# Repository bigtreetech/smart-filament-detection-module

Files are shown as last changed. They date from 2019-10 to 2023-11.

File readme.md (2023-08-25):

## BigTreeTech SFS V1.0

### Firmware Config for `Filament blockage detection`
  * Marlin
    1. uncomment `#define FILAMENT_RUNOUT_SENSOR`.<br/>
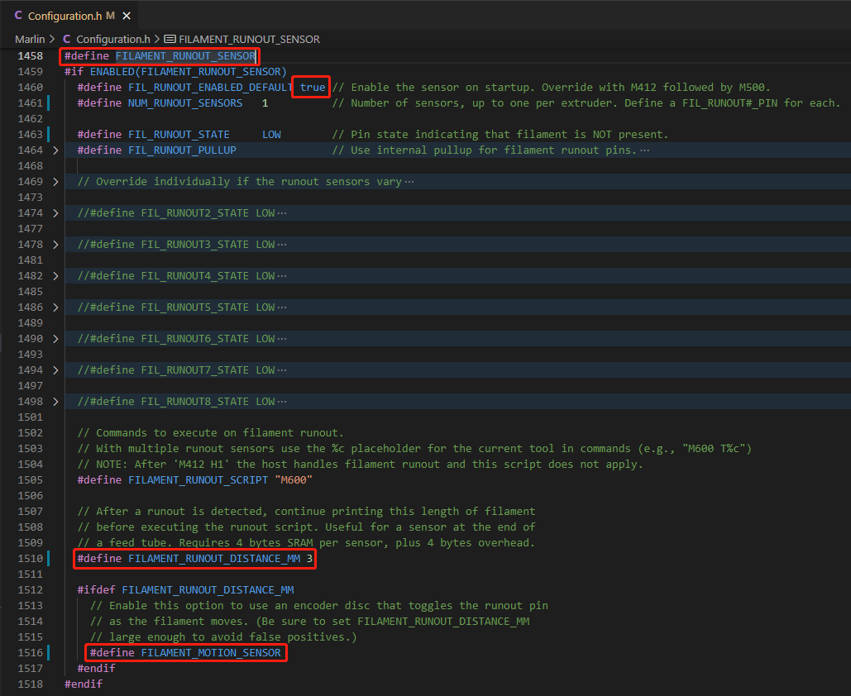
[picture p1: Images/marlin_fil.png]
       <br/>
    2. uncomment `#define FILAMENT_RUNOUT_DISTANCE_MM 7` and set it to 7mm (The detection accuracy of SFS V1.0 is 7mm).
    3. uncomment `#define FILAMENT_MOTION_SENSOR`
    4. The filament sensor feature of Marlin also needs to enable `#define NOZZLE_PARK_FEATURE` and `#define ADVANCED_PAUSE_FEATURE`. please uncomment `#define NOZZLE_PARK_FEATURE` and `#define ADVANCED_PAUSE_FEATURE` and set specific parameters according to your printer.
    5. If you are using the Serial Touch Screen of BigTreeTech, please enable the features in Marlin according to the requirements [here](https://github.com/bigtreetech/BIGTREETECH-TouchScreenFirmware#marlin-dependencies)
        * We recommended to plug SFS V1.0 into the motherboard not Touch Screen, In this case, the Marlin configuration is as described above, and the Touch Screen `config.ini` file needs to be set according to [here](https://github.com/bigtreetech/BIGTREETECH-TouchScreenFirmware/blob/f7ccb050a7a2fe78ff5204561113fa0d27b0dd10/Copy%20to%20SD%20Card%20root%20directory%20to%20update/c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)
        * When the SFS V1.0 is plugged into the Touch Screen, comment out `#define FILAMENT_RUNOUT_SENSOR` in Marlin to disable detection of Marlin and uncomment `#define M114_DETAIL` for Touch Screen, And enable detection of Touch Screen in `config.ini` file, set `fil_runout:1` to enable detection and `fil_runout_distance:7` for accuracy.
  * RepRapFirmware
    1. Add `M591 D0 P7 C"zstopmax" L7 R75:125 E22 S1` in `config.g`, changing the endstop pin name according to your motherboard.<br/>
    ***If you are using the Serial Touch Screen of BigTreeTech, The SFS V1.0 of RRF can only be plugged into the motherboard, and Touch Screen does not need additional config for SFS V1.0***
  * Klipper
    ```
    [filament_motion_sensor encoder_sensor]
    detection_length: 7
    #   The minimum length of filament pulled through the sensor to trigger
    #   a state change on the switch_pin
    #   Default is 7 mm.
    extruder: extruder
    #   The name of the extruder section this sensor is associated with.
    #   This parameter must be provided.
    switch_pin: PA9
    # changing the switch_pin name according to your motherboard
    #pause_on_runout: True
    #runout_gcode:
    #insert_gcode:
    #event_delay:
    #pause_delay:
    ```

## BigTreeTech SFS V2.0

### Firmware Config for `Filament blockage detection`
  * Marlin
    1. uncomment `#define FILAMENT_RUNOUT_SENSOR`.<br/>
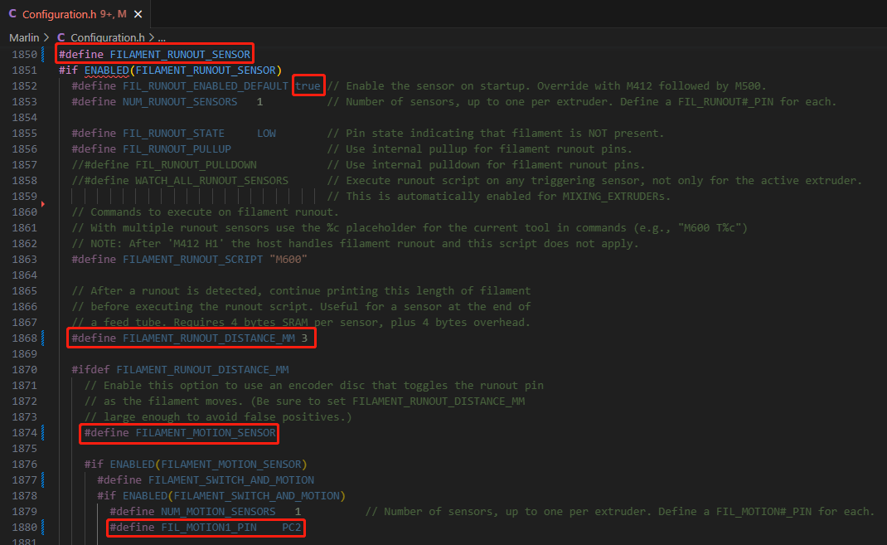
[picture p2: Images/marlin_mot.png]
       <br/>
    2. uncomment `#define FILAMENT_RUNOUT_DISTANCE_MM 3` and set it to 3mm (The detection accuracy of SFS V2.0 is 2.88mm, We set it to 3mm to leave some error margin).
    3. uncomment `#define FILAMENT_MOTION_SENSOR`
    4. uncomment `#define FILAMENT_SWITCH_AND_MOTION`
    5. uncomment `#define FIL_MOTION1_PIN gpio_xx` set motion pin to actual GPIO of motherboard
    6. The filament sensor feature of Marlin also needs to enable `#define NOZZLE_PARK_FEATURE` and `#define ADVANCED_PAUSE_FEATURE`. please uncomment `#define NOZZLE_PARK_FEATURE` and `#define ADVANCED_PAUSE_FEATURE` and set specific parameters according to your printer.
    7. If you are using the Serial Touch Screen of BigTreeTech, please enable the features in Marlin according to the requirements [here](https://github.com/bigtreetech/BIGTREETECH-TouchScreenFirmware#marlin-dependencies)
        * We recommended to plug SFS V2.0 into the motherboard not Touch Screen, In this case, the Marlin configuration is as described above, and the Touch Screen `config.ini` file needs to be set according to [here](https://github.com/bigtreetech/BIGTREETECH-TouchScreenFirmware/blob/f7ccb050a7a2fe78ff5204561113fa0d27b0dd10/Copy%20to%20SD%20Card%20root%20directory%20to%20update/c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)
        * When the SFS V2.0 is plugged into the Touch Screen, comment out `#define FILAMENT_RUNOUT_SENSOR` in Marlin to disable detection of Marlin and uncomment `#define M114_DETAIL` for Touch Screen, And enable detection of Touch Screen in `config.ini` file, set `fil_runout:1` to enable detection and `fil_runout_distance:3` for accuracy.
  * RepRapFirmware
    1. Add `M591 D0 P7 C"zstopmax" L2.88 R75:125 E9 S1` in `config.g`, changing the endstop pin name according to your motherboard.<br/>
    ***If you are using the Serial Touch Screen of BigTreeTech, The SFS V2.0 of RRF can only be plugged into the motherboard, and Touch Screen does not need additional config for SFS V2.0***
  * Klipper
    ```
    [filament_switch_sensor switch_sensor]
    switch_pin: gpio_xx
    pause_on_runout: False
    runout_gcode:
      PAUSE # [pause_resume] is required in printer.cfg
      M117 Filament switch runout
    insert_gcode:
      M117 Filament switch inserted

    [filament_motion_sensor encoder_sensor]
    switch_pin: gpio_xx
    detection_length: 2.88
    extruder: extruder
    pause_on_runout: False
    runout_gcode:
      PAUSE # [pause_resume] is required in printer.cfg
      M117 Filament encoder runout
    insert_gcode:
      M117 Filament encoder inserted
    ```

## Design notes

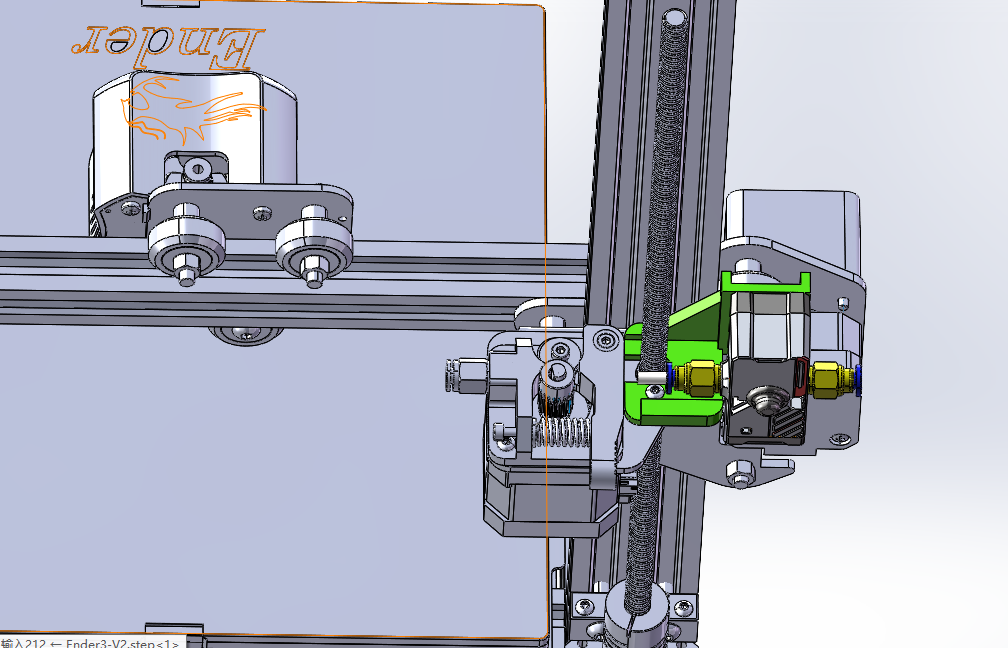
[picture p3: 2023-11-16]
V2.0/Community Mods/Ender3 V2/SFS V2.0 Bracket for Ender3 V2.png

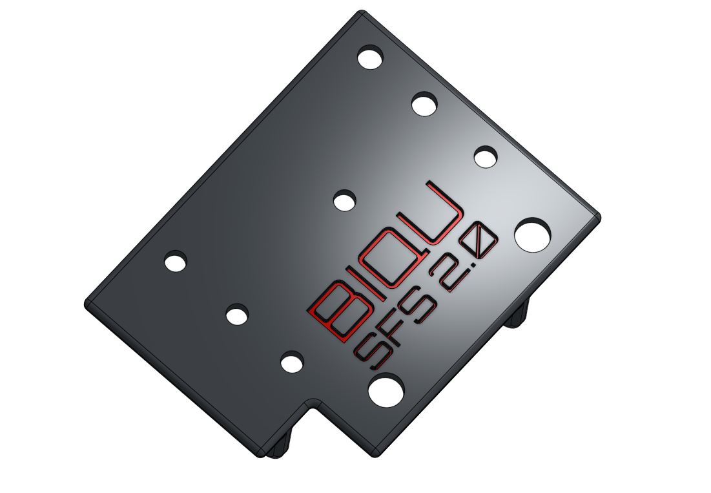
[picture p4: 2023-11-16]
V2.0/Community Mods/Ender3 Max/SFS V2.0 Bracket for Ender3 Max -Pic(4).jpg

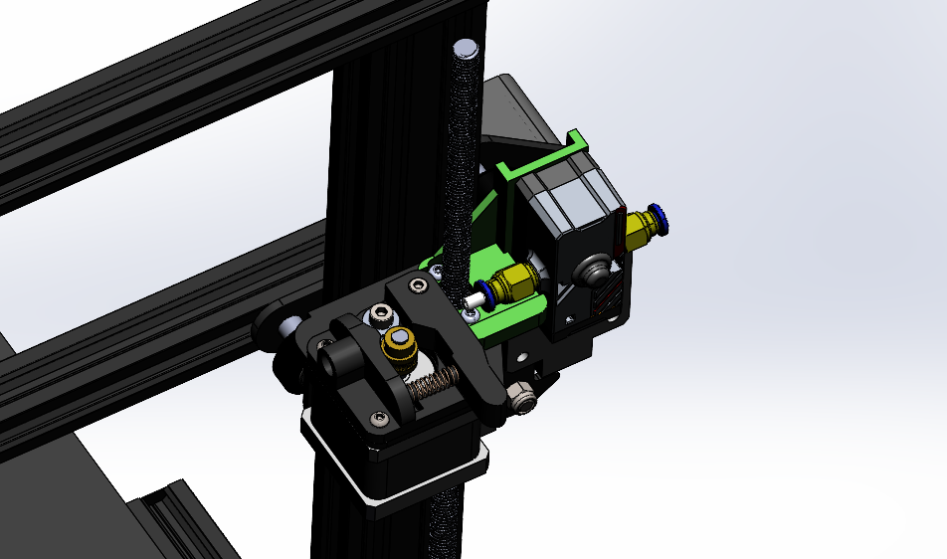
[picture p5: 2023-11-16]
V2.0/Community Mods/Ender3 V1/SFS V2.0 Bracket for Ender3 V1.png

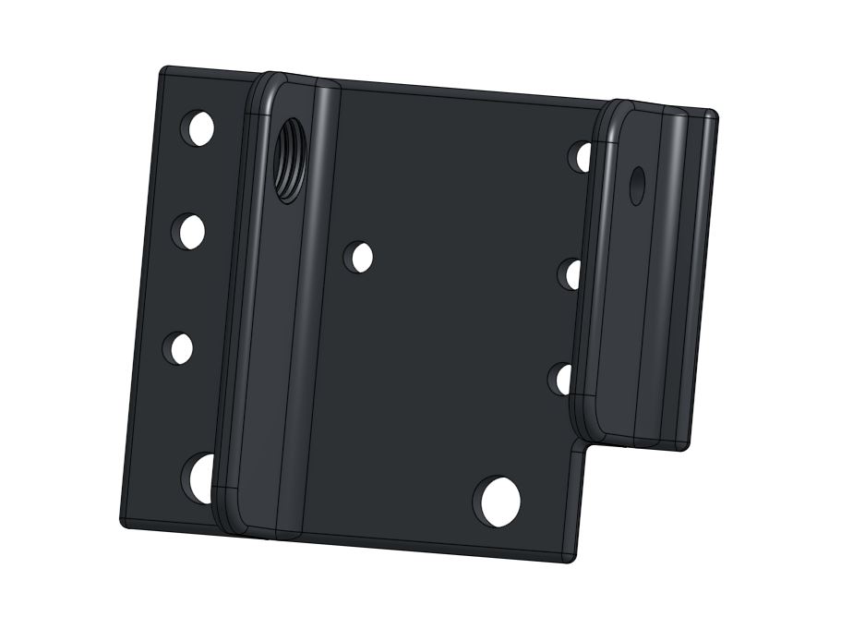
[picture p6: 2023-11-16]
V2.0/Community Mods/Ender3 Max/SFS V2.0 Bracket for Ender3 Max -Pic(1).jpg

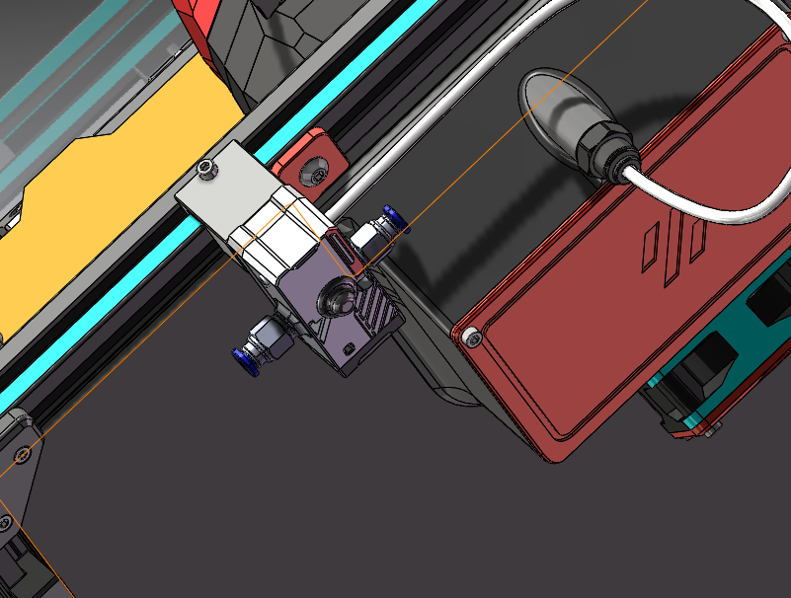
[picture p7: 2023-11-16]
V2.0/Community Mods/Voron2.4/SFS V2.0 Bracket for Voron2.4.png

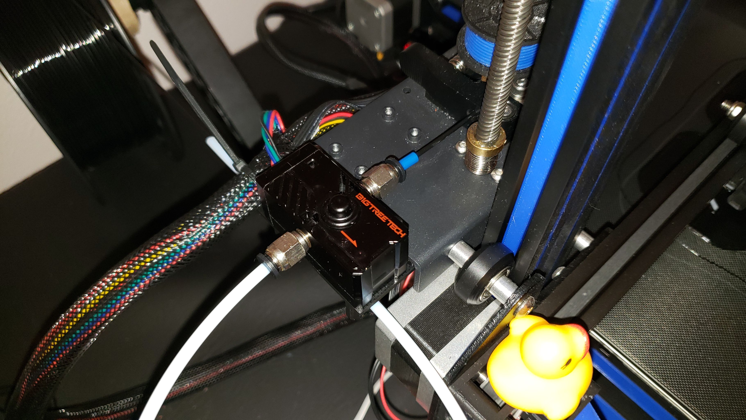
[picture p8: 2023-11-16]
V2.0/Community Mods/Ender3 Max/SFS V2.0 Bracket for Ender3 Max -Pic(3).jpg

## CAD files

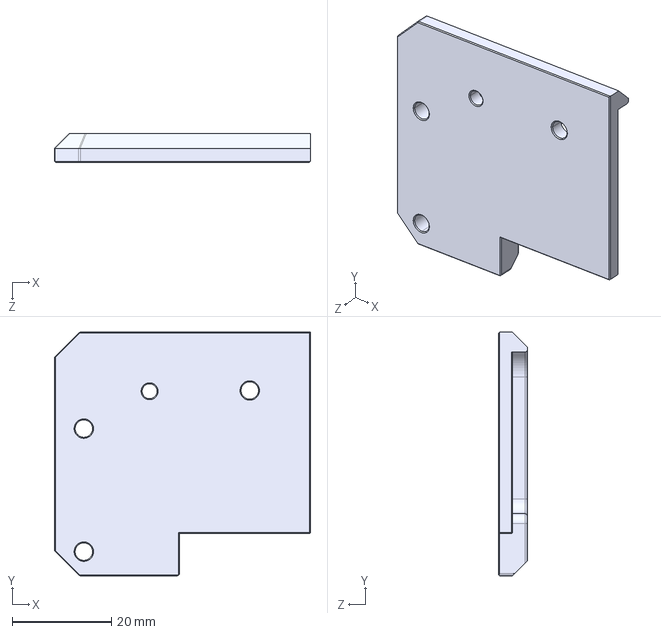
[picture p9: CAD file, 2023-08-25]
V2.0/CAD/SFS V2.0 Bracket for Hurakan.STEP
51.5 x 49.0 x 5.80 mm

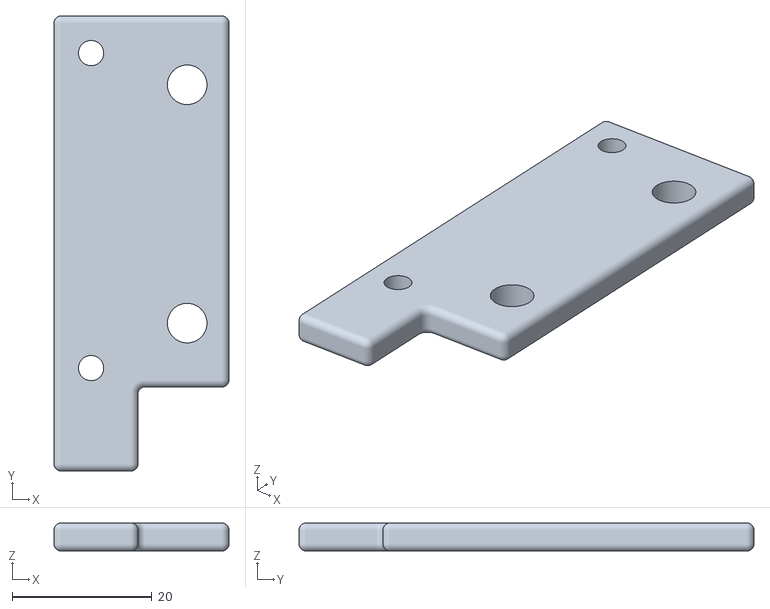
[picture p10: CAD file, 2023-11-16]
V2.0/Community Mods/Ender3 Max/SFS V2.0 Mount-Spacer for Ender3 Max.stl
25.0 x 65.0 x 4.00

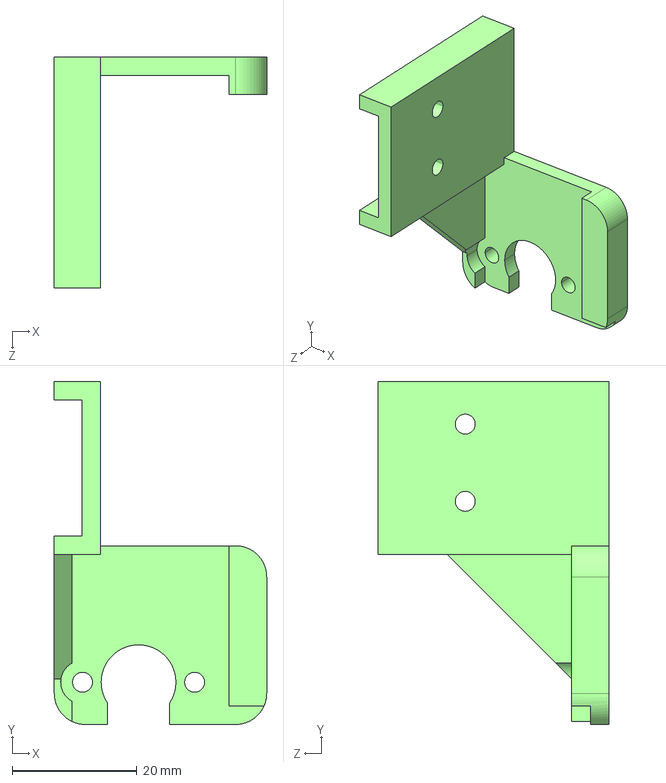
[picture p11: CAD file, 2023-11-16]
V2.0/Community Mods/Ender3 V1/SFS V2.0 Bracket for Ender3 V1.STEP
34.1 x 55.1 x 37.1 mm

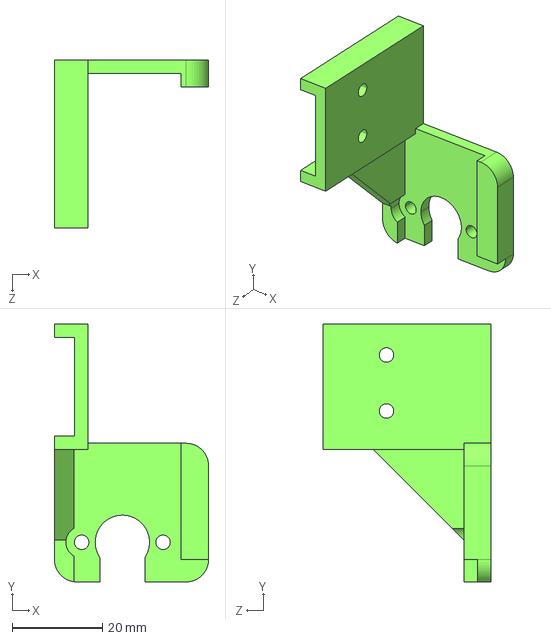
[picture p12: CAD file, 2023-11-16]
V2.0/Community Mods/Ender3 V2/SFS V2.0 Bracket for Ender3 V2.STEP
34.1 x 57.1 x 37.1 mm

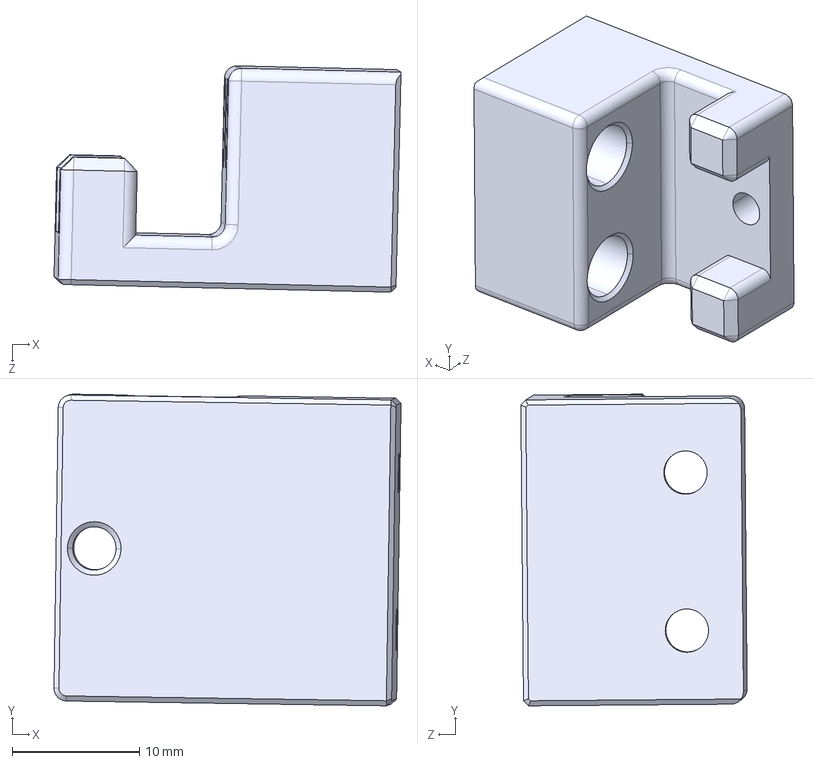
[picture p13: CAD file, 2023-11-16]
V2.0/Community Mods/Voron2.4/SFS V2.0 Bracket for Voron2.4.STEP
27.2 x 24.4 x 17.8 mm

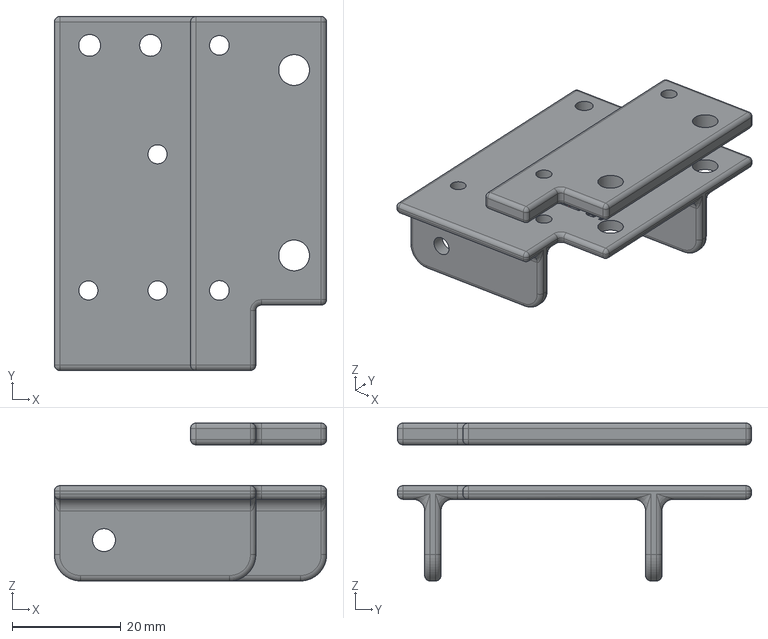
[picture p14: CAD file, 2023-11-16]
V2.0/Community Mods/Ender3 Max/SFS V2.0 Mount for Ender3 Max.step
50.0 x 65.0 x 29.0 mm

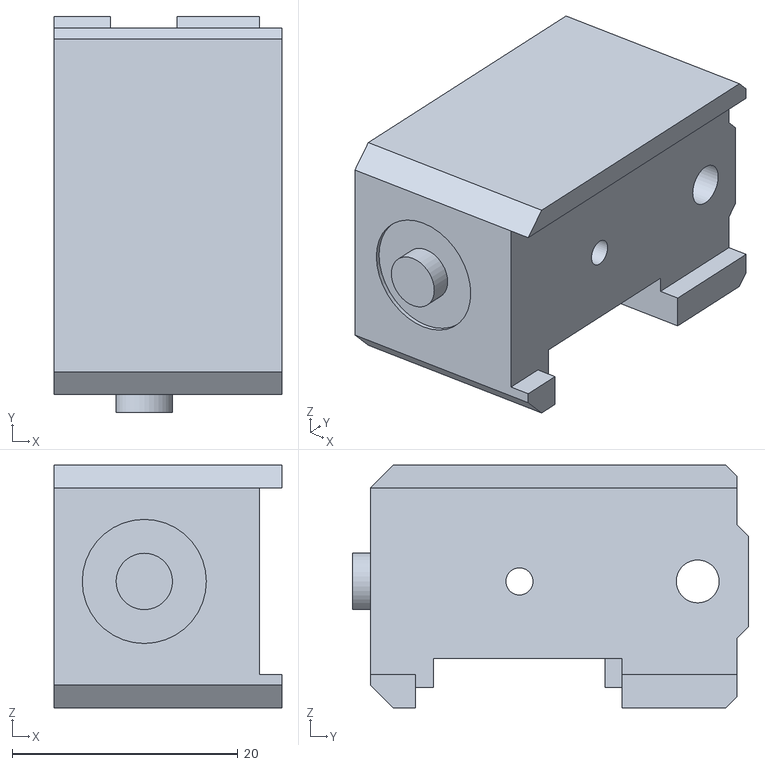
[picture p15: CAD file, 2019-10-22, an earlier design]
V1.0/STL/智能耗材检测模块-滑块1018.STL
20.2 x 35.1 x 21.5

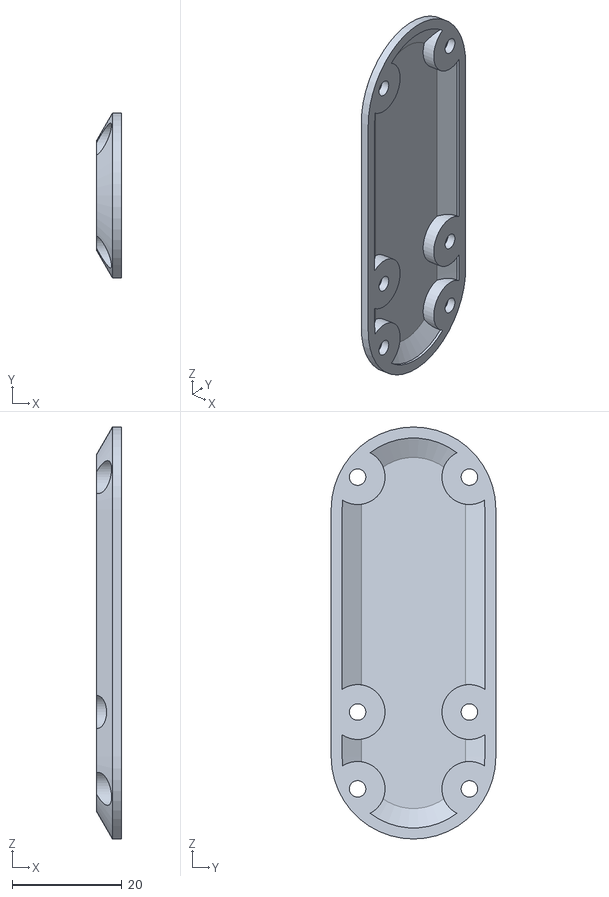
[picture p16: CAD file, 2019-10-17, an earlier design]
V1.0/STL/智能耗材检测模块-底盖0729.STL
4.55 x 30.0 x 75.0

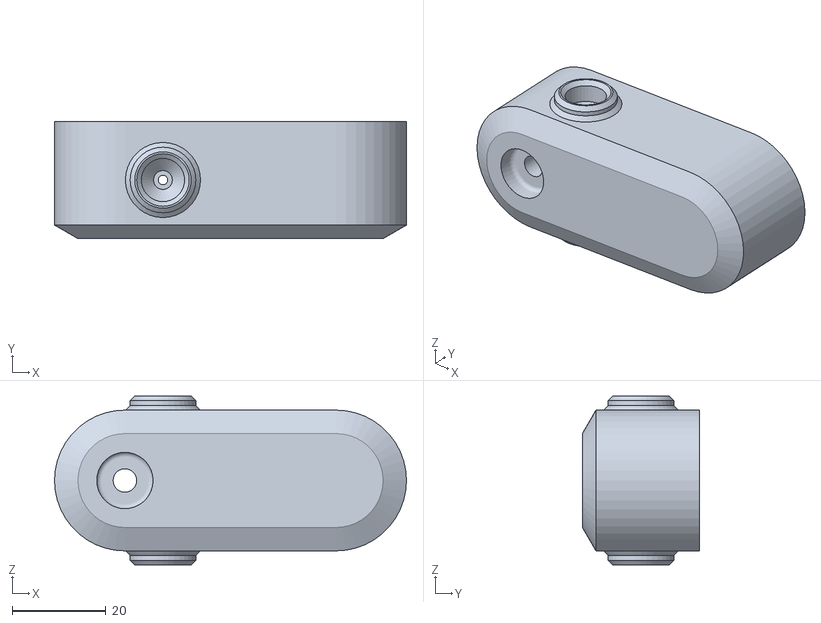
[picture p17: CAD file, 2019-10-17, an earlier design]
V1.0/STL/智能耗材检测模块-外壳0918.STL
75.0 x 25.0 x 36.0

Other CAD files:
V2.0/Community Mods/Ender3 V1/SFS V2.0 Bracket for Ender3 V1.STL
V2.0/Community Mods/Ender3 V2/SFS V2.0 Bracket for Ender3 V2.STL
V2.0/Community Mods/Voron2.4/SFS V2.0 Bracket for Voron2.4.STL
V2.0/STL/SFS V2.0 Bracket for Hurakan.STL

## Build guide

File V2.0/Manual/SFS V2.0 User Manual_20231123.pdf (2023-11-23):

# SFS V2.0

# User Manual

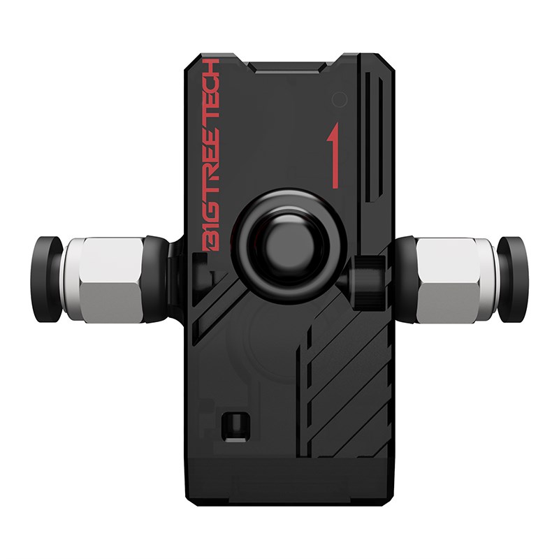
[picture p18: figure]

BIGTREETECH SFS V2.0 User Manual

2

## Revision Log

Version | Date | Revisions
v1.00 | 10th February 2023 | Initial Version
v1.10 | 16th November | 1. Wiring diagrams and Klipper
| 2023 | configuration instructions have been
added for the following boards:

Octopus V1.1/Pro V1.0.1/Pro V1.1/MAX EZ

SKR MINI E3 V3.0

MANTA E3EZ/M5P/M8P V1.0, V2.0

2. The Calibration guide has been added.

3

## CONTENTS

4

## Product Profile

SFS V2.0 is a smart filament sensor that enhances 3D printing reliability by leveraging a highly accurate photoelectric sensor to detect problematic filament issues like runout, tying, and clogging.

Feature Highlights

1. The SFS V2.0 is bi-directional, there is no restriction on filament direction, giving the users more flexibility during installation.
2. It detects extrusion errors caused by filament runout, nozzle clogging, filament tying, and extruder trouble. It has two signal outputs and indicator lights to distinguish between clogging or filament runout.
3. Works with Marlin, Klipper, and RRF firmware.
4. Compact, lightweight, and easy to install.
5. Works with Bowden extruders and direct-drive extruders.
6. Support motherboards with available endstop ports or dedicated filament runout ports.

Instruction

The filament can be threaded through either side of the SFS V2.0, as directionality does not affect functionality.

The red light will illuminate when there is no filament in the module.

The blue light will flash when the extrusion is normal.

The blue light will stay on or off when there is no extrusion.

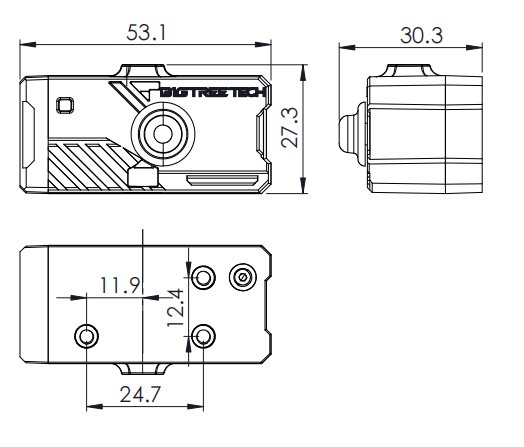
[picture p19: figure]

5

## Specifications

Dimensions: 53.1 x 30.3 x 27.3 mm

Weight: 36 g

Rated Voltage: 3.3V-5V

Working Temperature: -10 to 50 ℃

Working Humidity: 10% to 90%

Filament Diameter: 1.75mm

Mounting Hole Spacing: 12.4 x 24.7 mm

Detection Length: 2.88 mm (theoretical detection length, may need adjustment)

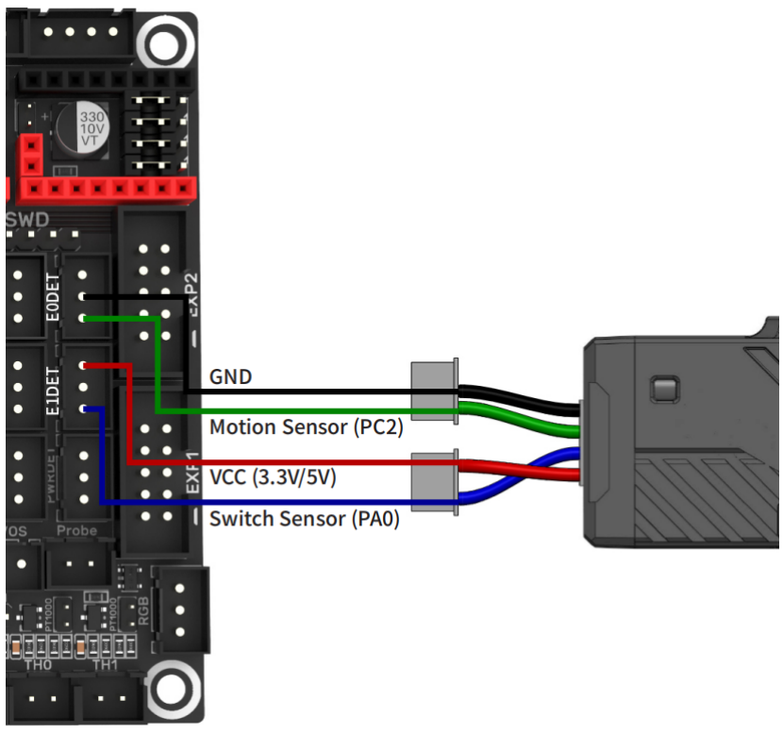
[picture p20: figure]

6

## Wiring

The SFS V2.0 uses a splitting cable, the 3-pin connectors plug into the

motherboard, and the 4-pin connector plugs into the SFS V2.0.

SFS V2.0+SKR3

[filament_switch_sensor switch_sensor] switch_pin: ^PA0
pause_on_runout: False
runout_gcode:
PAUSE # [pause_resume] is required in printer.cfg M117 Filament switch runout
insert_gcode:
M117 Filament switch inserted

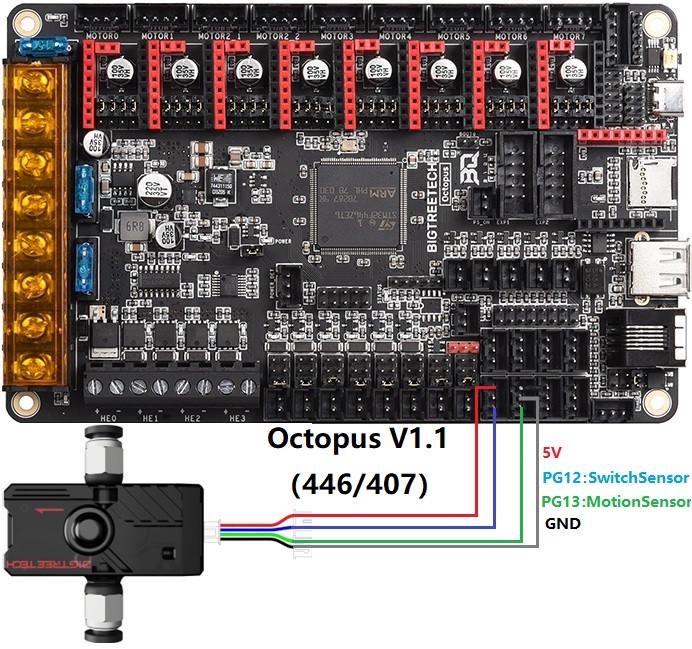
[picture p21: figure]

7

[filament_motion_sensor encoder_sensor]
switch_pin: ^PC2
detection_length: 2.88 # accuracy of motion sensor 2.88mm extruder: extruder
pause_on_runout: False
runout_gcode:
PAUSE # [pause_resume] is required in printer.cfg M117 Filament encoder runout
insert_gcode:
M117 Filament encoder inserted

SFS V2.0+Octopus V1.1

8

[filament_switch_sensor switch_sensor] switch_pin: ^PG12
pause_on_runout: False
runout_gcode:
PAUSE # [pause_resume] is required in printer.cfg M117 Filament switch runout
insert_gcode:
M117 Filament switch inserted

[filament_motion_sensor encoder_sensor]
switch_pin: ^PG13
detection_length: 2.88 # accuracy of motion sensor 2.88mm extruder: extruder
pause_on_runout: False
runout_gcode:
PAUSE # [pause_resume] is required in printer.cfg M117 Filament encoder runout
insert_gcode:
M117 Filament encoder inserted

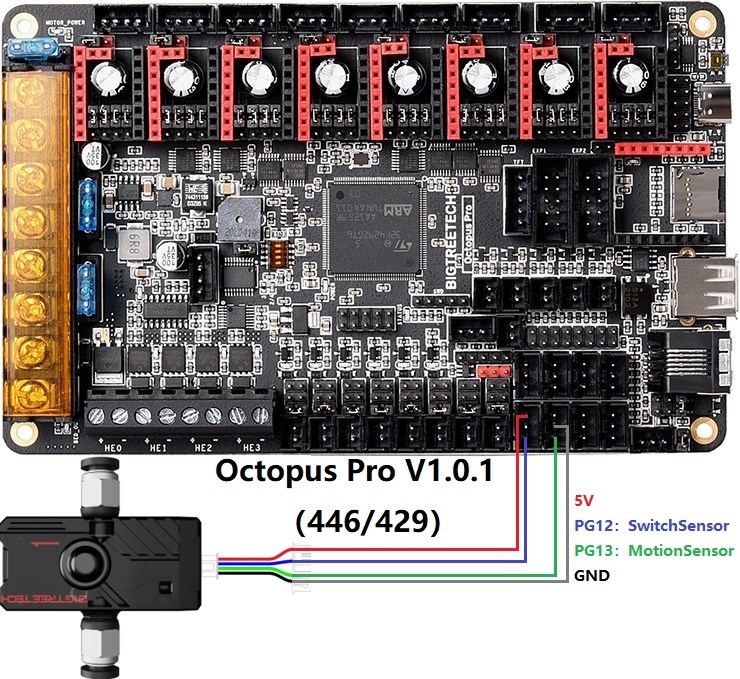
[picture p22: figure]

9

SFS V2.0+Octopus Pro V1.0.1

[filament_switch_sensor switch_sensor] switch_pin: ^PG12
pause_on_runout: False
runout_gcode:
PAUSE # [pause_resume] is required in printer.cfg M117 Filament switch runout
insert_gcode:
M117 Filament switch inserted

[filament_motion_sensor encoder_sensor]
switch_pin: ^PG13
detection_length: 2.88 # accuracy of motion sensor 2.88mm extruder: extruder
pause_on_runout: False
runout_gcode:

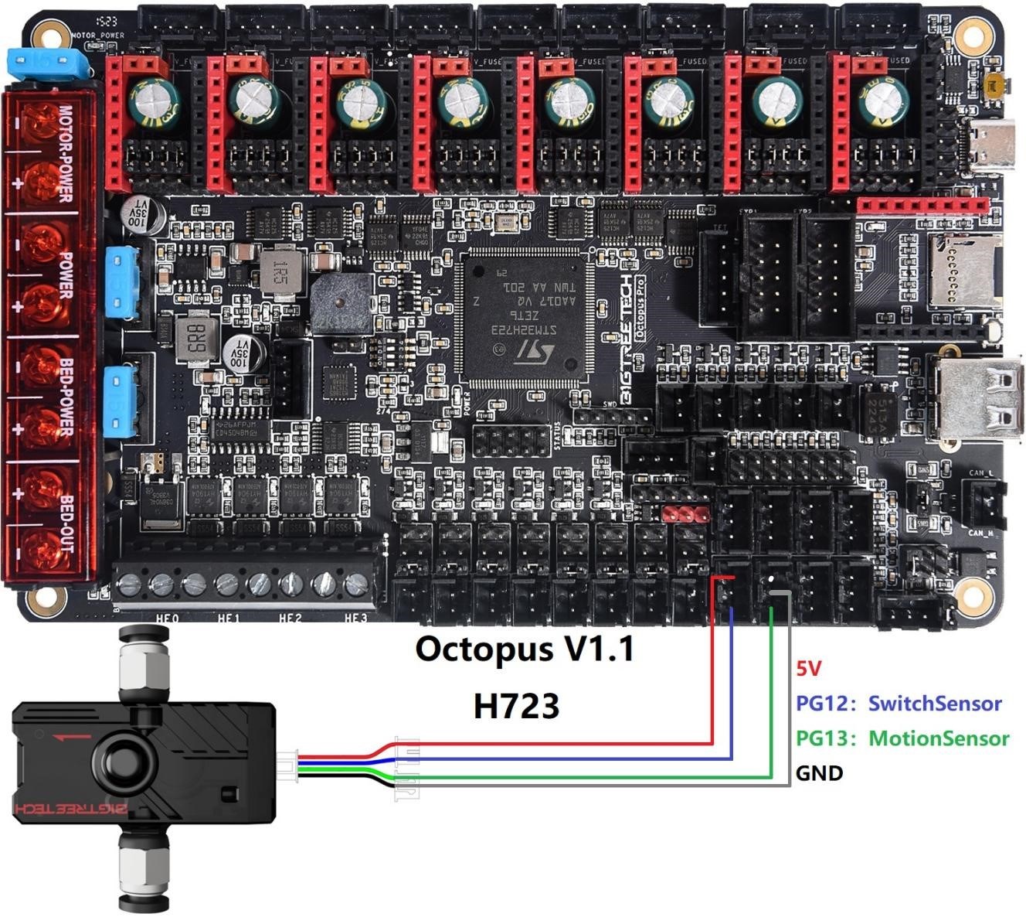
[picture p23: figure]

10

PAUSE # [pause_resume] is required in printer.cfg M117 Filament encoder runout
insert_gcode:
M117 Filament encoder inserted

SFS V2.0+Octopus Pro V1.1

[filament_switch_sensor switch_sensor] switch_pin: ^PG12
pause_on_runout: False
runout_gcode:
PAUSE # [pause_resume] is required in printer.cfg M117 Filament switch runout
insert_gcode:
M117 Filament switch inserted

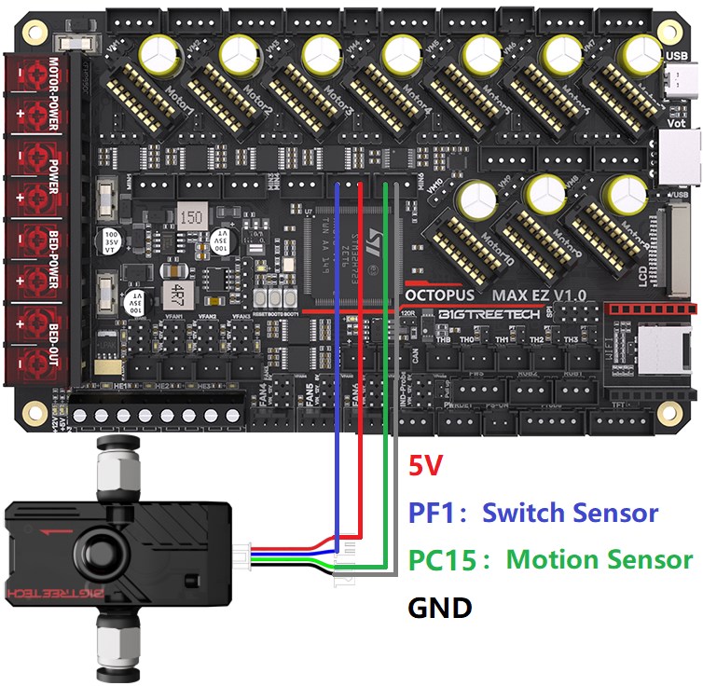
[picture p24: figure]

11

[filament_motion_sensor encoder_sensor]
switch_pin: ^PG13
detection_length: 2.88 # accuracy of motion sensor 2.88mm extruder: extruder
pause_on_runout: False
runout_gcode:
PAUSE # [pause_resume] is required in printer.cfg M117 Filament encoder runout
insert_gcode:
M117 Filament encoder inserted

SFS V2.0+Octopus MAX EZ

12

[filament_switch_sensor switch_sensor] switch_pin: ^PF1
pause_on_runout: False
runout_gcode:
PAUSE # [pause_resume] is required in printer.cfg M117 Filament switch runout
insert_gcode:
M117 Filament switch inserted

[filament_motion_sensor encoder_sensor]
switch_pin: ^PC15

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

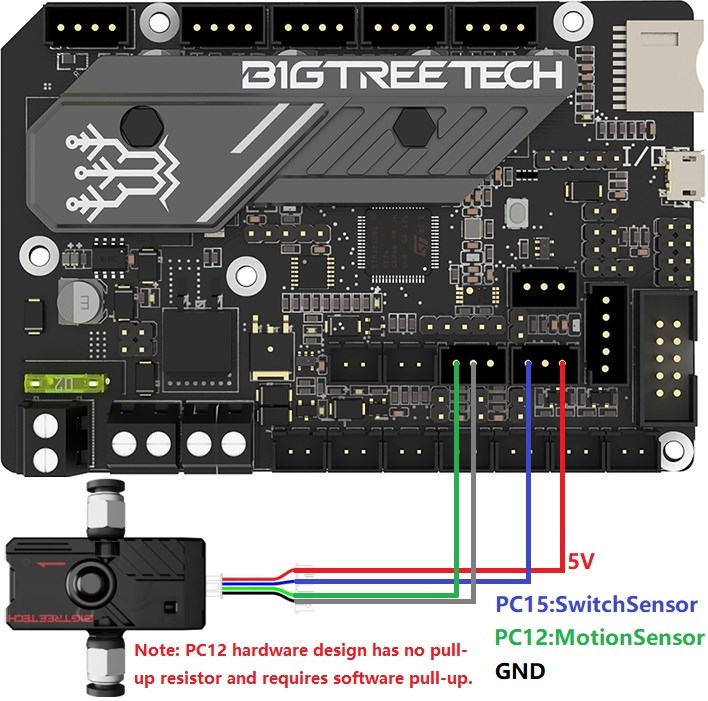
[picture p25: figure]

13

SFS V2.0+SKR MINI E3 V3.0

[filament_switch_sensor switch_sensor] switch_pin: ^PC15
pause_on_runout: False
runout_gcode:
PAUSE # [pause_resume] is required in printer.cfg M117 Filament switch runout
insert_gcode:
M117 Filament switch inserted

[filament_motion_sensor encoder_sensor]
switch_pin: ^PC12
detection_length: 2.88 # accuracy of motion sensor 2.88mm extruder: extruder

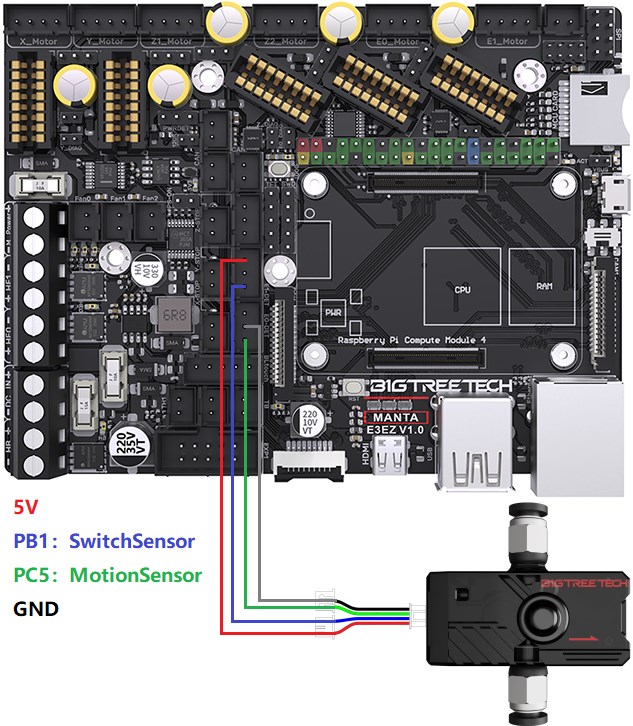
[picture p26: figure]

14

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

SFS V2.0+E3EZ

15

[filament_switch_sensor switch_sensor] switch_pin: ^PB1
pause_on_runout: False
runout_gcode:
PAUSE # [pause_resume] is required in printer.cfg M117 Filament switch runout
insert_gcode:
M117 Filament switch inserted

[filament_motion_sensor encoder_sensor]
switch_pin: ^PC5
detection_length: 2.88 # accuracy of motion sensor 2.88mm extruder: extruder
pause_on_runout: False
runout_gcode:
PAUSE # [pause_resume] is required in printer.cfg M117 Filament encoder runout
insert_gcode:
M117 Filament encoder inserted

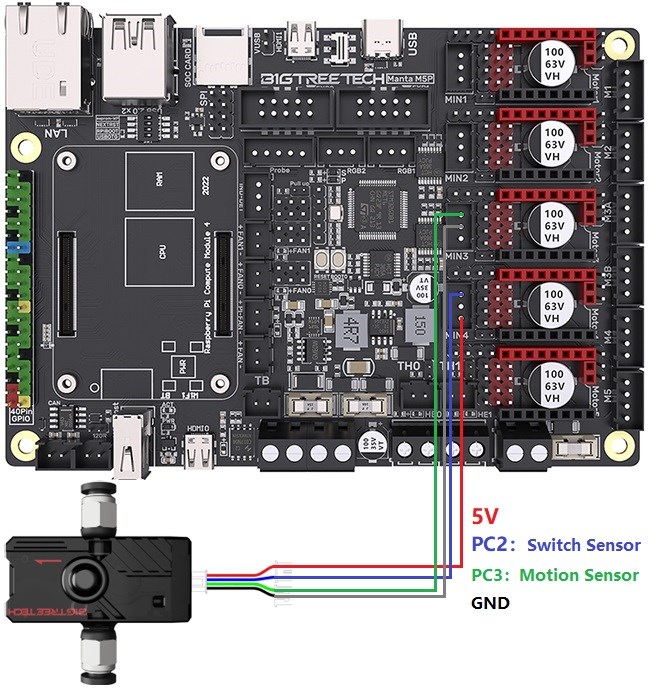
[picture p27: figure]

16

SFS V2.0+MANTA M5P

[filament_switch_sensor switch_sensor] switch_pin: ^PC2
pause_on_runout: False
runout_gcode:
PAUSE # [pause_resume] is required in printer.cfg M117 Filament switch runout
insert_gcode:
M117 Filament switch inserted

[filament_motion_sensor encoder_sensor] switch_pin: ^PC3

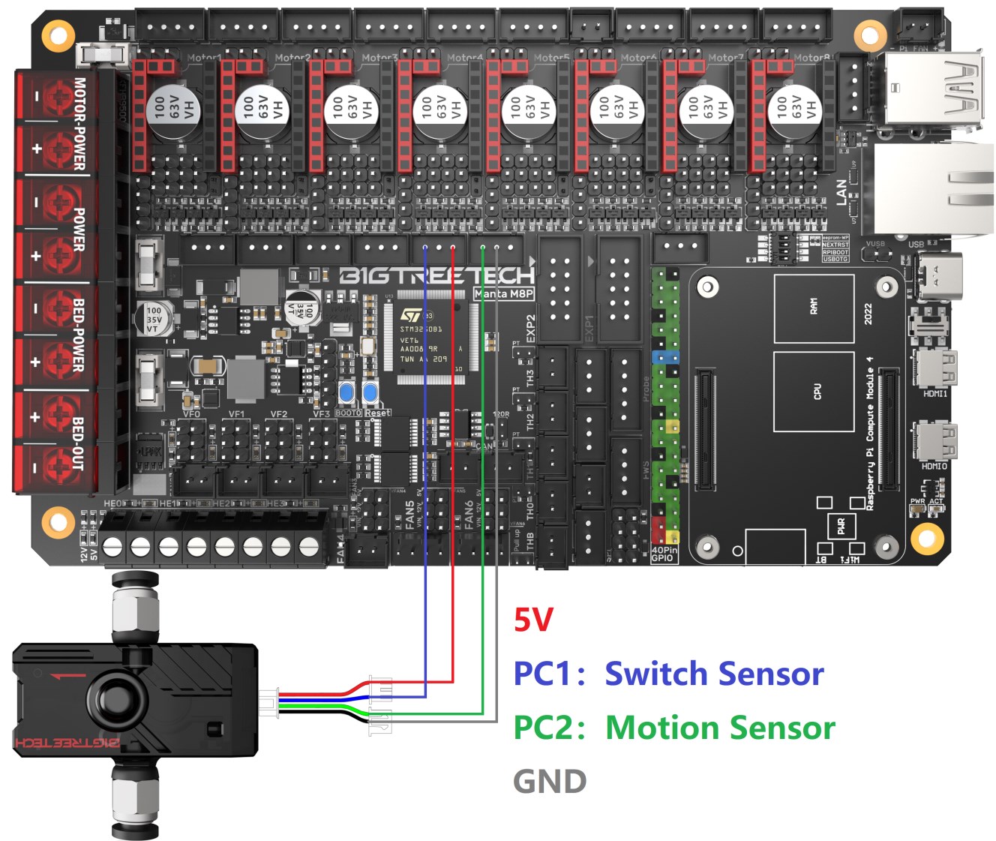
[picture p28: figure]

17

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

SFS V2.0+MANTA M8P V1.0/V1.1

[filament_switch_sensor switch_sensor] switch_pin: ^PC1
pause_on_runout: False
runout_gcode:
PAUSE # [pause_resume] is required in printer.cfg

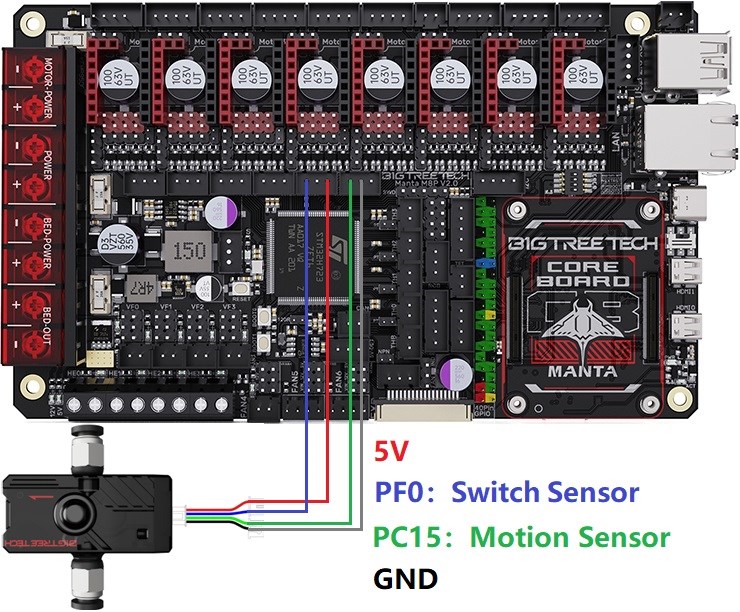
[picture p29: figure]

18

M117 Filament switch runout insert_gcode:
M117 Filament switch inserted

[filament_motion_sensor encoder_sensor]
switch_pin: ^PC2
detection_length: 2.88 # accuracy of motion sensor 2.88mm extruder: extruder
pause_on_runout: False
runout_gcode:
PAUSE # [pause_resume] is required in printer.cfg M117 Filament encoder runout
insert_gcode:
M117 Filament encoder inserted

SFS V2.0+MANTA M8P V2.0

19

[filament_switch_sensor switch_sensor] switch_pin: ^PF0
pause_on_runout: False
runout_gcode:
PAUSE # [pause_resume] is required in printer.cfg M117 Filament switch runout
insert_gcode:
M117 Filament switch inserted

[filament_motion_sensor encoder_sensor]
switch_pin: ^PC15
detection_length: 2.88 # accuracy of motion sensor 2.88mm extruder: extruder
pause_on_runout: False
runout_gcode:
PAUSE # [pause_resume] is required in printer.cfg M117 Filament encoder runout
insert_gcode:
M117 Filament encoder inserted

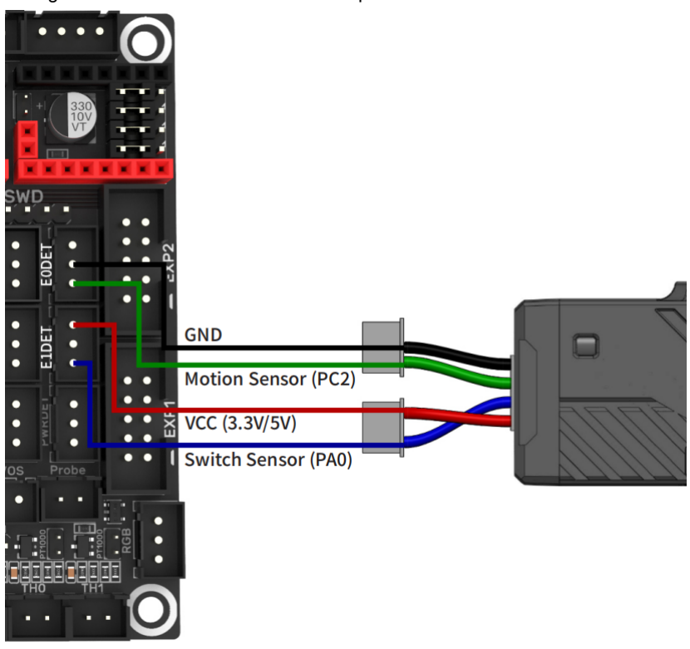
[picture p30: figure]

20

## Firmware Modification

1. The signal output of the switch sensor is at low level when no filament is detected, IO pin should be set to pull_up input.
2. The signal output of motion sensor changes level at every 2.88mm of filament movement, the IO pin should also be set to pull_up input.
For details: https://github.com/bigtreetech/smart-filament-detection-module

Taking the SKR3 motherboard as an example:

### 1. Klipper

[filament_switch_sensor switch_sensor]
switch_pin: ^PA0 # switch sensor IO is PA0 pause_on_runout: False runout_gcode:
PAUSE # [pause_resume] is required in printer.cfg
M117 Filament switch runout

21

insert_gcode:
M117 Filament switch inserted

References:

https://www.klipper3d.org/Config_Reference.html#filament_switch_sensor

[filament_motion_sensor encoder_sensor]
switch_pin: ^PC2 # motion sensor IO is PC2

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

References:

https://www.klipper3d.org/Config_Reference.html#filament_motion_sensor

Note: 2.88 mm is the minimum detection length required for the sensor to function properly. If you encounter problem of false triggers, try increasing the detection length by 1mm increments until the problem is resolved.

### 2. Marlin

On Marlin, an extruder can only correspond to one filament detection, so we choose "motion sensor", follow the steps below to enable the motion sensor (Note: It is necessary to check whether the FIL_RUNOUT_PIN in the pin file of the motherboard is the same as the actual motion sensor connecting pin).

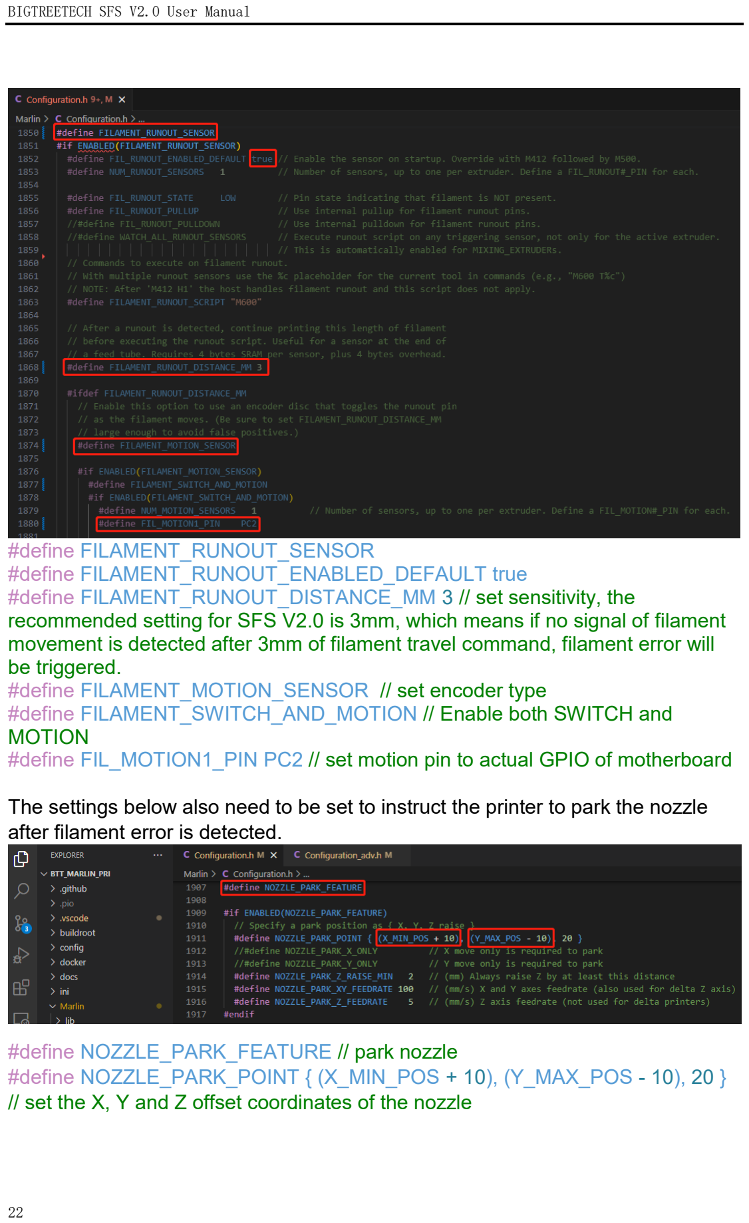
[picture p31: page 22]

22

#define FILAMENT_RUNOUT_SENSOR

#define FILAMENT_RUNOUT_ENABLED_DEFAULT true

#define FILAMENT_RUNOUT_DISTANCE_MM 3 // set sensitivity, the recommended setting for SFS V2.0 is 3mm, which means if no signal of filament movement is detected after 3mm of filament travel command, filament error will be triggered.

#define FILAMENT_MOTION_SENSOR // set encoder type

#define FILAMENT_SWITCH_AND_MOTION // Enable both SWITCH and MOTION

#define FIL_MOTION1_PIN PC2 // set motion pin to actual GPIO of motherboard

The settings below also need to be set to instruct the printer to park the nozzle after filament error is detected.

#define NOZZLE_PARK_FEATURE // park nozzle

#define NOZZLE_PARK_POINT { (X_MIN_POS + 10), (Y_MAX_POS - 10), 20 } // set the X, Y and Z offset coordinates of the nozzle

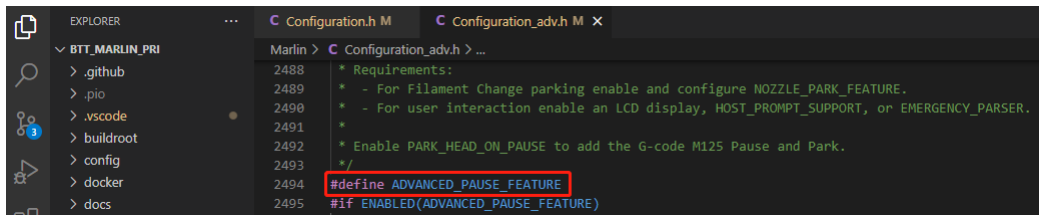
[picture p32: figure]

23

#define ADVANCED_PAUSE_FEATURE // retraction setting of nozzle park movement and filament purge distance after the print is resumed.

### 3. RRF

M591 D0 P7 C"e0stop" L2.88 R75:125 E9 S1; accuracy of motion sensor is 2.88mm, motion sensor pin: e0stop

24

## Calibration

The theoretical detection length of 2.88mm is the amount of filament that will be extruded between each pulse of the signal. This means that if no filament movement signal is detected after 2.88mm of filament travel command, a filament error will be triggered.

Setting the detection distance to exactly 2.88mm may likely cause false triggers or errors. You can treat this parameter as the sensitivity of the sensor, the higher the number, the less sensitive the sensor will be.

The detection length needs to be adjusted depending on the mounting location of your SFS V2.0. The further away from the extruder, the higher the number will need to be. We recommend a starting point of 3mm. If you keep getting false triggers, increase the detection length by 1mm increments until the problem is resolved.

25

## Caution

1) Power supply: 3.3V or 5V, please note that any higher voltage will cause damage.
2) The housing can be damaged if quick connectors are tightened frequently or incorrectly.
3) To connect to a motherboard without dedicated filament runout port, please consult our technical support.

If you need further resources for this product, you can find them at [GitHub](https://github.com/bigtreetech/). If you cannot find what you need, you may contact our after-sales support(service005@biqu3d.com).

If you encounter any other problems during use or have suggestions or feedback, please contact us. Thank you for choosing BIGTREETECH products.

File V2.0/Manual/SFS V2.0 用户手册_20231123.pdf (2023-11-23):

# SFS V2.0

# 用户手册


BIGTREETECH SFS V2.0 用户手册

2

## 修订历史

版本 | 日期 | 修改说明
v1.00 | 2023/02/10 | 初稿
v1.10 | 2023/11/16 | 1. 增加以下主板连线图示与 Klipper 配
置说明：

Octopus V1.1/Pro V1.0.1/Pro V1.1/MAX EZ

SKR MINI E3 V3.0

MANTA E3EZ/M5P/M8P V1.0, V2.0

2. 增加校准指南。

3

目录

4

## 一、产品简介

SFS V2.0 是一款智能耗材检测器，通过采用高精度的光电感应技术来检测耗材故 障问题，如耗材断料、耗材缠绕和喷嘴堵塞，从而提高 3D 打印过程的稳定性。

### 1.1 功能特点

- 耗材通过耗材检测模块没有方向要求，不受耗材安装方向的限制。
- 能检测出耗材断料、喷嘴堵塞、耗材缠绕、挤出机故障所引起的耗材异常挤出的情 况。并且针对不同的问题具有相对应的灯光和屏幕显示进行提醒。
- 适用于 Marlin、Klipper 和 RRF 固件。
- 体积小、较为轻便，方便安装。
- 支持远程挤出机和近程挤出机。
- 支持留有断料检测接口的主板。

### 1.2 使用说明

将耗材从智能耗材检测模块任意方向的直通快接头插入;

没有耗材通过时，模块上的红灯亮；正常打印或出料时，模块上的蓝灯闪烁。挤出机无动 作时，模块上的蓝灯常亮或熄灭。


5

## 二、基本参数

体积：53.1×30.3×27.3mm

重量：36g

额定电压：3.3V-5V

工作温度：-10℃~50℃

工作湿度： 10%~90%

检测耗材直径：1.75mm

固定孔位间距：12.4x24.7mm

检测长度：2.88mm （理论检测长度，可能需要调整）

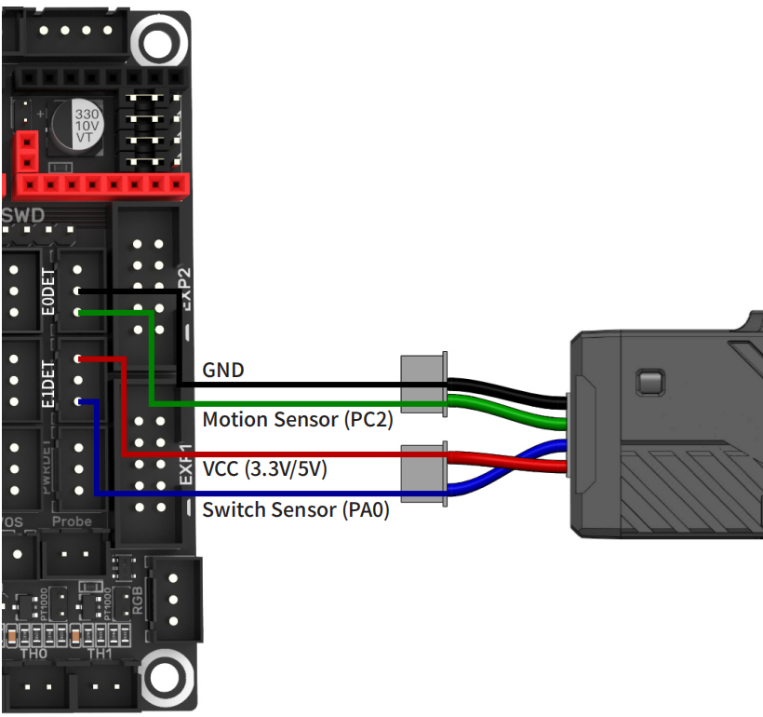
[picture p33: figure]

6

## 三、接线

智能耗材检测模块的数据线是由一个 4P 端子分成两个 3P 端子组成，4P 端子插入到智能耗 材检测模块内。

### 3.1 SFS V2.0+SKR3

[filament_switch_sensor switch_sensor] switch_pin: ^PA0
pause_on_runout: False
runout_gcode:
PAUSE # 配置文件中需要配置 [pause_resume] M117 Filament switch runout
insert_gcode:
M117 Filament switch inserted


7

[filament_motion_sensor encoder_sensor] switch_pin: ^PC2
detection_length: 2.88 # 堵料检测的精度为 2.88mm extruder: extruder
pause_on_runout: False
runout_gcode:
PAUSE # 配置文件中需要配置 [pause_resume] M117 Filament encoder runout
insert_gcode:
M117 Filament encoder inserted

### 3.2 SFS V2.0+Octopus V1.1

8

[filament_switch_sensor switch_sensor] switch_pin: ^PG12
pause_on_runout: False
runout_gcode:
PAUSE # 配置文件中需要配置 [pause_resume] M117 Filament switch runout
insert_gcode:
M117 Filament switch inserted

[filament_motion_sensor encoder_sensor] switch_pin: ^PG13
detection_length: 2.88 # 堵料检测的精度为 2.88mm extruder: extruder
pause_on_runout: False
runout_gcode:
PAUSE # 配置文件中需要配置 [pause_resume] M117 Filament encoder runout
insert_gcode:
M117 Filament encoder inserted


9

### 3.3 SFS V2.0+Octopus Pro V1.0.1

[filament_switch_sensor switch_sensor] switch_pin: ^PG12
pause_on_runout: False
runout_gcode:
PAUSE # 配置文件中需要配置 [pause_resume] M117 Filament switch runout
insert_gcode:
M117 Filament switch inserted

[filament_motion_sensor encoder_sensor] switch_pin: ^PG13
detection_length: 2.88 # 堵料检测的精度为 2.88mm extruder: extruder
pause_on_runout: False
runout_gcode:


10

PAUSE # 配置文件中需要配置 [pause_resume] M117 Filament encoder runout
insert_gcode:
M117 Filament encoder inserted

### 3.4 SFS V2.0+Octopus Pro V1.1

[filament_switch_sensor switch_sensor] switch_pin: ^PG12
pause_on_runout: False
runout_gcode:
PAUSE # 配置文件中需要配置 [pause_resume] M117 Filament switch runout

11

insert_gcode:
M117 Filament switch inserted

[filament_motion_sensor encoder_sensor] switch_pin: ^PG13
detection_length: 2.88 # 堵料检测的精度为 2.88mm extruder: extruder
pause_on_runout: False
runout_gcode:
PAUSE # 配置文件中需要配置 [pause_resume] M117 Filament encoder runout
insert_gcode:
M117 Filament encoder inserted


12

### 3.5 SFS V2.0+Octopus MAX EZ

[filament_switch_sensor switch_sensor] switch_pin: ^PF1
pause_on_runout: False
runout_gcode:
PAUSE # 配置文件中需要配置 [pause_resume] M117 Filament switch runout
insert_gcode:
M117 Filament switch inserted

[filament_motion_sensor encoder_sensor] switch_pin: ^PC15


13

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

### 3.6 SFS V2.0+SKR MINI E3 V3.0

[filament_switch_sensor switch_sensor] switch_pin: ^PC15

14

pause_on_runout: False
runout_gcode:
PAUSE # 配置文件中需要配置 [pause_resume] M117 Filament switch runout
insert_gcode:
M117 Filament switch inserted

[filament_motion_sensor encoder_sensor] switch_pin: ^PC12
detection_length: 2.88 # 堵料检测的精度为 2.88mm extruder: extruder
pause_on_runout: False
runout_gcode:
PAUSE # 配置文件中需要配置 [pause_resume] M117 Filament encoder runout
insert_gcode:
M117 Filament encoder inserted


15

### 3.7 SFS V2.0+E3EZ

[filament_switch_sensor switch_sensor] switch_pin: ^PB1
pause_on_runout: False
runout_gcode:
PAUSE # 配置文件中需要配置 [pause_resume] M117 Filament switch runout
insert_gcode:
M117 Filament switch inserted

16

[filament_motion_sensor encoder_sensor] switch_pin: ^PC5
detection_length: 2.88 # 堵料检测的精度为 2.88mm extruder: extruder
pause_on_runout: False
runout_gcode:
PAUSE # 配置文件中需要配置 [pause_resume] M117 Filament encoder runout
insert_gcode:
M117 Filament encoder inserted


17

### 3.8 SFS V2.0+MANTA M5P

[filament_switch_sensor switch_sensor] switch_pin: ^PC2
pause_on_runout: False
runout_gcode:
PAUSE # 配置文件中需要配置 [pause_resume] M117 Filament switch runout
insert_gcode:
M117 Filament switch inserted

[filament_motion_sensor encoder_sensor] switch_pin: ^PC3


18

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

### 3.9 SFS V2.0+MANTA M8P V1.0/V1.1

[filament_switch_sensor switch_sensor] switch_pin: ^PC1
pause_on_runout: False
runout_gcode:


19

PAUSE # 配置文件中需要配置 [pause_resume] M117 Filament switch runout
insert_gcode:
M117 Filament switch inserted

[filament_motion_sensor encoder_sensor] switch_pin: ^PC2
detection_length: 2.88 # 堵料检测的精度为 2.88mm extruder: extruder
pause_on_runout: False
runout_gcode:
PAUSE # 配置文件中需要配置 [pause_resume] M117 Filament encoder runout
insert_gcode:
M117 Filament encoder inserted

### 3.10 SFS V2.0+MANTA M8P V2.0

20

[filament_switch_sensor switch_sensor] switch_pin: ^PF0
pause_on_runout: False
runout_gcode:
PAUSE # 配置文件中需要配置 [pause_resume] M117 Filament switch runout
insert_gcode:
M117 Filament switch inserted

[filament_motion_sensor encoder_sensor] switch_pin: ^PC15
detection_length: 2.88 # 堵料检测的精度为 2.88mm extruder: extruder
pause_on_runout: False
runout_gcode:
PAUSE # 配置文件中需要配置 [pause_resume] M117 Filament encoder runout
insert_gcode:
M117 Filament encoder inserted

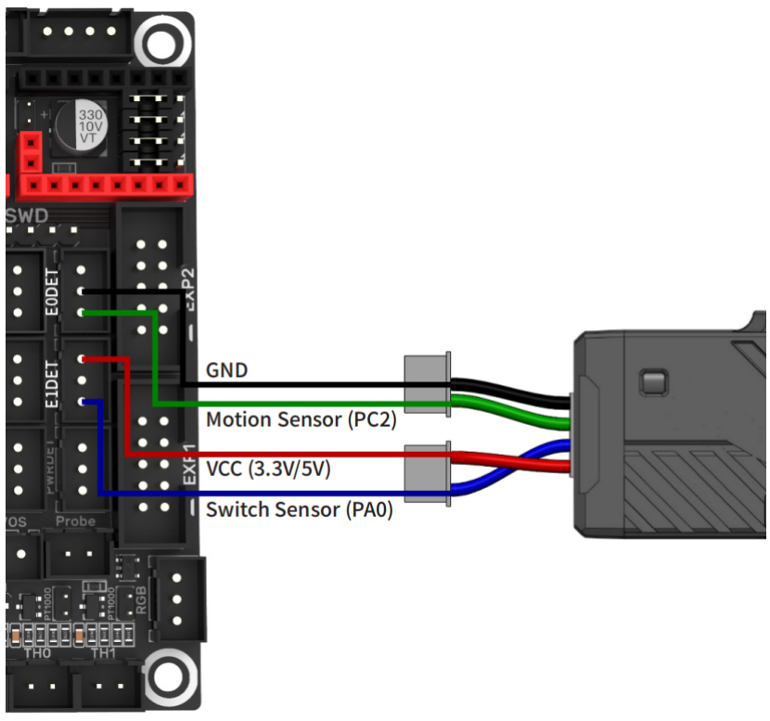
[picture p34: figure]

21

## 四、固件修改

1) 断料检测没有耗材的时候是低电平，IO 引脚需要设置为上拉输入(Pull-up input)。
2) 堵料检测耗材每移动 2.88mm 电平跳变一次，IO 引脚也需要设置为上拉输入(Pull-up input)。
更详细的内容参考：https://github.com/bigtreetech/smart-filament-detection-module

下图以 SKR3 为例：

### 4.1 Klipper

[filament_switch_sensor switch_sensor]
switch_pin: ^PA0 # 断料检测 IO 为 PA0 pause_on_runout: False runout_gcode:
PAUSE # 配置文件中需要配置 [pause_resume]
M117 Filament switch runout

22

insert_gcode:
M117 Filament switch inserted

References:

https://www.klipper3d.org/Config_Reference.html#filament_switch_sensor

[filament_motion_sensor encoder_sensor]
switch_pin: ^PC2 # 堵料检测 IO 为 PC2

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

参考：https://www.klipper3d.org/Config_Reference.html#filament_motion_sensor

注意：2.88 mm 是该智能耗材检测模块正常工作所需要的最小检测长度。如果你遇到了误 触发的问题，试着增加 1 mm 的检测长度直到问题解决。

### 4.2 Marlin

Marlin 一个挤出机只能对应一个耗材检测，所以我们选用“堵料检测”，按照如下步骤使 能堵料检测功能（注意：需要检测所用主板 pin 文件中的 FIL_RUNOUT_PIN 是否与实际接 的堵料检测信号线一致）

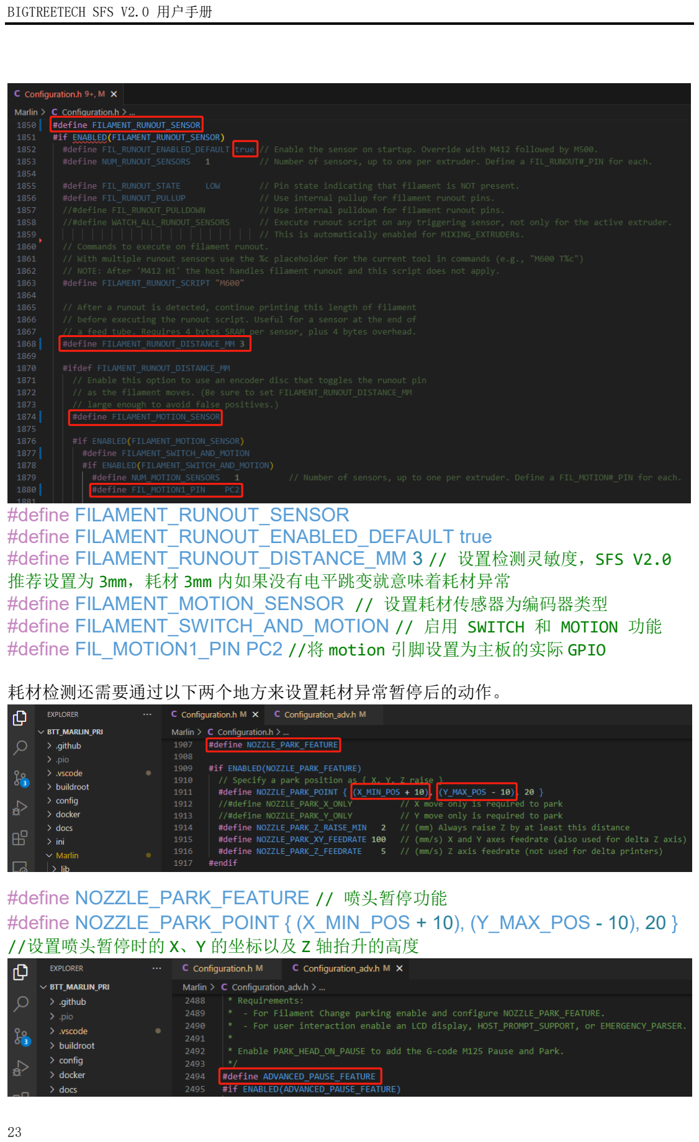
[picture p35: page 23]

23

#define FILAMENT_RUNOUT_SENSOR

#define FILAMENT_RUNOUT_ENABLED_DEFAULT true

#define FILAMENT_RUNOUT_DISTANCE_MM 3 // 设置检测灵敏度，SFS V2.0 推荐设置为 3mm，耗材 3mm 内如果没有电平跳变就意味着耗材异常

#define FILAMENT_MOTION_SENSOR // 设置耗材传感器为编码器类型 #define FILAMENT_SWITCH_AND_MOTION // 启用 SWITCH 和 MOTION 功能 #define FIL_MOTION1_PIN PC2 //将 motion 引脚设置为主板的实际 GPIO

耗材检测还需要通过以下两个地方来设置耗材异常暂停后的动作。

#define NOZZLE_PARK_FEATURE // 喷头暂停功能

#define NOZZLE_PARK_POINT { (X_MIN_POS + 10), (Y_MAX_POS - 10), 20 } //设置喷头暂停时的 X、Y 的坐标以及 Z 轴抬升的高度

24

#define ADVANCED_PAUSE_FEATURE // 可以设置暂停时耗材回抽的长度及速 度，继续打印后耗材挤出的长度和速度等参数

### 4.3 RRF

M591 D0 P7 C"e0stop" L2.88 R75:125 E9 S1 ; 堵料检测精度为 2.88mm, 引脚为 e0stop

25

## 五、校准方法

理论检测长度为 2.88 毫米，这是每次信号脉冲之间将挤出的耗材量。这意味着如果在 2.88 毫米的耗材行程命令后没有检测到耗材运动信号，将触发耗材错误。

将检测长度设置为刚好 2.88 毫米可能会频繁触发错误或故障报警。您可以将该参数视为 传感器灵敏度，数字越高传感器灵敏度越低。

检测长度需根据 SFS V2.0 的安装位置进行调整。与挤出机距离越远，需要设置的数字越 高。我们建议起始点为 3 毫米。如果仍频繁触发错误，请以 1 毫米为步长增加检测长度, 直至问题解决。

26

## 六、注意事项

1) 本模块使用 3.3V 或 5V 供电，电压过高会导致模块损坏。
2) 频繁、气动接头会导致外壳损坏。
3) 未留有断料检测模块的主板使用前请咨询技术支持。

如果您还需要此产品的其他资源，可以到 https://github.com/bigtreetech/ 上自行查 找，如果无法找到您所需的资源，可以联系我们的售后支持（service005@biqu3d.com）。

若您使用中还遇到别的问题，欢迎您联系我们，我们定会细心为您解答；若您对我们的产 品有什么好的意见或建议，也欢迎您回馈给我们，我们也会仔细斟酌您的意见或建议，感 谢您选择 BIGTREETECH 制品，谢谢！

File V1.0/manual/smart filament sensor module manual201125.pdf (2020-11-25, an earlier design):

Smart Filament Sensor Module Manual | ShenZhen BigTree Technology CO.,LTD .

ShenZhen BigTree Technology CO.,LTD .

- 1 - | www.BIGTREE-TECH.com

# BIGTREETECH Smart Filament Sensor Module

# Operating instruction

- 2 - | www.BIGTREE-TECH.com

Ⅰ.Product introduction
Smart Filament Detection Module is a filament detection module aiming at the defects of the broken materials detection module in the market. It was launched by the 3D printing team of ShenZhen BigTree Technology CO.,LTD . Ⅱ.Module Features
1) It can detect abnormal extrusion of filament caused by nozzle plugging, filament wrapping and extruder failure. 2) It works with open source firmware marlin 2.0.x. Marlin2.0 uses

powerful development tools, Visual Studio Code integrated development environment: supports online debugging, which is more helpful for product development and performance optimization. Adopts C language development, so it has low development threshold. 3) Support motherboard with broken filament detection interface. 4) Support screen 2004,12864, TFT24 (12864 mode), tft35_v3.0 (12864

mode). 5) The module is being optimized and will be compatible with touch

screen in the future. 6) Compatible touch screen TFT24, TFT35-V3.0. 7) Support for input power 3.3v-5v.

- 3 - | www.BIGTREE-TECH.com
8) Support long - range and short - range extrusion. 9) Support 1.75mm diameter filament (please install the flexible

filament before installing the extruder). 10)Installation is optional.

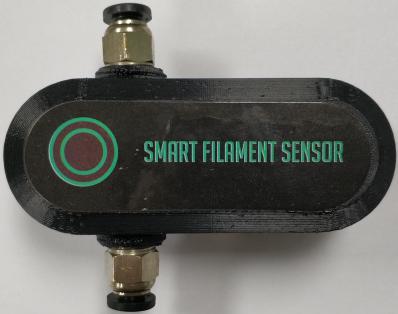
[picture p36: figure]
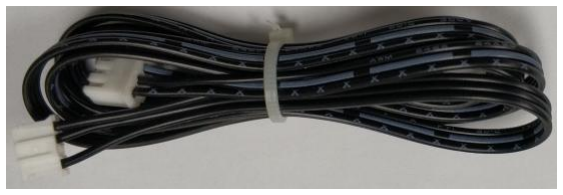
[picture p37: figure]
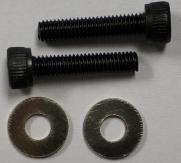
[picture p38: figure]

- 4 - | www.BIGTREE-TECH.com

Ⅲ.Item listing

1) Smart Filament Sensor：
2) Smart Filament Detection Module Cable：
3) Smart Filament Detection Connector
4) Spare set screws：

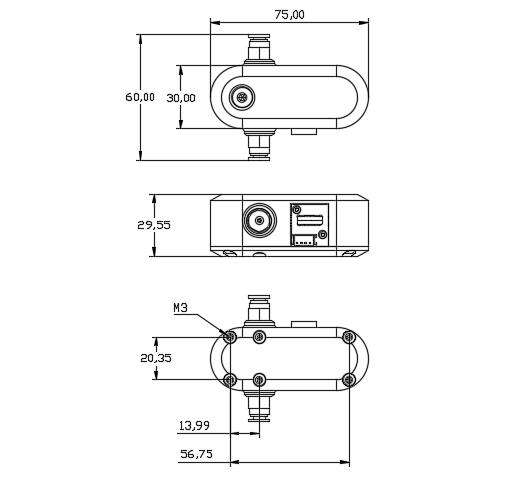
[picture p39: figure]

- 5 - | www.BIGTREE-TECH.com

Ⅳ.Module parameters
Module size:75mmX30mmX29.55mm Fixed hole spacing：20.35mm Filament detection diameter：1.75mm Detection length：7mm
Voltage：3.3V~5V
Adapter firmware：marlin 2.0.X
Support extrusion: long - range extrusion, short - range extrusion

figure 1

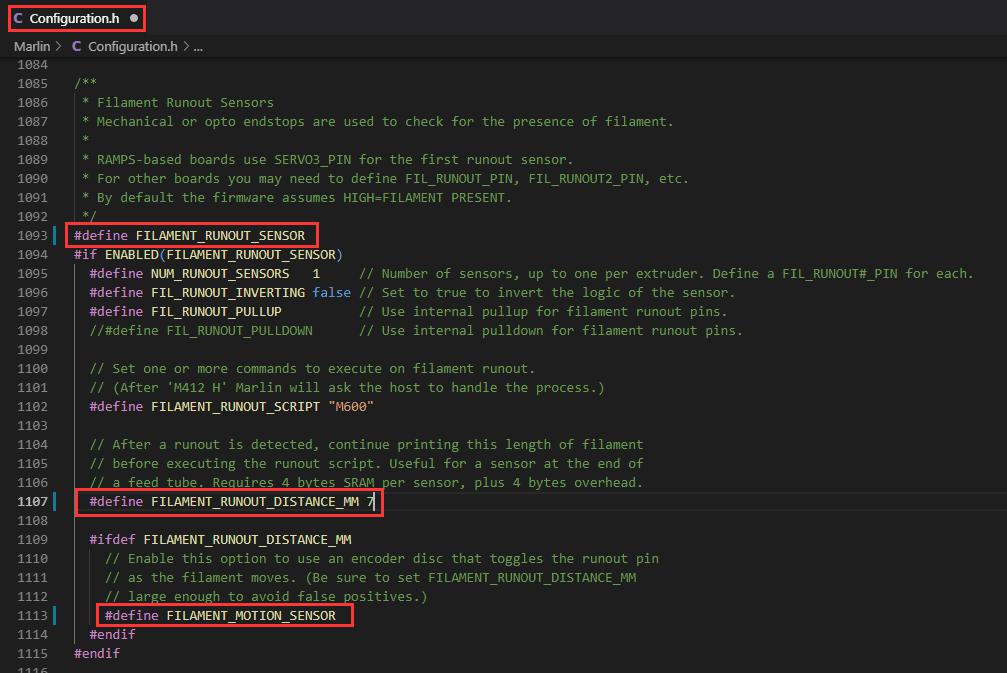
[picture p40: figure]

- 6 - | www.BIGTREE-TECH.com

Ⅴ. Firmware modification
1) The firmware of this product is marlin2.0.x. Screen 2004,12864, TFT24 (12864 mode), tft35_v3.0 (12864 mode) can be used directly. The motherboard that can be used :SKR V1.3; SKR mini E3. SKR E3 DIP;

MKS CEN L; MKS GEN V1.4. The modification method is shown in figure 2.

figure 2
The configuration to be modified is:
Uncomment #define FILAMENT_RUNOUT_SENSOR Turn on the consumables detection sensor
Uncomment #define FILAMENT_RUNOUT_DISTANCE_MM 7 Sets the accuracy of the sensor to 7mm
Uncomment #define FILAMENT_MOTION_SENSOR Sets the sensor to the encoder type

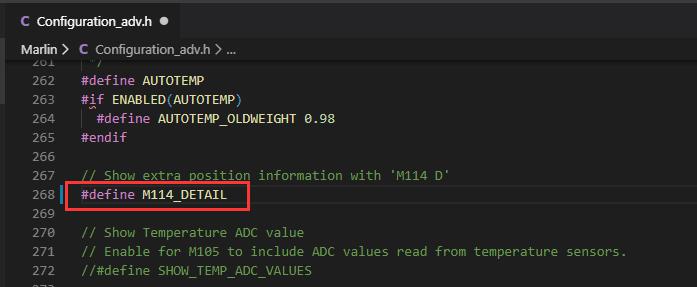
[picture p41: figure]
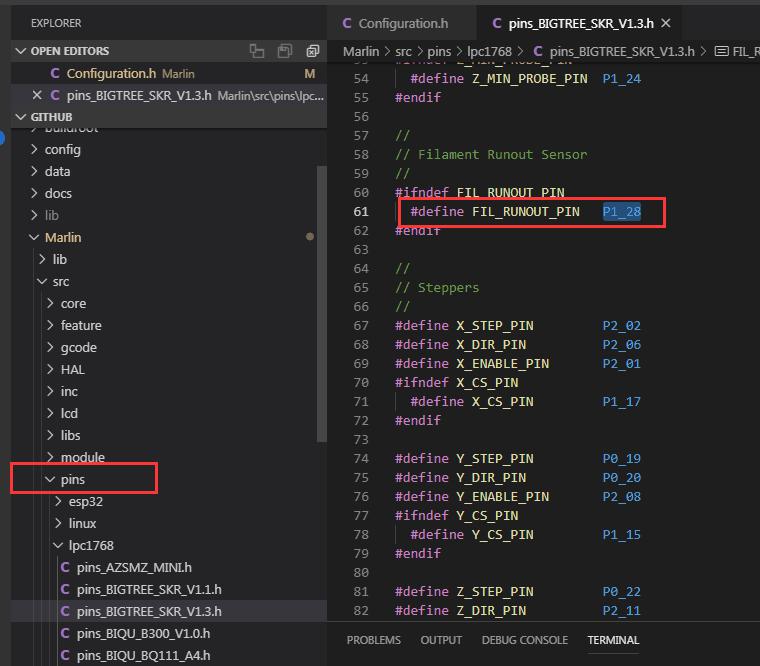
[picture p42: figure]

- 7 - | www.BIGTREE-TECH.com
2) When using the serial touch screen mode, you also need to enable "M114_DETAIL" in marlin ,as shown in Figure 3

Figure 3
3) Interface to modification
Modify the interface location as shown in figure 4. Change the interface to any extended interface.

figure 4

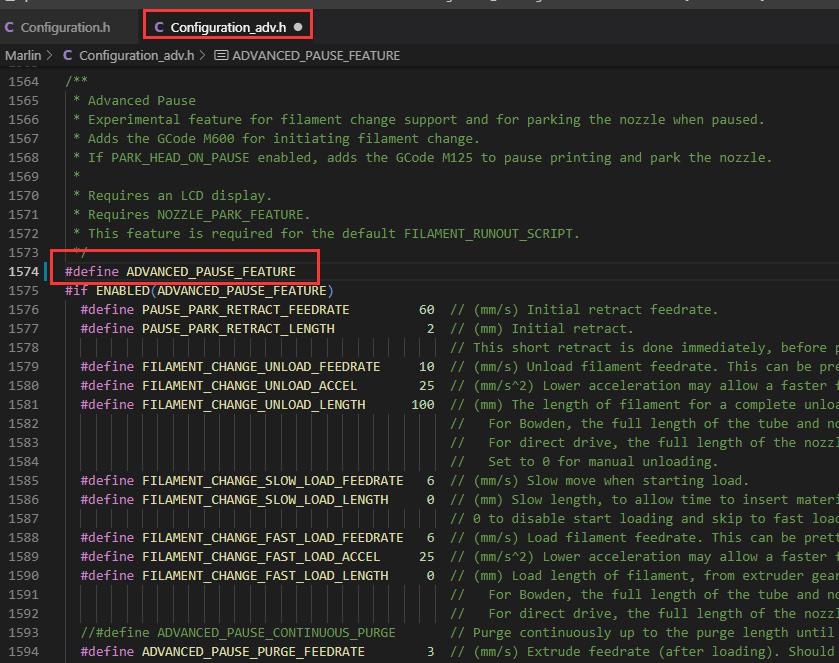
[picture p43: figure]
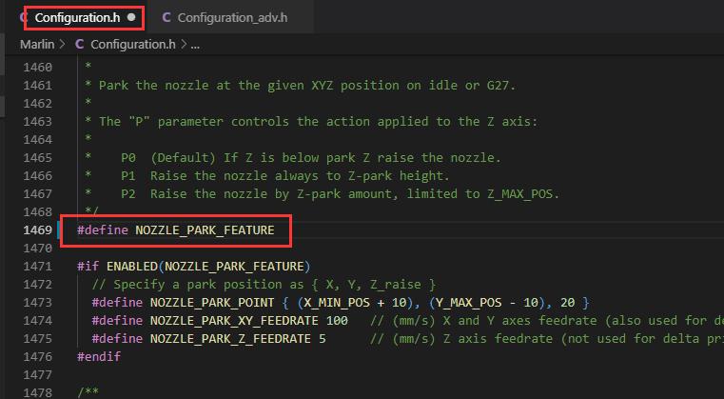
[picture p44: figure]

- 8 - | www.BIGTREE-TECH.com
4) Relevant parameters after modification
The modified position is shown in figure 5, and parameters such as the backpull speed and backpull distance after suspension can be controlled.

figure 5
5) Modify the pause position
The position where the nozzle stops after suspension can be set. The modified position is shown in figure 6.

figure 6

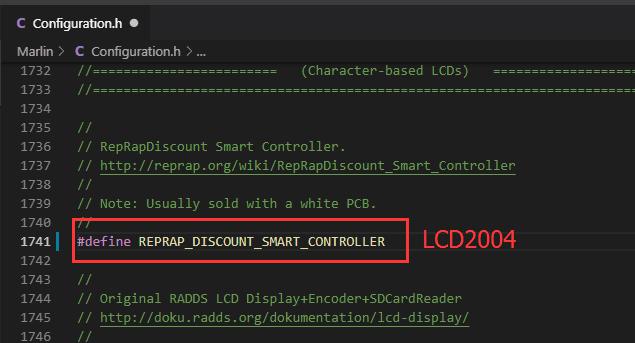
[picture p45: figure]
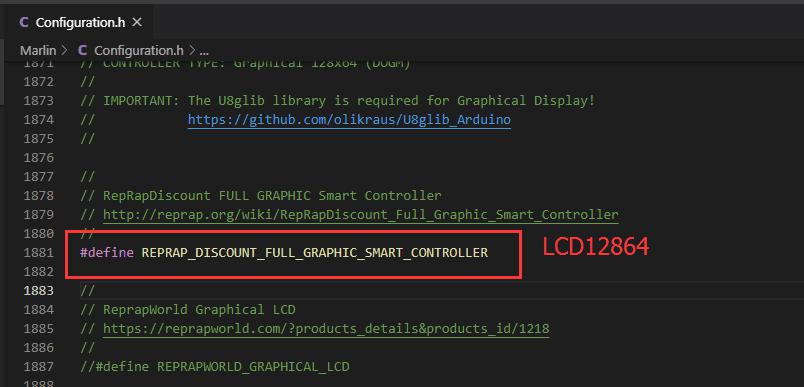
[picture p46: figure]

- 9 - | www.BIGTREE-TECH.com
6) Modify the screen
Modify figure 7 and figure 8 to use LCD2004. 12864, TFT24-12864 mode, TFT35-v3.0-12864 mode.

figure 7

figure 8

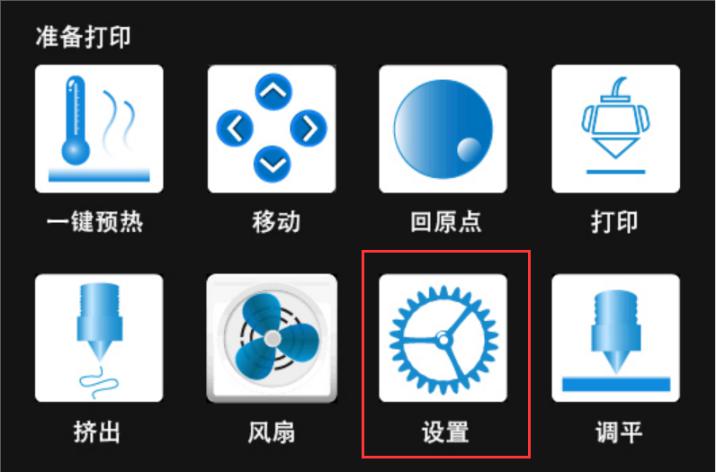
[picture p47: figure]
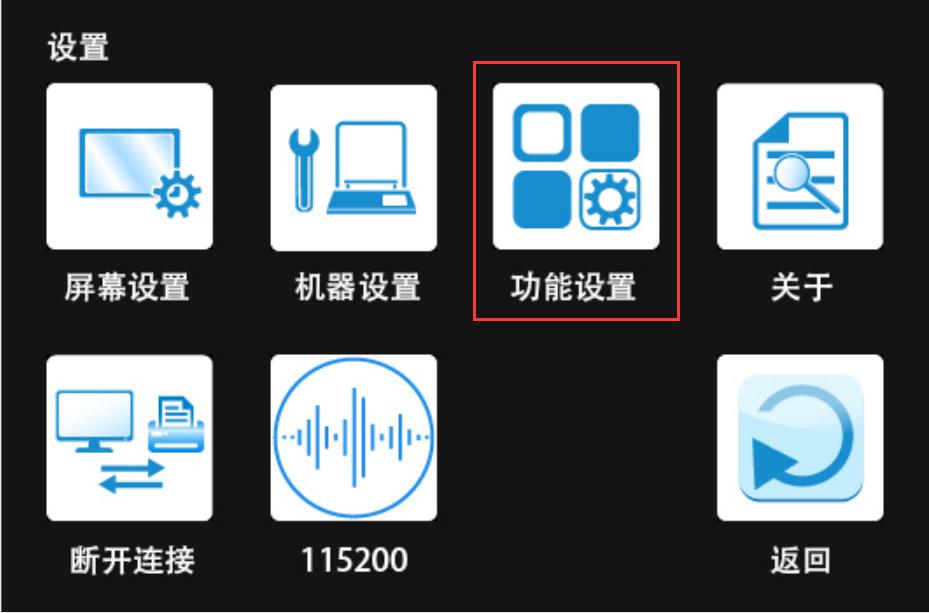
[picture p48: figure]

- 10 - | www.BIGTREE-TECH.com

Ⅵ.Touch screen Settings
Note: at present, the touch screen only supports TFT 24 and TFT35 V3.0 produced by our company
1) Select Settings in the ready to print screen

figure 9
2) Select function settings in the Settings interface

figure 10

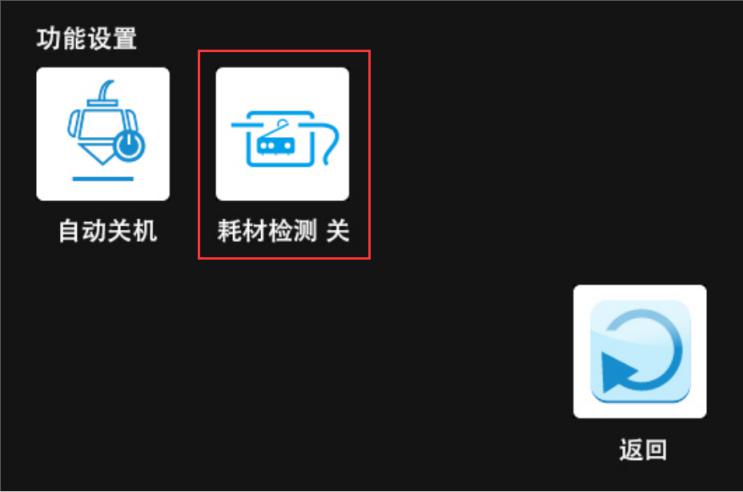
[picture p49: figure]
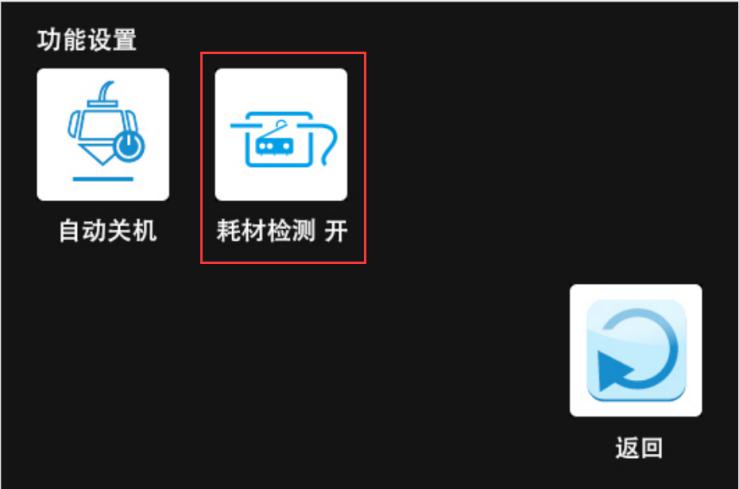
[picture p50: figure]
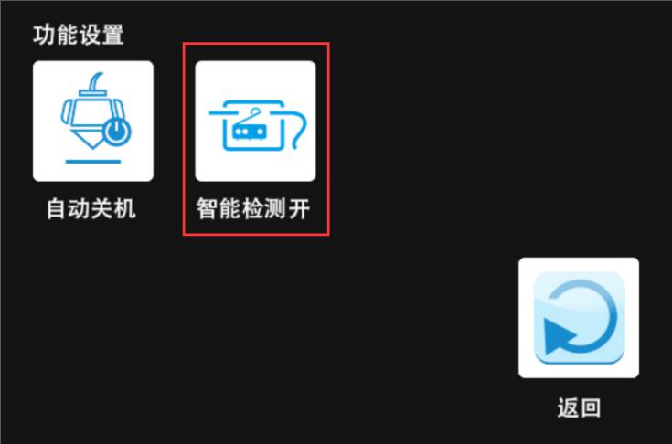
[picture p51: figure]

- 11 - | www.BIGTREE-TECH.com
3) Click filament detection in the function setting interface until the smart detection is on (The default setting of filament detection function on the screen is off. Click the icon again after the filament detection function is on to open the smart filament detection mode).

figure 11

figure 12

figure 13

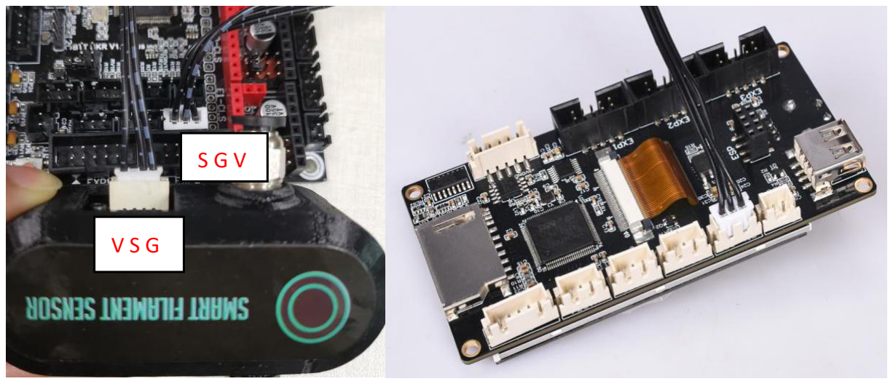
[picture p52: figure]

- 12 - | www.BIGTREE-TECH.com

Ⅵ.Wiring method
1) Take SKR V1.3 (figure 14) as an example

figure 14

The smart filament detection module uses a break detection interface (such as SKR V1.3 for E0DET). Any motherboard with a break detection interface can be used. S for SIN

G for GND
V for VDD

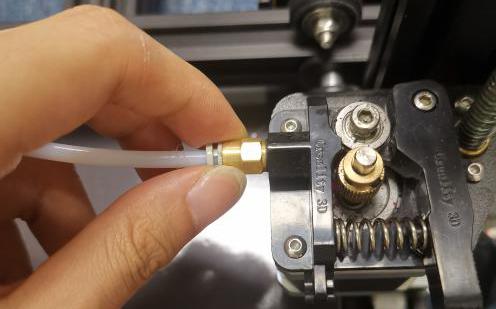
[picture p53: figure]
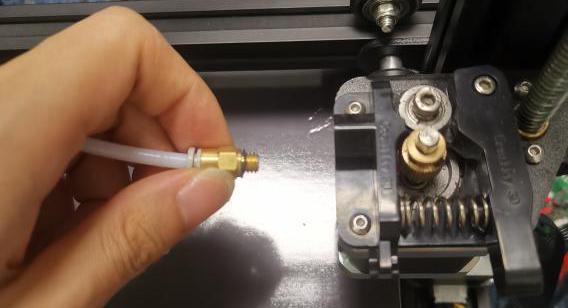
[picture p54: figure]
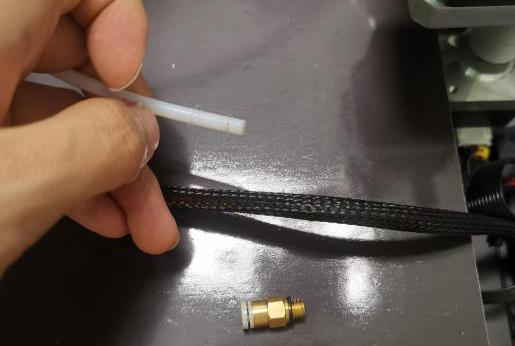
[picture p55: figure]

- 13 - | www.BIGTREE-TECH.com

Ⅷ.Installation method
Remove the pneumatic joint between the teflon tube and the extruder (as shown in figure 15-17)

figure 15

figure 16

figure 17

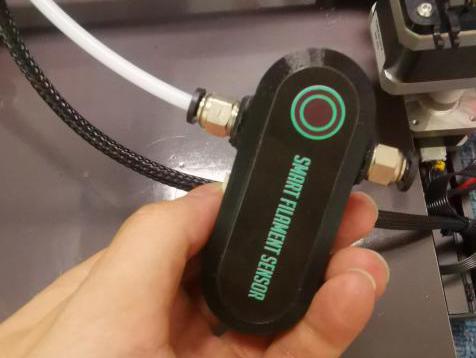
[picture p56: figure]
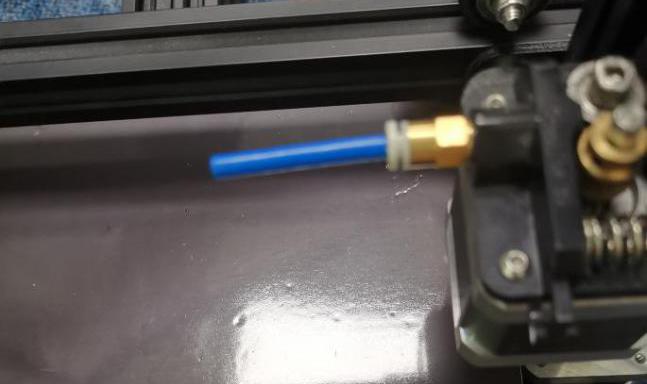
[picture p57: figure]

- 14 - | www.BIGTREE-TECH.com

2)Insert the printer’s teflon tube into the pneumatic joint (like Figure 18)
Note: The teflon tube needs to be fully inserted into the module in order to ensure that it will not affect the entry of filament.

figure 18
3) Screw the smart filament module connector into the extruder.(like figure 19)

figure 19


- 15 - | www.BIGTREE-TECH.com
4) Insert the smart filament module connector Teflon tube into the pneumatic joint (like Figure 20)
Note: Teflon tube needs to be fully inserted into the module so that it does not affect the entry of filament.

figure 20
5) Other fixed methods
The two screw holes shown in Figure 10 can be used for fixing, and the printed piece can be designed according to the fixed position. So this module can be applied to the proximity extruder.

figure 21

- 16 - | www.BIGTREE-TECH.com

Ⅸ.Notes
1) This module is powered by 3.3v or 5V, so high voltage will cause damage to the module. 2) Frequent and wrong screwing of screws and pneumatic connectors

will damage the shell. 3) Scrap and dust may cause false alarms and you need to remove the

module to clean. 4) Please consult technical support before using the motherboard with

no broken filament detection module. 5) If you use a touch mode on display, the smart filament sensor can

only be connected to the display and use.

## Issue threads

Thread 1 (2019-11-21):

Detection Sensor not working on SKR mini e3 Board

zuverck, 2019-11-21:
Utilized the Marlin build in the SKR mini e3 v1.2 repository to enable the smart filament sensor.  I wired up the sensor to the DET0 (PC12) pin on the board, made the changes to enable the feature in the firmware including printing out the debug info to the terminal.  The firmware never senses a change on the input line of DET0 to reset the runout counter so after 7mm the printer will halt.  I have connected the sensor to a logic analyzer and verified that the sensor is working and toggling the output as filament passes through the rollers.  However their is something wrong between the pin input and the getting into the processor as the PC12 pin never changes state in the software.

Can you provide guidance on your test setup utilized for the skr mini e3 v1.2 and which port was the sensor connected to?

kirelam, 2019-11-27:
Following!

bobkinloch, 2019-11-28:
Me too

TerawattX, 2019-12-05:
I have run into the same issue.  The default settings in the source recommends PC15, however I'm guessing that's just for on/off switches and not motion.

I created a new Issue on the E3 Mini repo since its likely something with the board and linked back here.

I also saw that Marlin moved from Bugfix-2.0.x to just 2.0.X so I guess that means its released now?  I was going to try compiling straight from there tomorrow and see if that has an effect.

TerawattX, 2019-12-06:
So I just got a response on the other SKR Mini thread stating that PT-DET is not use for filament detection.  I've asked if the module will work on 2 pins vs 3 since technically it comes with a 4 pin to 3 pin cable.

https://github.com/bigtreetech/BIGTREETECH-SKR-mini-E3/issues/144#issuecomment-562742596

MartinFuersatz, 2019-12-14:
same here - wondering which pin to use on this board

bobkinloch, 2019-12-16:
\marlin-2.0.x\marlin-2.0.x\marlin\src\pins\stm\pins_BTT_SKR_MINI_E3.h
 Change #define FIL_RUNOUT_PIN  PC12   //   PT-DET

#define FILAMENT_RUNOUT_SENSOR
#if ENABLED(FILAMENT_RUNOUT_SENSOR)
  #define NUM_RUNOUT_SENSORS   1     // Number of sensors, up to one per extruder. Define a FIL_RUNOUT#_PIN for each.
  #define FIL_RUNOUT_INVERTING true // Set to true to invert the logic of the sensor.                   //***
 // #define FIL_RUNOUT_PULLUP   

M119 to test if the sensor is working
This setup works on my CR10S with the SKR Mini board and a 3 wire sensor

Hope this helps!!

TerawattX, 2019-12-16:
Interesting.  I had the pins set correctly, but I didn't change the FIL_RUNOUT_INVERTING value.  When my current print ends (in a couple of days), I'll update the firmware and see what happens.

Thanks!

TerawattX, 2019-12-18:
@bobkinloch,

Do you have FIL_RUNOUT_PULLDOWN commented out same as PULLUP?

I flashed the firmware 2x now to test.  First time I set Inverting to true but missed that you commented out the FIL_RUNOUT_PULLUP as well.  In this state it let me print, but when I removed filament it never seemed to trigger.

I recompiled and left inverting set to true, but commented out the pullup line and now its triggered at all times.  Kind of wish I could change these values in the menu to make testing easier :\

masgar, 2019-12-30:
Anyone solved? I'm facing the same problem. I have also an SKR 1.3 not tried yet. There is a way to check if sensor is faulty?

Thanks

TerryFrench, 2020-01-01:
I just placed the order for one. I will use it with an SKR 1.3 Mini E3 I'm already using.
I do have an oscilloscope, so I'll likely give it a quick try first. Connect ground and 5V, then check the signal pin between (common ground used for the scope). That way I will see what is expected there. i.e. a high or low signal when there is wire vs. no wire, and also wire moving vs. not moving.

I'm using 2.0.1 Marlin I configured to use BL Touch. My next step will be to figure out if I want to connect this through Marlin or to a GPIO pin on my Raspberry Pi running Octoprint. If I go the GPIO pin way, I will use some 3v - 5V adapter chip I have running around to not put 5V on the Pi's pins directly.
Whatever works best... I will post my results here.

phtp, 2020-01-02:
Anyone get this to work with the BIGTREETECH TFT35 V3.0 touchscreen display? They have a Fil-Det pin for this purpose.

CaptainRoot, 2020-01-04:
Had a similar Problem on my Cr10 with MKS SGEN L using Z+ endstop pin. the pin hast teh same pullup,  capacitor wireing as the skr 1.3.

My Problem was that Marlin does not set the runout distance after flashing the firmware.

M412
echo:Filament runout ON
Filament runout distance (mm): 0.00

M412 D7
echo:Filament runout ON
Filament runout distance (mm): 7.00

After that the senor works fine for me

phtp, 2020-01-05:
I have a Ender 3 Pro - I gave up on trying to get it to work with the TFT 35 v3.0 and ended up using the PT-DET on the skr mini e3 v1.2 board.  So far it seems like it does work, but I'll need to do more test around it.

Not sure if you have a BLTouch as well, but I found the combination of BLTouch and trying to enable the filament runout settings to be over the 256k memory cap.  Did a bit of research and turns out the v1.2 can go above that.

The modifications I made were on the configs I grabbed are from the bigtreetech github for the skr mini e3 - https://github.com/bigtreetech/BIGTREETECH-SKR-mini-E3/tree/master/firmware/V1.2/Marlin-2.0.x-SKR-Mini-E3-V1.2

### platformio.ini - to change from 256k to 512k
[platformio]
src_dir      = Marlin
boards_dir   = buildroot/share/PlatformIO/boards
default_envs = **STM32F103RC_bigtree_512K**

My filament runout sensor settings. I trimmed a bunch of stuff and left what's enabled to reduce clutter.
### configuration.h
  #define FILAMENT_RUNOUT_SENSOR
#if ENABLED(FILAMENT_RUNOUT_SENSOR)
  #define NUM_RUNOUT_SENSORS   1     // Number of sensors, up to one per extruder. Define a FIL_RUNOUT#_PIN for each.
  #define FIL_RUNOUT_INVERTING false // Set to true to invert the logic of the sensor.
  #define FIL_RUNOUT_PULLUP          // Use internal pullup for filament runout pins.
  //#define FIL_RUNOUT_PULLDOWN      // Use internal pulldown for filament runout pins.

  #define FILAMENT_RUNOUT_SCRIPT "M600"
  #define FILAMENT_RUNOUT_DISTANCE_MM 7
  #define FILAMENT_MOTION_SENSOR

#define NOZZLE_PARK_FEATURE
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
TerawattX, 2020-01-27:
@btsubjectdata Sounds like you're in the same boat I am.  I changed my firmware to just a on/off and left it on the PT-DET port to test if I could change the open/triggered state and no matter what it stayed the same.  I'm not sure if this is a fault with the board or bug in the code though.

There is a setting near the end of the configuration_adv file that enables debugging for pins.  Might be worth enabling to confirm if the board is seeing the state change and its just being lost in the code somewhere after that.  By the time I had gotten to this point though I was burnt out and just wanted to print something vs figure out how to even see the pin states, let alone debug more of the code.

In the end I just set up a dumb filament switch using my old Z-stop and wired it to the E0-stop port.  It won't catch clogs and jams, but better than nothing.

Fuyingbro, 2020-03-07:
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

Thank you for posting this as I could finally get it working "kind of". I too could not for the life of me get it to work with my tft35 v3.0. So went by your details and put it on my skr e3 mini 1.2.  In 12864 mode the runout portion works, but it keeps thinking the line has stopped. I have tried having the filament going in either end to see if the sensor wheels have to turn one way or the other and does the same no matter what. Oh, and is there a way to have a continue option instead of having to turn off the runout sensor in order to continue. I have either PURGE or RUNOUT SENSOR on/off. Only after I turn the sensor off I get a continue option. For now I am going back to my old runout sensor as I have been at this for days. But any help would be appreciated.

brettvitaz, 2020-03-10:
To anyone still having trouble with this, this comment describes the problem and workaround to the problem: https://github.com/bigtreetech/BIGTREETECH-SKR-mini-E3/issues/144#issuecomment-590925789

The gist is that the PT-DET pin is already claimed by another process. An easy workaround is to initialize the runout sensor after the serial communications.

Essentially, move these lines in `Marlin/src/MarlinCore.cpp`:

```
  #if HAS_FILAMENT_SENSOR
    runout.setup();
  #endif
```

to directly after lines:

```
  #if NUM_SERIAL > 0
    MYSERIAL0.begin(BAUDRATE);
    uint32_t serial_connect_timeout = millis() + 1000UL;
    while (!MYSERIAL0 && PENDING(millis(), serial_connect_timeout)) { /*nada*/ }
    #if NUM_SERIAL > 1
      MYSERIAL1.begin(BAUDRATE);
      serial_connect_timeout = millis() + 1000UL;
      while (!MYSERIAL1 && PENDING(millis(), serial_connect_timeout)) { /*nada*/ }
    #endif
  #endif

  SERIAL_ECHOLNPGM("start");
  SERIAL_ECHO_START();
```

The directions in the manual are otherwise correct (except that the pin is PC12).

SPACEMONKEY-01, 2020-03-11:
Been working this thing for a few weeks now. I do not have a BL Touch. All it took was to hook up the filament sensor to the servo pins PA1 and it works perfect. Not sure what is happening with PC-12, but it's working fine with the PA1 pins.

brettvitaz, 2020-03-12:
Many of us do have a BLTOUCH (myself included). I'm glad to hear you didn't have this trouble.

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

SPACEMONKEY-01, 2020-03-12:
Oh for sure!! I also want to get a BLT so hopefully they get this pin issue fixed. With my original post I just wanted to let everyone know with a BLT that you're not doing anything wrong. This is a pin issue for sure.

> Many of us do have a BLTOUCH (myself included). I'm glad to hear you didn't have this trouble.
> […](#)
> On Mar 11, 2020, at 3:28 PM, SPACEMONKEY-01 ***@***.***> wrote:   Been working this thing for a few weeks now. I do not have a BL Touch. All it took was to hook up the filament sensor to the servo pins PA1 and it works perfect. Not sure what is happening with PC-12, but it's working fine with the PA1 pins. — You are receiving this because you commented. Reply to this email directly, view it on GitHub, or unsubscribe.

brettvitaz, 2020-03-12:
I'm going to open a PR with the Marlin repo with the fix I mentioned, and open a discussion on how to solve the problem properly.

demonkazuya, 2020-04-22:
Hi sorry for bumping this issue again. Seems i have a different issue with  PC12 PIN (PT-DET). Did all the changes mentioned including the change on Marlin/src/MarlinCore.cpp. Every time i pull out the filament the printer shuts down. I need to reinsert/trigger the sensor the turn on the printer. BTW im using vanila marlin 2.0.5.3. I see that the BTT has been updated to the latest version but I am having a hard time compiling it.

DerDingsCS, 2020-05-03:
I’m having the same problem too.
Tried the fix in MarlinCore.cpp and the board.h fix.
Nothing seems to fix it.

nokesy, 2020-05-03:
If anyone has got this working on a 3 pin fil runout sensor, can they tell me wiring
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

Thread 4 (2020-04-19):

filament smart sensor triggers filament change all the time

CsEngineeringDK, 2020-04-19:
I have bought and followed the guide in the link. the sensor triggers a filament runout all the time and I have no idea how to fix the thing. I have the skr mini e3 with the sensor connected to PT-DET as in the guide. I have taken the sensor apart and seems like the wheel is slipping/ not gripping properly. really disappointed with this sensor  https://www.reddit.com/r/ender3/comments/e894j7/marlin_20x_guide_for_ender_3_using_skr_mini_e3_v12/

Tazman75, 2020-05-27:
I had the same problem seems there is an issue with using the PT-DET pin.  Looking at the schematic it should work.  The issue almost seems software related, as I can confirm via the M117 and debug commands the sensor triggers fine off the PT-DET pin, but it doesn't work.  There is a larger thread on this in one of the other threads.

Anyway if you rewire your connect, use the pdf for the pins, and then connect it in there it works.

jyriturkia, 2020-06-01:
https://github.com/bigtreetech/smart-filament-detection-module/issues/1#issuecomment-570776528
Solved issue for me.

brettvitaz, 2020-08-02:
In addition to the filament runout distance not set (for me I just had to restore eeprom to activate my firmware settings), I had to set the distance to 25mm instead of 7mm.

rmpel, 2022-01-31:
Hi @brettvitaz , can I ask _why_ you set to 25mm?

Let me ask in a different way;
I switched from simple switch to the SFS because of random false positives (sometimes never in a 20 hour print, sometimes about 20 times (!!!!) in a 40 minute print. Quite annoying.
The SFS seems to now display the same erratic behavior, so I suspect software issues, instead of hardware.
Would setting the distance longer prevent these false positives?

Or perhaps @bigtreetech can answer this question for me? Love the products, b.t.w. :) I run an SKR 1.4 with TMC2209 UART on an Ender 3 in this case.

rmpel, 2022-02-22:
Update: my SKR 1.4 no longer accepts new firmware so I swapped it for an SKR 2.0 board, downloaded the latest firmware (Feb20), everything works great, except; still false positives.
I tried FIL_RUNOUT_STATE LOW as well as HIGH, I tried 3mm as well as 10mm for FILAMENT_RUNOUT_DISTANCE_MM.
At this point I will probably remove the sensor and go without, because it's totally unreliable.

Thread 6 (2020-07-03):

Filament detection sensor always triggers filament change on SKR 1.4 Turbo.

AbeTheRock, 2020-07-03:
The filament detection sensor keeps triggering for a filament change I've tried inverting the sensor, raised the run out distance but it still happens. I'm using an Skr 1.4 Turbo board and it's plugged into pin slot P1_26. Not really sure how to go about this, any help would be appreciated.

#define FILAMENT_RUNOUT_SENSOR
#if ENABLED(FILAMENT_RUNOUT_SENSOR)
  #define NUM_RUNOUT_SENSORS   1     // Number of sensors, up to one per extruder. Define a FIL_RUNOUT#_PIN for each.
  #define FIL_RUNOUT_INVERTING false  // Set to true to invert the logic of the sensor.
  #define FIL_RUNOUT_PULLUP          // Use internal pullup for filament runout pins.
  //#define FIL_RUNOUT_PULLDOWN      // Use internal pulldown for filament runout pins.
  #define FIL_RUNOUT_PIN 2 // Creality CR10-S stock sensor

  // Set one or more commands to execute on filament runout.
  // (After 'M412 H' Marlin will ask the host to handle the process.)
  #define FILAMENT_RUNOUT_SCRIPT "M600"

  // After a runout is detected, continue printing this length of filament
  // before executing the runout script. Useful for a sensor at the end of
  // a feed tube. Requires 4 bytes SRAM per sensor, plus 4 bytes overhead.
  #define FILAMENT_RUNOUT_DISTANCE_MM 7

  #ifdef FILAMENT_RUNOUT_DISTANCE_MM
    // Enable this option to use an encoder disc that toggles the runout pin
    // as the filament moves. (Be sure to set FILAMENT_RUNOUT_DISTANCE_MM
    // large enough to avoid false positives.)
    #define FILAMENT_MOTION_SENSOR
  #endif
#endif

B-rad888, 2020-07-05:
Whats with:
 #define FIL_RUNOUT_PIN 2 // Creality CR10-S stock sensor
I don't see that as an option, or necessary for config.
Skr 1.4 has pins defined in pins file:
 #define FIL_RUNOUT_PIN                     P1_26  // E0DET
#define FIL_RUNOUT2_PIN                    P1_25  // E1DET
Connecting the sensor to 1.26 or 1.25 with the settings you provided above should work
If you are getting false positives make sure :
1. the nozzles is not blocked or too close to the bed
2. the extruder is pushing filament correctly (not skipping or coasting over filament making it appear to be jammed)

AbeTheRock, 2020-07-07:
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

I was also wondering why that line was in the config, I had pulled the config file from the marlin bugfix 2.0 branch for my CR-10 s5. I tried commenting it out and it still didn't work. I made sure the nozzle wasn't too close or jammed and the extruder appears to be working just fine.
One thing I did notice is that when I run an M119 command is that sensor appears open before any filament has been moved. Once the filament moves within the sensor it changes to triggered and remains triggered even when I take the filament out of it. I think it gets stuck as triggered. When I invert it then it gets stuck as open.

B-rad888, 2020-07-07:
Are you printing from a TFT? If so are you using touch mode or marlin mode?
Did you define in config.h
#define NOZZLE_PARK_FEATURE
Did you define in config.adv
#define ADVANCED_PAUSE_FEATURE
Are the wires in the correct location?

madk71, 2021-04-07:
Hi, I have the same problem. I use a CR10S with skr1.4 turbo 5x TMC2208 UART(always BTT)+ hemera and a standard CR10s LCD.
The wiring is correct, connected in E0DET, Tried disabling everything (Linear advance, s-curve, junction deviation all off) but nothing.
Tried to print at 1 cm high (basically throwing filament to the bed) and still after a while the change filament is triggered.
Any Idea?

kravviec, 2021-04-14:
Hey guys, I have an ordinary on/off endstop plugged into P1_26 (#define FIL_RUNOUT_PIN P1_26) on BTT SKR 1.4 Turbo.
The LED on the sensor turns on and off when I switch. But M119 always returns Filament: TRIGGERED.
I can reverse this state in Marlin (#define FIL_RUNOUT_STATE     HIGH ), but then it is always OPEN. Have you any solution to solve that problem?

madk71, 2021-04-15:
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

Hi, try to comment #define WATCH_ALL_RUNOUT_SENSORS

kravviec, 2021-04-18:
I've tried, but still nothing happens :(

`#define FILAMENT_RUNOUT_SENSOR
#if ENABLED(FILAMENT_RUNOUT_SENSOR)
  #define FIL_RUNOUT_ENABLED_DEFAULT true // Enable the sensor on startup. Override with M412 followed by M500.
  #define NUM_RUNOUT_SENSORS   1          // Number of sensors, up to one per extruder. Define a FIL_RUNOUT#_PIN for each.

  #define FIL_RUNOUT_STATE     LOW        // Pin state indicating that filament is NOT present.
  #define FIL_RUNOUT_PULLUP               // Use internal pullup for filament runout pins.
  //#define FIL_RUNOUT_PULLDOWN           // Use internal pulldown for filament runout pins.
  #define WATCH_ALL_RUNOUT_SENSORS      // Execute runout script on any triggering sensor, not only for the active extruder.`

makermelissa, 2021-06-08:
I'm having this issue as well. Nothing is working so far even with nothing plugged in the E0DET port, it counts as triggered.

makermelissa, 2021-06-08:
Also, I have TMC2209 steppers and I suspect there may be a conflict between sensorless homing and the endstop triggers as it is ignoring the X and Y endstops (which is desirable).

makermelissa, 2021-06-08:
Ok, that's the issue. I have a TMC2209 on my E0 extruder. Options are:
1. Disable Sensorless homing on the Extruder Stepper, which should solve it for most people who don't want to mess with the firmware.
2. Swap the FIL_RUNOUT_PIN and FIL_RUNOUT2_PIN values and plug it into the E1DET port for people who don't want to mess with their stepper driver.

I went with the second option because I didn't want to modify my stepper.

ProtomakerSprint, 2021-09-10:
I have the same issue of false triggering; indicating the filament is out even when it is not: ( Bigtree Tech SKR 1.4 Turbo board, Marlin 2.09.01 )

If I turn off Runout detection on the LCD 12864 it 3D prints without issues. Of course this will not detect any filament runout.

So I designed and 3D Printed:-

Clever Filament Runout/Jam Dictator
Use an 3D Printed encoder wheel to trigger an Optical Endstop
Filament actually moving may be viewed by the encoder wheel turning or the Optical endstop- LED flashing
..
NOTE::: **BOTH** the Bigtree Tech Smart Filament Detector and this unit return a signal that the filament is OUT even when the filament is present, false triggering.

Because both do the same false triggering I think it may be a Marlin issue and not either unit.

Looking online indicates false triggering is a common issue.

[https://www.thingiverse.com/thing:4961824]

mlauber, 2022-02-01:
> Are you printing from a TFT? If so are you using touch mode or marlin mode? Did you define in config.h #define NOZZLE_PARK_FEATURE Did you define in config.adv #define ADVANCED_PAUSE_FEATURE Are the wires in the correct location?

Is using a TFT Touch Screen still an issue when running the BTT Smart Filament Runout Sensor?

lsgllc, 2022-03-11:
I am having the same problem. I have tried 1. and 3. Changing to a 2208 did not help.

lsgllc, 2022-03-11:
OK. Here's what I've tried: E3P BTT skr v1.4 turbo sensorless homing on (Since previous post indicate it doesn't matter what you do, these sensors simply do not work.

The best thing to do is leave a flamingly bad review on Amazon and  Google.

1. Everything mentioned above.
2. found an unused pin and assigned to ROS.
3. tried every combination possible for any defined services using the same pin.

I (We) have runout (TRIGGER) of options. Bottomline: It is a complete hoax that does not work for anyone as far as I can tell.

dsvi, 2022-07-10:
I had the same issue.
The problem was value of `FILAMENT_RUNOUT_DISTANCE_MM` was too small. But when you change it in firmware it doesn't have any effect, since was already saved on the flash, and read from there. So script like

```
; Enable (and reset) filament runout detection and set runout distance to 30mm
M412 S1 D30
M500 ; save settings to flash
```
Helped me.

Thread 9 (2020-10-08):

Always triggers with Creality V4.2.7 board

bbturbo1, 2020-10-08:
I just installed the new creality V4.2.7 board on an ender 5 and I cannot get this sensor to work. I’ve watched every video I can find and changed my firmware correctly (based on what I’ve been told) even messed with switching between low and high multiple times. I’ve swapped the actual pins on the connector, just to see if that could have been it, and nothing. I just get the printer to do one pass of a purge line and then it tells me to change the filament.

PPPBerlin, 2020-10-16:
Kind of same for me. After a few layer it starts the filament runout procedure. After continue the print it starts the same a few layers after.

`/**
 * Filament Runout Sensors
 * Mechanical or opto endstops are used to check for the presence of filament.
 *
 * RAMPS-based boards use SERVO3_PIN for the first runout sensor.
 * For other boards you may need to define FIL_RUNOUT_PIN, FIL_RUNOUT2_PIN, etc.
 */
#define FILAMENT_RUNOUT_SENSOR
#if ENABLED(FILAMENT_RUNOUT_SENSOR)
  #define FIL_RUNOUT_ENABLED_DEFAULT true // Enable the sensor on startup. Override with M412 followed by M500.
  #define NUM_RUNOUT_SENSORS   1          // Number of sensors, up to one per extruder. Define a FIL_RUNOUT#_PIN for each.
  #define FIL_RUNOUT_STATE     LOW        // Pin state indicating that filament is NOT present.
  #define FIL_RUNOUT_PULLUP               // Use internal pullup for filament runout pins.
  //#define FIL_RUNOUT_PULLDOWN           // Use internal pulldown for filament runout pins.

  // Set one or more commands to execute on filament runout.
  // (After 'M412 H' Marlin will ask the host to handle the process.)
  #define FILAMENT_RUNOUT_SCRIPT "M600"

  // After a runout is detected, continue printing this length of filament
  // before executing the runout script. Useful for a sensor at the end of
  // a feed tube. Requires 4 bytes SRAM per sensor, plus 4 bytes overhead.
  #define FILAMENT_RUNOUT_DISTANCE_MM 7

  #ifdef FILAMENT_RUNOUT_DISTANCE_MM
    // Enable this option to use an encoder disc that toggles the runout pin
    // as the filament moves. (Be sure to set FILAMENT_RUNOUT_DISTANCE_MM
    // large enough to avoid false positives.)
    #define FILAMENT_MOTION_SENSOR
  #endif
#endif`

rampardes, 2020-12-17:
I have the same problem.

lstepnio, 2021-01-18:
I'm having the same behavior with the 4.2.2 board.

Currently using the following firmware to help rule out error in my build config.

https://marlin.crc.id.au/firmware/Ender%203%20-%20v4.2.2%20Board%20-%20BLTouch/

I'm observing sensor state changes using M119 when manually feeding filament through the sensor so physical layer should be good. It's configured for 7mm as verified from the console. Same results from SD or OctoPrint and no issues if filament sensor is disabled with Gcode.

lstepnio, 2021-01-19:
Setting M412 D10  got me up and running. The 7, 8 and 9 would false trigger pretty consistently but so far working without issue with 10mm (D10)

ProtomakerSprint, 2021-01-30:
lstepnio commented 12 days ago
Setting M412 D10 got me up and running. As lstepnio says would false trigger pretty consistently but so far working without issue with M412 D10 = 10mm (D10)

So I will add  M412 D10  to my Start G Code

https://marlinfw.org/docs/gcode/M412.html

Here are some video details of the Issue I have before using the M412 D10  in my Start G Code:-

https://youtu.be/AN19jHV3Mrk

Modern-Memories, 2022-07-06:
For now I set the runout to 100mm

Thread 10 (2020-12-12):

Filament runout detection from onboard SD & TFT35 SD/USB

chris-Neale, 2020-12-12:
Is there a way to link this sensor to both the E0-STOP pin on SRK mini E3 V2.0 and the FIL-DET on the TFT35 E3 V3.0? so that the detection is made with printing from the onboard SD and TFT SD/USB?

Just to note, i currently have it connected to the SRK mini E3 V2.0 E0-STOP connector.

oldman4U, 2020-12-21:
kisslorand recommended:
Send M75 to Marlin when print begins. Marlin doesn't know that the print is started so no filament runout warnings. It's not a bug.
You can put M75 in your Start-Gcode and you're set. That's what I did.

Hope this helps, please let us know

Thank you

chris-Neale, 2020-12-28:
Hi, Yes putting M75 in the start G-code has worked fine. I have also added M77 to the end G-code just to be sure.

Thanks for your help.

Closed 2020-12-28.

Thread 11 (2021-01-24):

Smart filament sensor non workingwhen attached to TFT35 E3 V3.0

killrob, 2021-01-24:
hi, i have connected the smart filament sensor to the TFT35 E3 V3.0 at the fil-det connector on TFT, this is the part in config.ini
`fil_runout:2
fil_runout_inverting:1
fil_noise_threshold:100
fil_runout_distance:4`
i suppressed all lines comments.

I had done a 5.30 hours print and at 64% the filament ends, what i expect is that the print pause and the LCD tells me that filament was runned out, but no message and no pause from the LCD, with the result that i have a couple of layers missing in the print.

mlauber, 2022-02-01:
bump.  Did you ever figure this out?  I have the same TFT with an SKR 2.0 rev B and can't get the BTT Smart Filament Runout Sensor to work.

killrob, 2022-02-01:
@mlauber i solved attaching the SFS directly to monitor not to motherboard. But you have to change the config.ini of the monitor like this:
fil_runout:2
fil_runout_inverting:1
fil_noise_threshold:100
fil_runout_distance:7

and disable the LIN_ADVANCE in marlin's Configuration_adv.h and enable M114_DETAIL in the same file

nen777w, 2024-08-24:
> hi, i have connected the smart filament sensor to the TFT35 E3 V3.0 at the fil-det connector on TFT

How do you do that?
SFS 2.0 has wire on 4 pins from one side and 2x2 pins from the other (one for the move sensor and one for the switch sensor).
In TFT35 E3 V3.0,  FIL-DET sensor has only 3 pins.

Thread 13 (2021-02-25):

Triggers always on long purgelines

octane321, 2021-02-25:
The sensor triggers on long purgelines even if everything is ok with filament feeding and correct configuration

i.e.: 7mm as recommended. If i do a purge line on start-gcode to clean nozzle and there will be feeded 10mm PLA 1,75 the sensor triggers always and interrupt the print for nothing.....even if i raise up to 15mm it triggers sometimes....with absolutely no problem with filament

it is not only for long and/or thick purge lines....even if you print a long circle with arc welded gcode, it always triggers....that should be really fixed...this i annoying!

thegundamaster, 2021-03-21:
I install mine today and had the same problem

madk71, 2021-04-07:
Same here

patoberli, 2021-12-26:
Did you ever find a solution for this?

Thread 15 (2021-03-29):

Ender 2V2 Marlin2.0.Bugfix Each print is canceled after a few seconds

Str33tfight3rZ1000, 2021-03-29:
Hi,

I'm trying to get the sensor to work. My setup looks like this:

Ender3 V2 with 4.2.2 Reality Board.

BMG Dual Extruder, steps adapted

Marlin firmware 2.0.X or 2.0.Bugfix

Raspi2 B with Octopi and plugin - set on 15mm runout distance

Start code in Octopi
M500
M502
M92 E444.95
M412 D15
M75

Each print is canceled after a few seconds, the test line is there, as are a few lines of the project.
I can find the following in the log file:
[15mm.txt](https://github.com/bigtreetech/smart-filament-detection-module/files/6223587/15mm.txt)

I have already switched from the Marlin bugfix version to the normal one, both without success.

I have no more idea why this is happening.
Material is being conveyed, it is not the sensor, I tested a second one.

NZ-Nitro, 2021-04-12:
Yeah mine doesn't work either

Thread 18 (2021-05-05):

BTT Smart sensor + capacitor ?

Grex3D, 2021-05-05:
Hi, someone know if it possible to add a capacitor on the BTT smart sensor ? (GND / SIG )

Got some interferences on my Endstop solved by capacitor.

Thanks

Grex3D, 2021-05-07:
Ok it works better, you can close the issue :)

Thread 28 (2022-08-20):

BTT SKR E3 V3 board and Smart Filament Sensor always triggering as soon as a print is started?

gleep52, 2022-08-20:
The instructions say to invert the FIL_RUNOUT_INVERTING = TRUE.  But that's no longer supported and only FIL_RUNOUT_STATE Low/High is supported.

I've tried both high and low, and whenever I start a print it immediately triggers the filament unload and loading.  Resumes for another 7mm of filament, then parks and unloads filament again saying it's empty.

I've tried commending out the RIL_RUNOUT_PULLUP option as a few issues here suggested but did not have success there either.

Since this is a BTT product and my motherboard is a BTT product - is there something wrong with the default pinouts of their own products for compatibility?

configuration.h file:

`#define FILAMENT_RUNOUT_SENSOR
#if ENABLED(FILAMENT_RUNOUT_SENSOR)
  #define FIL_RUNOUT_ENABLED_DEFAULT true // Enable the sensor on startup. Override with M412 followed by M500.
  #define NUM_RUNOUT_SENSORS   1          // Number of sensors, up to one per extruder. Define a FIL_RUNOUT#_PIN for each.
  #define FIL_RUNOUT_STATE     LOW         // Pin state indicating that filament is NOT present.
  #define FIL_RUNOUT_PULLUP               // Use internal pullup for filament runout pins.
  //#define FIL_RUNOUT_PULLDOWN           // Use internal pulldown for filament runout pins.
  //#define WATCH_ALL_RUNOUT_SENSORS      // Execute runout script on any triggering sensor, not only for the active extruder.
                                          // This is automatically enabled for MIXING_EXTRUDERs.

   // Commands to execute on filament runout.
  // With multiple runout sensors use the %c placeholder for the current tool in commands (e.g., "M600 T%c")
  // NOTE: After 'M412 H1' the host handles filament runout and this script does not apply.
  #define FILAMENT_RUNOUT_SCRIPT "M600"

  // After a runout is detected, continue printing this length of filament
  // before executing the runout script. Useful for a sensor at the end of
  // a feed tube. Requires 4 bytes SRAM per sensor, plus 4 bytes overhead.
  #define FILAMENT_RUNOUT_DISTANCE_MM 7

  #ifdef FILAMENT_RUNOUT_DISTANCE_MM
    // Enable this option to use an encoder disc that toggles the runout pin
    // as the filament moves. (Be sure to set FILAMENT_RUNOUT_DISTANCE_MM
    // large enough to avoid false positives.)
    #define FILAMENT_MOTION_SENSOR
  #endif
#endif`

Anyone have this thing working on a E3 V3 board?

lyonmaster, 2022-09-11:
I have the same issue and still have not been able to fix it.

GasPath, 2022-09-19:
I have only used the screen connection as it would appear that the TFT is made to work with the SFS. I have worked in the TFT config.ini file, and changing settings there do not seem to change anything for its function.  Both the stock config.ini and my included version do nothing:

#### Filament Runout Sensor
# Select the type of filament runout sensor and its default enabled/disabled state.
#   Options: [Normal Disabled: 0, Normal Enabled: 1, Smart Disabled: 2, Smart Enabled: 3]
fil_runout:3

#### Inverted Filament Runout Sensor Logic
# The sensor uses an inverted logic.
# Disable it in case filament runout is triggered by a LOW signal.
# Enable it in case filament runout is triggered by a HIGH signal.
#   Options: [disable: 0, enable: 1]
# original setting: fil_runout_inverted:1 **NOTE:** I added this line to know the original non-working code
fil_runout_inverted:0

#### NC (Normal Close) Filament Runout Sensor
# The sensor is of type NC.
#   Options: [Normal Open: 0, Normal Close: 1]
#original setting fil_runout_nc:1  **NOTE:** I added this line to know the original non-working code
fil_runout_nc:0

#### Filament Runout Noise Threshold
# Pause print when filament runout is detected at least for this time period.
#   Unit: [time in milliseconds]
#   Value range: [min: 10, max: 1800]
fil_runout_noise_threshold:100

#### Smart Filament Runout Detection
# Used in conjunction with an SFS (Smart Filament Sensor) based on an encoder disc that
# toggles runout pin as filament moves.
#   Unit: [distance in mm]
#   Value range: [min: 1, max: 50]
fil_runout_distance:7

burneme, 2022-09-25:
I had exactly the same problem starting a month ago. Very soon after start the message appeared.
I'm using a BTT TFT70 which has a plug for the smart sensor. I checked the Smart Filament Sensor with scope ( https://forum.duet3d.com/topic/17107/how-to-setup-the-bigtreetech-smart-filament-sensor/37) , the circuit was fine.
Due to the fact that this a direct drive and the smart filament sensor is loosly coupled with the extruder (hanging below the spool), it can happen that the filament is pulled out much when the printhead goes into the corners and it takes some time until new filament is pulled out.
Solution:
I changed
#define FILAMENT_RUNOUT_DISTANCE_MM 7
to
#define FILAMENT_RUNOUT_DISTANCE_MM 50
and it works now.
I do hope that this helps you.

sewflynwa, 2023-07-31:
Just resolved this issue on my Ender 3 Pro with SKR mini right after installing the smart sensor.  I cleared the eprom in Marlin, re-entered my z offset and re-accomplished a bed level.  1st layer filament squares print worked perfectly.  No idea what that fixed, but just glad it did.

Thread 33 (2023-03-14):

Detection Sensor not working on SKR mini e3 Board

Blisk, 2023-03-14:
Filament sensor not working
I have conected filament sensor on E0-STOP and no matter what I do if I manually connect data pin with ground I always get with M119
TRIGGERED.
I checked for stm32f1
pins_BTT_SKR_E3_DIP
#ifndef FIL_RUNOUT_PIN
  #define FIL_RUNOUT_PIN                    PC15   // E0-STOP
#endif
pins_BTT_SKR_MINI_E3_common
//
// Filament Runout Sensor
//
#ifndef FIL_RUNOUT_PIN
  #define FIL_RUNOUT_PIN                    PC15  // E0-STOP
#endif

Blisk, 2023-03-14:
I found out what was wrong. RED pin and WHITE pin was wrongly connected so I changed it on sensor and now works

Closed 2023-03-14.

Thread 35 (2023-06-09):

Configuration with sv06 with klipper

foocross, 2023-06-09:
When I add the following to the klipper printer.cfg:

[filament_motion_sensor encoder_sensor]
detection_length: 7
#   The minimum length of filament pulled through the sensor to trigger
#   a state change on the switch_pin
#   Default is 7 mm.
extruder: extruder
#   The name of the extruder section this sensor is associated with.
#   This parameter must be provided.
switch_pin: PA5
# changing the switch_pin name according to your motherboard
#pause_on_runout: True
#runout_gcode:
#insert_gcode:
#event_delay:
#pause_delay:

I get the following error:
The value 'filament_sensor' is not valid for SENSOR

I can't tell if it is working.

GTreaper, 2023-09-30:
Could you tell me how you connected it to the main board of the sovol?

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

Could you tell me how you connected it to the main board of the sovol?

maydayVFR, 2023-10-08:
I got this same error testing the optical side of the sensor only. I had commented out the switch portion just to isolate the correct pin with fewer variables since sv06 plus was a nightmare to track down the board pinout. With it commented out in printer.cfg my misc-macros file containing the print_start, end etc had no reference to the sensor as it was essentially missing from printer.cfg. Also Check your formatting as I know mine likes to get muddled up by spacing errors especially on mobile edits, as well as spelling, brackets etc.

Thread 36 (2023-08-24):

SFS V2.0 with SKR Mini E3 V3

Devo842, 2023-08-24:
Trying to set up the SFS V2.0 on an SKR Mini E3 V3 and not sure of the wiring. The manual has the wiring from the SFS going to 2 pins on the E0DET and to 2 pins on the E1DET plugs and the SKR Mini E3 V3 uses the E0STOP plug for the filament sensor. I am not sure what wires need to go to what pins for the SFS V2.0. Any help would be appreciated.

So6Rallye, 2023-08-25:
Use this reference for your motherboard : https://github.com/bigtreetech/BIGTREETECH-SKR-mini-E3/blob/master/hardware/BTT%20SKR%20MINI%20E3%20V3.0/Hardware/BTT%20E3%20SKR%20MINI%20V3.0_PIN.pdf

You need to use E0-STOP and PWR-DET

Cable red and blue go to E0-STOP
Cable green and black go to PWR-DET

red + 5V
blue (switch sensor) as equal to PC15 (^PC15)
green (motion sensor) as equal to PC12 (^PC12)
black ground

No need to re-pin the cable for your motherboard.

Devo842, 2023-08-27:
Thanks for your help I got it wired up and working kind of. The sensor does not stay blue all the time and would trip as soon as I started a print. To get passed this I increased the detection distance and could get it to print, I cut some filament to test the sensor and it worked as intended. However, it would still trip when there was no problem. The status light on the sensor would go from blue to off multiple times during the print and would still trip mid print with no printing problems. I have the sensor mounted about 4 inches above my direct drive extruder. When the printer is just sitting on, I can move put pressure on the sensor and get the light to flicker blue and off.  Any suggestions on how to remedy this would be greatly appreciated.

So6Rallye, 2023-08-27:
same problem here, I will work on it today.

So6Rallye, 2023-08-28:
The status light on the sensor from blue to off multiple times during the print is normal. if you can print without issues your config is ok.

Devo842, 2023-08-29:
What is your detection distance set at? I am still getting false trips. I have tried a couple of different filaments and moved my detection distance to 100mm just to try and get it to not false trip. The change does prevent it from tripping as soon as the print starts but it will still false trip shortly into the print, it does resume the print well, but it will still trip again. I was checking to see if it kept tripping in the same spot, but it does not appear to be the case especially after I change the detection distance. Any help would be greatly appreciated.

So6Rallye, 2023-08-29:
this is my config for BTT E3 RRF motherboard:

---------------------------------------------------------------------------
[filament_switch_sensor switch_sensor]
switch_pin: ^PC3
pause_on_runout: False
runout_gcode:
  PAUSE # [pause_resume] is required in printer.cfg
  M117 Filament switch runout
insert_gcode:
  M117 Filament switch inserted

[filament_motion_sensor  encoder_sensor]
switch_pin: ^PE0
detection_length: 20
extruder: extruder
pause_on_runout: False
runout_gcode:
  PAUSE # [pause_resume] is required in printer.cfg
  M117 Filament encoder runout
insert_gcode:
  M117 Filament encoder inserted
---------------------------------------------------------------------------
20 was for the test, think i can reduce to 10. I will try tomorrow.

make sure on **E0-STOP** you have:

blue > ^PC15 left
empty > middle
red > +5v right

**PWR-DET:**

green > ^PC12 left
black > middle
empty > right

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

you can try too set pin ^PC12 to !PC12.

Tell me what's happen with all this infos.

Devo842, 2023-08-30:
So are you using Klipper then, I am using Marlin, either way this gives me some ideas, I will give it a try and let you know how it turns out. I might not be able to get to it till the weekend.

maksii, 2023-09-07:
@Devo842 Did you get it to work?
 the switch works fine for me, but the encoder is always in the detect state.

Devo842, 2023-09-07:
I am still working on it. I tried some firmware changes, and I am still struggling. Any suggestions would be greatly appreciated.

maksii, 2023-09-08:
It's strange how it works, but I can't get it to work without false positives on values less than 30. At 50, it's stable.
This is good, of course, but 50 is not ~3, so it doesn't make much sense to unpause after such a skip.

Anyway, thanks to @So6Rallye for information.

jfml2020, 2023-09-29:
Something to keep in mind is to look at the mines if the wiring has been changed from the factory connector, the blue light remains fixed and will not flash when moving the filament.

These types of sensors are designed to be next to the extruder to prevent excess filament after moving the extruder from giving an error and pausing.... I have a bontech ddx and I put a sensor on the upper part of the box where I have the printer and I put a Teflon tube from the sensor to the DDX direct extruder so the filament is kept at a certain size and the sensor will always measure the movements. I have it at 3mm working.

sewflynwa, 2024-02-29:
Devo842,
Did you ever get the SFS 2 working correctly?

I have the same board with mine and just cannot get it to work.  The sensor is mounted on top of the extruder and indicates correctly, blinking blue when feeding and solid red when no filament, so I am confident it is wired correctly.  My problem is likely firmware related since the printer never responds to the jam or filament loss, just keeps running merrily along, oblivios to lack of filament.

Very interested in your firmware changes.

jfml2020, 2024-02-29:
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

If I have it working 100%, the error is that they do not explain how to use it. Module A is fixed in the printer structure and with a tube as the filament to detect movement 2.8mm Filament a to be in tube Ptfe So motion detector detects it.

sewflynwa, 2024-03-01:
Thank you for looking.

I made changes to 2 files in Marlin, Config.h and Pins.  There were no changes to Config_adv.h.  There were other changes not shown here specific to my extruder for loading and unloading distances and feed rates etc., but those should not affect the sensor working/tripping a runout.

Inputs welcome...

Configuration.h changes
#define FILAMENT_RUNOUT_SENSOR   //Uncommented
#define FILAMENT_RUNOUT_DISTANCE_MM 3  //Uncommented, 3
#define FILAMENT_MOTION_SENSOR  //Uncommented
#define FILAMENT_SWITCH_AND_MOTION  //Uncommented.
#define FIL_MOTION1_PIN   PC12  //Uncommented, changed -1 to PC12 for movement sensor
#define FIL_MOTION1_PULLUP   //Uncommented
#define ADVANCED_PAUSE_FEATURE //already uncommented

Configuration_adv.h changes
#define ADVANCED_PAUSE_FEATURE //already uncommented

Svc/pins/STM32G0/pins_BTT_SKR_Mini_E3_V3_.0h changes
 #define FIL_RUNOUT_PIN       PC12  //changed from PC15.  //E0-STOP
 #define POWER_LOSS_PIN     -1  //changed from PC12, Power Loss Detection: PWR-DET

sewflynwa, 2024-03-02:
SFS 2 works perfectly!!  But not when running the machine from the TFT 35 touchscreen in other than Marlin mode.  In Marlin mode, the SFS motion sensor kicks in, M600 kicks in and unloads the filament, insert new filament prompt, put in new filament, and off it goes.  Happy about it working at least, I have some lengthy prints I was reluctant to start without a full spool of filament.  Now I am going to have to shift gears and start looking at the TFT 35.  There has to be some kind of pin conflict.
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
viyer00, 2024-03-06:
The above settings have been working flawlessly for me in Marlin mode on the TFT35 E3 v3 over long prints at 4mm distance. However, I've had some strange problems when switching between touchscreen mode. In the middle of a print today, I switched to touchscreen mode, reenabled the filament sensor (that setting does not automatically carry over from Marlin), and had no problems for over an hour. I switched back to Marlin mode during that same print, and some minutes later the screen had artifacts and froze, apparently triggering some part of the filament sensor and throwing up all sorts of "paused click to continue" on the Marlin screen and in Octoprint. On the 20th try of me pressing continue it finally registered the input and went back to printing. The filament sensor is still enabled, and I think this print will end up fine,

jfml2020, 2024-03-06:
> The above settings have been working flawlessly for me in Marlin mode on the TFT35 E3 v3 over long prints at 4mm distance. However, I've had some strange problems when switching between Marlin and the touchscreen mode on the TFT. In the middle of a print today, I switched to touchscreen mode, reenabled the filament sensor (that setting does not automatically carry over from Marlin), and had no problems for over an hour. I switched back to Marlin mode during that same print, and some minutes later the screen had artifacts and froze, apparently triggering some part of the filament sensor, nozzle park, and eventually throwing up all sorts of "paused click to continue" on the Marlin screen and in Octoprint. On the 20th try of me pressing continue it finally registered the input and went back to printing. The filament sensor is still enabled, and I think this print will end up fine, but staying in Marlin mode definitely seems more stable.

Since it comes out from the sensor to the strusor, is the filament free without a tube? When doing reactions, if the filament comes and goes but the sensor does not, if it does not have a tube, the filament bends when retracting, The sensor does not detect these small movements because the filament twists or bends to the sides, the tube means that the filament is always detected leaving and entering by the movement sensor.

leonardojc, 2024-05-21:
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

Hello @sewflynwa,  have you been able to solve this? I'm with the same problem

I see that in your definitions you use the same PIN for both sensors. this is correct?
in Configuration.h
**#define FIL_MOTION1_PIN PC12** // changed -1 to PC12 for movement sensor
and in pins_BTT_SKR_Mini_E3_V3_.0h
**#define FIL_RUNOUT_PIN PC12** //E0-STOP

sewflynwa, 2024-05-22:
I have not been able to solve the problem.  The sensor does work correctly when the machine is running in Marlin mode.  This requires use of the mini plug on the front of the machine to load the files which is something I wanted to stop doing with the TFT35.

The pin being assigned to both snsors has not been a problem for me.  Again, if the machine is running in Marlin mode.  When the machine is running in touch mode, the sensors simply do not stop the print when tripped.

The real problem appears to be the way the TFT Board interfaces with the motherboard when the machine is running in touchscreen mode.  Of course, this is the mode required to use the SD and USB ports on the TFT35.  I am hopeful that a later TFT 35 firmware version will fix the issue.  For now, I just use Marlin mode when it appears there may not be enough filament on the spool to complete the print.

Coolbobjoe, 2024-09-12:
I have bought two now, neither will ever turn their blue lights on nor show up on klipper. support has went awol on email

sewflynwa, 2024-09-13:
Unfortunately, not familiar with Klipper and I gave my machine to a youngster 2 weeks ago for him to use in his high school technology class.  I  moved to a Prusa mK4.  However, I do recall I found the SFS wiring to the E3V3 board was very confusing for me.  That, and the changes required for the Marlin firmware yielded many starts with no lights before I got it correct.

BTT support checked out on me as well when the issue started looking more and more like a compatibility problem with the board, TFT 35 touch screen, and the SFS 2.0 when operating in touch mode.  As I mentioned above, marlin mode worked as expected.

jfml2020, 2024-09-13:
Remember that if you do not have Teflon tube between the sensor and the extruder you will have false negative problems or the sensor is placed directly on top of the extruder or the tube is placed between the extruder and the sensor so that filament slides back and forth millimeters on sensor.

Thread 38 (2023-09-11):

cr4ns200141c13 on ender 5 s1 config klipper for sfs v2.0

eduardloskutov, 2023-09-11:
Where to connect to the cr4ns200141c13 board and how to configure klipper for it

eduardloskutov, 2023-09-12:
When connected to the cr4ns200141c13 ender 5s1 board, no LED lights on the sensor. 5 volts on the red wire from the board comes to it. What's wrong? Is it broken?

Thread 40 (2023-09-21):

SKR Pico Connection?

dgpmaluco, 2023-09-21:
Dear BTT,

how would you connect the SFS 2.0 to a SKR Pico?

best regards

jonathanalevi, 2023-09-27:
Add this to the appropriate config file on YOUR setup (on mine it's sky-pico-v1.0.cfg)

```
[filament_switch_sensor switch_sensor]
switch_pin: ^gpio16 # as shown in Figure 2, switch sensor I is PAO
pause_on_runout: False
runout_gcode:
  PAUSE # [pause resume] is required in printer.cfg
  M117 Filament switch runout
insert_gcode:
  M117 Filament switch inserted

[filament_motion_sensor encoder_sensor]
switch_pin: ^gpio20 # as shown in Figure 2, motion sensor IO is PC2
detection_length: 2.88 # accuracy of motion sensor 2.88mm
extruder: extruder
pause_on_runout: False
runout_gcode:
  PAUSE # [pause resume] is required in printer.cfg
  M117 Filament encoder runout
insert_gcode:
  M117 Filament encoder inserted

```

And here's what it should look like with yellow highlights to point out:
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

Someone at BTT should add this as a sample config. I don't know how to submit a pull request, I'm not a programmer.

dgpmaluco, 2023-09-27:
Thanks I will try this!

SirRenix, 2023-10-12:
Unfortunately this will not work with the standard cabling on FAN3 of Voron V0.2 config, because according to schematic this port GPIO20 is linked with the laser port. Furthermore Klipper gives an error message that the port is already occupied. You are not allowed to connect a fan on FAN3 and have to switch to FAN 2/1.

idubrov, 2024-02-16:
>Not sure if GPIO29_ADC being an ADC port will cause an issue or not.

Oh yes, it will. Apparently, GPIO29 is used internally by RP2040 to measure VSYS, and connecting it as a digital input messes up thermistor reads somehow, causing Klipper to crash with "ADC out of range".

However, there is a pin header on a board with GPIO22 on the middle pin -- this one could be used for encoder. I re-pinned the connectors such that one connector, JST, got red/black/blue and is plugged into E0 stop and another connector, Dupont, gets a single wire, green, going to that middle pin with GPIO22.

anthonielamay, 2024-03-19:
Has there been any updates or solutions for any of you?

howdy-vulcan, 2024-05-25:
I got this working for anyone who is looking to connect the BTT smart filament sensor to a SKR Pico.  There doesnt seem to be enough points for a correct separate connection.  I was able to feed a needle though the connection and swap the pins around on the Motion / GND connnection.  I matched the RGB connection layout per the pinout diagram on the Pico (next to the E0 endstop)    and activated it via that pin. Changing the connector pins allows for more ports to be used.

Sentinel-sys, 2024-06-14:
> I got this working for anyone who is looking to connect the BTT smart filament sensor to a SKR Pico. There doesnt seem to be enough points for a correct separate connection. I was able to feed a needle though the connection and swap the pins around on the Motion / GND connnection. I matched the RGB connection layout per the pinout diagram on the Pico (next to the E0 endstop) and activated it via that pin. Changing the connector pins allows for more ports to be used.

Hi there,

could you please go into more details please. I have the same problem here. I used 5 Volt and GPIO16 from the E0-Stop port and GND and GPIO26 from the SERVOS port.
It seems this triggers a restart from the Pico board. Or better, Klipper reports an MCU shutdown.

Thank you

Joe

idubrov, 2024-06-14:
> could you please go into more details please.

The key moment here is that you cannot use 5V supply for the sensor if you want to use SERVOS (GPIO29) port.

@howdy-vulcan seems to be using RGB port (which was not available in my case).

[I used GPIO22](https://github.com/bigtreetech/smart-filament-detection-module/issues/40#issuecomment-1947788690) instead of GPIO29 (SERVOS), and it works fine since. Look for the [P_S IO22 PROBE](https://github.com/bigtreetech/SKR-Pico/blob/master/Hardware/BTT%20SKR%20Pico%20V1.0-PIN.pdf) connector on the diagram.

Now that I think about it, maybe a simpler solution would be to put switch encoder on GPIO29 (SERVOS) and motion sensor on GPIO16 (E0 stop). If encoder switch button is wired the way buttons are commonly wired (normally connected, signal to ground), there will be no issue with 5V flowing back through the button. And GPIO16 should be able to handle 5V flowing back into it. But need to check if button is actually wired that way.

Sentinel-sys, 2024-06-14:
> Now that I think about it, maybe a simpler solution would be to put switch encoder on GPIO29 (SERVOS) and motion sensor on GPIO16 (E0 stop). If encoder switch button is wired the way buttons are commonly wired (normally connected, signal to ground), there will be no issue with 5V flowing back through the button. And GPIO16 should be able to handle 5V flowing back into it. But need to check if button is actually wired that way.

I'm a bit rusty when it comes to this. But just tell me what I need to measure and I'll do it for you.

Greetings
Joe

Sentinel-sys, 2024-06-14:
> [I used GPIO22](https://github.com/bigtreetech/smart-filament-detection-module/issues/40#issuecomment-1947788690) instead of GPIO29 (SERVOS), and it works fine since. Look for the [P_S IO22 PROBE](https://github.com/bigtreetech/SKR-Pico/blob/master/Hardware/BTT%20SKR%20Pico%20V1.0-PIN.pdf) connector on the diagram.

Do you used GND from the E0-Stop? Because I did this now (GND, 5V, GPIO16 from E0-Stop) and GPIO22 from PROBE. Switch is working Encoder not.

Sentinel-sys, 2024-06-14:
> When you say encoder doesn't work, do you get blinking from it at all (when you move filament through it, it should blink LED in the sensor itself)?

Red light for the switch is working when no filament is present. But no blue light at all.

idubrov, 2024-06-14:
>Switch is working fine. I see the red light when no filament is loaded and in Klipper it shows as "Empty". Encoder light is blue blinking when filament is pushed trough but I don´t know how to test the encoder inside Klipper. It always says "Detected".

It will only detect when you ask it to extrude filament, but no motion is detected. Remove your filament from the extruder (but maybe leave it in the switch so it still shows "detected"), extrude some length, and see if it goes into "not detected" for the motion sensor.

Sentinel-sys, 2024-06-14:
I almost thought so. Only the combination of "extruding" and "filament not moving" triggers the alarm...
Good to know.
Many thanks for your help. I think that works for me so far.

> P.S. Also, maybe measure a voltage between GND and the switch wire to make sure it is not feeding 5V back.

I measure around 3.5V between GND and the switch pin and around 4.5V between GND and the encoder pin.

idubrov, 2024-06-14:
>I measure around 3.5V between GND and the switch pin and around 4.5V between GND and the encoder pin.

That is still more than 3.3V. I guess, that red LED is what provides that connection from 5V. Well, if you don't see any voltage-induced errors (like temperatures jumping around), then it's fine. Or you can go back to GPIO22 idea. Not sure why didn't it work for you...

Sentinel-sys, 2024-06-14:
Okay thank you. I will finish my build and amke some more tests. Maybe I switch back to your idea.

howdy-vulcan, 2024-06-14:
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

So I actually had the same thing happen, the encoder  kept triggering a pause (though had correct red/ blue lights)  so i commented out the encoder from the config, and removed the black / green lines. i had connected to the RGB Port on PIco.   For last few weeks, no issues with this.   I ended up installing some Neopixels Strips  and Servos for Nozzle Wipe + Zeroclick Probe on the Pico with some additional ports from Klipper Expander

IMO  even though i didnt get the encoder working right,  for a V0 - its small and prints so fast that consequences of a tangle or breakage are not terrible in most cases.

my config  sections for reference with rough debug messages:

```
[filament_switch_sensor switch_sensor]
switch_pin: ^gpio16
pause_on_runout: False
runout_gcode:
 PAUSE # [pause_resume] is required in printer.cfg
  M117 Filament switch runout
  M118 Filament Switch Triggered RUNOUT
insert_gcode:
  M117 Filament switch inserted
  M118 Filament Inserted

#[filament_motion_sensor encoder_sensor]
#switch_pin: ^gpio24
#detection_length: 5
#extruder: extruder
#pause_on_runout: False
#runout_gcode:
 # PAUSE # [pause_resume] is required in printer.cfg
 # M117 Filament encoder runout
#  M118 FILAMENT encoder runout
#insert_gcode:
#  M117 Filament encoder inserted
#  M118 FIlament encoder detected

```

jeffctr, 2024-08-14:
`^gpio16 for switch_sensor and ^gpio29 for encoder_sensor` will work perfectly

ansi1986, 2025-03-31:
Hello,

can I also use ^gpio16 and ^gpio25 ?

Thanks

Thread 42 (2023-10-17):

Install SFS v2 on Artillery Sidewinder X2?

Ltek, 2023-10-17:
Anyone know how to install the SFS v2 on an Artillery Sidewinder X2?

Ltek, 2023-10-27:
Not one person has installed this on an Artillery Ruby board?

GrandSam14, 2023-12-01:
Hi,

Same request, any help will be welcome to install on Artillery SideWinder X2 and Ruby board.

Very disappointing to let my fresh bought SFS V2 in a drawer till any solution to use with my X2 -_-

Ltek, 2023-12-10:
Conclusion: Doesn't work on Sidewinder X2.

I spent many hours testing different klipper code but have not found any way to make the motion sensor will work with the X2. It always triggers immediately after the filament purge no matter what I do. I can properly enable/disable it... and the code detects the sensor but if its enabled, it always triggers after purge. If you enable it only after the layer starts it will work but it maybe false trigger, I dont know. I no longer have an X2 so cannot do anymore testing.

ovar0409, 2023-12-30:
Hi LTek, I'm just curious... how did you connect the SFS on the Ruby board? I guess Z endstop (pin ^PA0) but which other pin for the motion sensor?
Can you also describe you printer.cfg configuration?

eugeniomiro, 2025-10-02:
I have the same question. I'm using Klipper, though. I don't know your case.

Checking the Artillery Ruby pinout [here](https://www.reddit.com/r/Artillery3D/comments/w7wb6d/artillery_ruby_12_motherboard_pinout/), I see the UART socket could be used for this, and also the EXP sockets. I haven't tried it yet, but I'll do so soon and leave a comment here when done.

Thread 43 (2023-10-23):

BTT 2.0 with Creality 4.2.7 system board

TacII, 2023-10-23:
Hello!

I recently purchased a BTT SFS v2.0 and I have a Creality v4.2.7 system board. The manual says, “To connect to a motherboard without filament runout port, please consult our technical support.”.

The Creality v4.2.7 system board only has a filament runout sensor (circled) which I ran successfully with the BTT Sensor v1 and Klipper.
Now, the blue light is constantly on and never blinks on the sensor when I connect one of the two cables. With the other one the sensor is just black.

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

I’ve tried using both firmware modifications for Klipper,  [filament_motion_sensor] and [filament_switch_sensor] in printer.cfg (with everything that goes beneath them). I used own a BTT v1.0 so I’m fairly familiar with the setup.
The Creality system board filament sensor PIN is called PA4 and I’ve tried “PA4” and “^PA4” with both cables. I feel like I’m missing something here since there are two cables but only one that can be connected. Please advise.a

Ltek, 2023-10-27:
I have this same problem just with the Artillery Sidewinder X2... I don't think they really support the product. They clearly do not monitor this site at all. And over a week I put in a tech support ticket I entered on their site - they have never responded.

TacII, 2023-10-28:
Believe it or not, I actually got it to work today. I needed to resolder a cable to get both sensors to work on the Ender3 v4.2.7 system board. I’ll post more details here as soon as I have time.

negativefate83, 2023-10-29:
> Believe it or not, I actually got it to work today. I needed to resolder a cable to get both sensors to work on the Ender3 v4.2.7 system board. I’ll post more details here as soon as I have time.

mate if you could, youd be a life saver
just unboxed the sfs 2.0 and now im just scratching my head questioning my life choices

TacII, 2023-10-29:
I feel you. As everyone who owns a 3D-printer, I was standing at the cliff of despair myself. So here's how I did it, for the Creality 4.2.7 system board. You need to free up one pin-pair on the system board, which you already did if you own a BL/CR-Touch, then the Z- pin-pair should be available.

The Black and Green contact (the motion sensor) should go to the Z- pin pair on the board. It's three pins wide so you need to either cut the outer part of the contact with a sharp pair of scissors (quite easy actually) or solder on a two pin contact to the black and green wires. Black is ground and should be on the left, Green is PA7 and should be on the right.

Here's what the wiring looks like from the manual.
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

This is where the Motions Sensor Cable goes on the system board.
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

The Blue and Red wire pair (Switch Sensor) goes the the filament runout port on the system board and can be inserted as normal.
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

Then you'll need this in printer.cfg in Klipper. Sorry I don't use Marlin anymore but I think you could probably follow the manual and use PA4 for the Switch Sensor and PA7 for the Motion sensor.

```
#Switch sensor, blue @PA4 + red VCC 3,3V
[filament_switch_sensor btt_switch_sensor]
switch_pin: ^PA4
pause_on_runout: false
runout_gcode:
  M117 Switch Runout!
  {action_respond_info("BTT: Switch Runout detected!")}
  PAUSE
insert_gcode:
  M117 Filament inserted
  {action_respond_info("BTT: Filament inserted.")}

#Motion sensor, Green @PA7 +Black GND
[filament_motion_sensor btt_motion_sensor]
switch_pin: ^PA7 # Previous Z- on 4.2.7
detection_length: 2.88 # accuracy of motion sensor 2.88mm
extruder: extruder
pause_on_runout: false
runout_gcode:
  M117 Motion Runout
  {action_respond_info("BTT: Motion Sensor Runout detected!")}
  PAUSE
insert_gcode:
  M117 Filament inserted
  {action_respond_info("BTT: Filament inserted.")}

[delayed_gcode DISABLEFILAMENTSENSOR]
initial_duration: 1
gcode:
    M117 Motion FIL. SENSOR OFF.
    SET_FILAMENT_SENSOR SENSOR=btt_motion_sensor ENABLE=0
    SET_FILAMENT_SENSOR SENSOR=btt_switch_sensor ENABLE=0
```

And for START you will have to add two lines more:

```
######################################################################
# Start Print and End Print
######################################################################

# Replace the slicer's custom start and end g-code scripts with
# START_PRINT and END_PRINT.

[gcode_macro START_PRINT]
variable_bed_temp: 60
variable_extruder_temp: 185
gcode:
    # Start bed heating
    M140 S{bed_temp}
    # Use absolute coordinates
    G90
    # Reset the G-Code Z offset (adjust Z offset if needed)
    SET_GCODE_OFFSET Z=0.0

    ## Home the printer
    G28

    # Reset Extruder
    G92 E0

    ## Move to start position
    G1 X2.1 Y20 Z0.28 F5000.0

    # Move the nozzle near the bed
    G1 Z5 F3000
    # Move the nozzle very close to the bed
    G1 Z0.15 F300
    # Wait for bed to reach temperature
    M190 S{bed_temp}
    # Set and wait for nozzle to reach temperature

    #KAMP Calibrate print area only
    BED_MESH_CALIBRATE

    M109 S{extruder_temp}

    # Move Z Axis up
    G1 Z2.0 F3000

    #KAMP Line Purge
    LINE_PURGE

    SKEW_PROFILE LOAD=my_skew_profile_231010

    _M117 BTT SENSOR ON.
    SET_FILAMENT_SENSOR SENSOR=btt_motion_sensor ENABLE=1
    SET_FILAMENT_SENSOR SENSOR=btt_switch_sensor ENABLE=1
```
For CANCEL:
```
[gcode_macro CANCEL_PRINT]
description: Cancel the actual running print
rename_existing: CANCEL_PRINT_BASE
gcode:
    TURN_OFF_HEATERS
    CANCEL_PRINT_BASE
    M117 MOTION FIL. SENSOR OFF.
    SET_FILAMENT_SENSOR SENSOR=btt_motion_sensor ENABLE=0
    SET_FILAMENT_SENSOR SENSOR=btt_switch_sensor ENABLE=0
```
And lastly for END:
```
# ---------------------------- End Print -----------------------------
[gcode_macro END_PRINT]
variable_machine_depth: 235
gcode:
    # Turn off bed, extruder, and fan
    M140 S0
    M104 S0
    M106 S0
    # Relative positionning
    G91
    # Retract and raise Z
    G1 Z0.2 E-2 F2400
    # Wipe out
    G1 X5 Y5 F3000
    # Raise Z more
    G1 Z10
    # Absolute positionning
    G90
    # Present print
    G1 X0 Y{machine_depth}
    # Disable steppers
    M84
    M117 BTT SENSOR OFF.
    SET_FILAMENT_SENSOR SENSOR=btt_motion_sensor ENABLE=0
    SET_FILAMENT_SENSOR SENSOR=btt_switch_sensor ENABLE=0
```

negativefate83, 2023-10-29:
mate, to say im grateful doesnt even come close
love your work, thankyou so much

TacII, 2023-10-29:
It seems that I haven't really got the motion sensor working fully as I thought yesterday. Sometimes it is detected and sometimes not (often it is there after a firmware restart.) But as soon as it starts printing it is empty. Not sure what is going on here. I'll dig on. At least the Switch works which is more important, so if the printer runs out of filament it'll pause the print.

negativefate83, 2023-11-04:
Hey mate how’d you go getting it sortedHaven’t even gotten around to putting my sensor in yet but the plan is to make a move todaySo what do you suggest… don’t even bother with the motion sensor and just run the switch on its own?On 29 Oct 2023, at 18:25, MathiasH ***@***.***> wrote:
It seems that I haven't really got the motion sensor working fully as I thought yesterday. Sometimes it is detected and sometimes not (often it is there after a firmware restart.) But as soon as it starts printing it is empty. Not sure what is going on here. I'll dig on. At least the Switch works which is more important, so if the printer runs out of filament it'll pause the print.

—Reply to this email directly, view it on GitHub, or unsubscribe.You are receiving this because you commented.Message ID: ***@***.***>

TacII, 2023-11-07:
~PA7 instead of ^PA7 for the motions sensor actually makes Klipper detect filament - visible under the Misc part on the dashboard but also through the command "QUERY_FILAMENT_SENSOR SENSOR=btt_motion_sensor".
But as soon as it starts printing it fails after the set "detection_length".

From the Klipper manual :
_Input pins may be preceded by ^ to indicate that a hardware pull-up resistor
should be enabled for the pin. If the micro-controller supports pull-down resistors then an input pin may
alternatively be preceded by ~. Pin names may be preceded by ! to indicate that a reverse polarity should be
used (eg, trigger on low instead of high)._

I've also tried ^!PA7 and ~!PA7 which than makes the sensor detect a runout immediately but the sensor is not true. ^PA7 should be correct. The Z- pin should be a pull-up resistor after what I've read. But no setting I tried has made the blue led flash as it should when filament is passing by it. One thing that might work that I haven't tried is to switch the motion-cable and switch sensor cable but that requires new soldering of the contacts since the switch sensor cable contact has three poles and won't fit into the Z- port.

I'm quite disappointed in BTT who haven't answered my support request two weeks ago. They're not active here or on Discord.

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

Ltek, 2023-11-07:
Guys, I've been trying to get this working on an Artillery Sidewinder X2 (running Klipper) -- I suspect we have similar or identical problems. It does not detect motion for me, and Pauses immediately after purging the nozzle.

The X2 only has 1 Z-Stop connector I can use for the Motion Sensor, thus the SFSv2's Runout wire/pin is not connected.

Is there code we can use to test the filament sensor without printing... just moving the filament in/out by hand?

shaidou1287, 2023-11-10:
So, I got this working on a Creality 4.2.7 board. What I did was just set the PIN to the Z-Stop pin PA7, no pull-up or pull-down. I have tested it multiple times mid-print and it will pause the print and wait for me to resume it. Hope this helps those who are having issues. BTW this was on Klipper.

TacII, 2023-11-10:
But have you got the motion sensor to work? The blue light should be blinking while you print.
________________________________
Från: shaidou1287 ***@***.***>
Skickat: Friday, November 10, 2023 8:30:17 PM
Till: bigtreetech/smart-filament-detection-module ***@***.***>
Kopia: Mathias Haas ***@***.***>; Author ***@***.***>
Ämne: Re: [bigtreetech/smart-filament-detection-module] BTT 2.0 with Creality 4.2.7 system board (Issue #43)

So, I got this working on a Creality 4.2.7 board. What I did was just set the PIN to the Z-Stop pin PA7, no pull-up or pull-down. I have tested it multiple times mid-print and it will pause the print and wait for me to resume it. Hope this helps those who are having issues. BTW this was on Klipper.

—
Reply to this email directly, view it on GitHub<https://github.com/bigtreetech/smart-filament-detection-module/issues/43#issuecomment-1806323598>, or unsubscribe<https://github.com/notifications/unsubscribe-auth/AKM7YHG6FLAX3HG4V4RR5ETYDZ6ETAVCNFSM6AAAAAA6MYMDYGVHI2DSMVQWIX3LMV43OSLTON2WKQ3PNVWWK3TUHMYTQMBWGMZDGNJZHA>.
You are receiving this because you authored the thread.Message ID: ***@***.***>

shaidou1287, 2023-11-10:
Yeah, the blue light is blinking and if I hold the extruder open so filament won't go through it runs my pause macro.

TacII, 2023-11-11:
Wow, interesting! Can you please share the details? So motion sensor cable (green+black) to PA7, right? And blue+red switch sensor cable to PA4 I assume? Or aren't you using the switch cable at all?

Can you please drop in your printer.cfg here so that I can compare the differences? Because I tried all combinations of Pull up/down.

Thanks!

negativefate83, 2023-11-11:
Interesting…

shaidou1287, 2023-11-14:
Sorry for the Delay but here is the section of the Printer config I have for the sensor. The rest is just the basic Ender 3 V2 config from the example w/ a CR Touch added.

`# Runout Sensor #########################################################################
[filament_switch_sensor switch_sensor]
switch_pin: PA4
pause_on_runout: False
runout_gcode:
  PAUSE # [pause_resume] is required in printer.cfg
  M117 Filament switch runout
insert_gcode:
  M117 Filament switch inserted
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

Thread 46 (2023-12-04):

SFS 2.0: filament path, a design flaw - filament hits walls near output holes

arekm, 2023-12-04:
That's one big problem with SFS2.0 filament sensor. Pain to use.

Current design of output holes in filament path is like this:

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

Just a small diameter hole. That filament needs to hit in perfectly.

In my experience, especially when having longer PTFE tubes installed on both ends of SFS2.0 sensor it is almost impossible to push filament out via that hole. That's because even tiny curvature of filament (by that I mean just filament taken from spool - it won't be straight, it will take a shape of spool) or side tension on filament causes it to hit a wall on left/right side of that exit hole.

I have to unplug PTFE tube on "entry" side and manoeuvre filament blindly inside SFS2.0 sensor, so it finally hits the exit hole of the sensor. It's pure pain to do that each time.

Perhaps a funnel shape would be better, directing the filament from the edges and directing it towards the center of the exit hole.

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

Consider such improvement on 2.1 iteration.

(In theory we could just improve and print own, better case for it but CAD model is broken (https://github.com/bigtreetech/smart-filament-detection-module/issues/45))

osvch, 2024-04-19:
I'm facing this issue heavily- I'm happy that it was already posted.
@bigtreetech what would be mitigation plan for the users?

roykrikke, 2024-04-22:
+1

2Balu2, 2024-05-15:
+1

osvch, 2024-05-18:
> +1

> +1

I tighten the PTFE connectors, and before filament insertion- I straighten it as much, as I can- that helps a let with filament transition.

osvch, 2024-05-18:
@2Balu2 @roykrikke
I tighten the PTFE connectors, and before filament insertion- I straighten it as much, as I can- that helps a let with filament transition.

noobydp, 2024-07-05:
Try rotating the sensor 180 degrees, and shove the filament in the other direction.

LsHallo, 2025-01-13:
Do you thinks its possible to disassemble the sensor and use a small drill bit to kind of create this funnel shape?
This sensor is driving me mad every time i have to insert filament...

osvch, 2025-01-13:
I got update on my sensor and  I was able to address all issues:

- Circle part "button" on the sensor front side fell off (marked red at the photo), I disassebmled sensor, tighten everything again
- I rotated my sensor to infeed filamnet horizontally (cable connector facing down)
- Make sure at least 4-5cm of filament you are inserting is straight
- Tighten the PTFE tube connectors

After those steps I do not see issues with inserting the filament like before.

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

2Balu2, 2025-01-13:
Thanks. I did use a dremel to create a smoother transition/bigger inlet.

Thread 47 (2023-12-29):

Creality K1? Can the sensor be used if only filament runout pins are available?

Horgul123, 2023-12-29:
The Creality K1 seems to have no spare port for the motion detection.
Is there a way to use the sensor with this printer?
Or in general:
Is there a way to use the sensor if only a "normal" filament runout sensor can be installed? (e.g. sensor triggers the filament runout if there is a filament runout OR motion issue)

The-last-phantom, 2024-01-18:
Big Tree Tech will tell you the K1 cant support the SFS 2.0, but I can confirm the SFS 2.0 works perfectly on the K1 Max. On the standard K1, you might have to just lose the switch and only use the motion sensor. On the Max you can use both.

It's simply a case of de-pinning the SFS connectors, and repinning them to suit the K1. The connector bodies are too big for the ports on the motherboard, you would either need to get smaller connectors or I simply put a piece of heat shrink over each pin so they dont accidentally touch each other. The Max has the second filament sensor port on the toolhead PCB, so this can be used to get both sensor signals.

On the Max motherboard (I imagine this is the same for the standard K1, but I would still double check), the 5V VCC comes from the pin closest to the WIFI antenna, the GND is the centre pin, and the signal is the last pin. So simply de-pin the SFS connectors, and plug the red wire onto the pin closest to the WIFI antenna, the black wire onto the centre pin, and the green wire onto the last pin. If you want to use the blue wire to get the runout switch, you would need to separate it from the other wires and run it to the toolhead PCB - I simply folded it back and left it unconnected. Then the SFS 2.0 harness is the perfect length to run back the exact same route as the stock filament sensor harness, and the sensor body *just* fits where the stock sensor sits with a custom bracket (the extruder can make contact with the bulge on the body here, and you want to be careful to not sit the sensor on the belt). If you want to mount it externally, you will probably need to extend the harness a bit.

The rest of the install is as per the manual, make the changes to your printer.cfg file. If you've wired it as I've described, then your motion sensor is on pin PC15.

All up, took me about two hours to install including the time to work out the pinouts on the motherboard. Super easy.

Horgul123, 2024-01-19:
Thanks a lot for this detailed explanation!
So just for my understanding:
It doesn't detect a filament runout via the switch but the printer will check if there is a filament movement when there should be one. And if there is no movement (no filament or filament blocked) it will raise a "out of filament" error.

The-last-phantom, 2024-01-20:
Yeh, correct. The motion sensor alone can do the same task as the switch - if the filament runs out or breaks, the motion sensor will trigger. If the filament jams in the extruder or snags at the spool, the motion sensor will trigger.

The only somewhat downside is that it may sometimes trigger a false positive, which tends to happen in parts of the model where the printer is doing a lot of retractions and the sensor doesn't pick them up. This can be tuned out by playing with the detection length, but it means spending a bit of time testing. At the moment, I haven't had a false positive since raising the detection length from the minimum 2.88mm to 3.5mm, but I've only done about 2.5 hours of printing since I made that change.

I am also using this in conjunction with Henlor's extruder runout sensor mod that you can find on Printables, which puts a micro switch into the extruder housing that then plugs into the port on the toolhead PCB. The reason I like this instead of just using the BTT micro switch, is it means the printer will only detect a runout right at the toolhead rather than at the back of the printer enclosure. It also means I can enable automatic filament loading, so the printer will automatically load and extrude a defined length of filament when the switch is triggered. And finally, it means I can bypass the reverse bowden tube when using TPU, which would mean that I have to disable the motion sensor as there is no filament running through it. This then provides a bit of safety for having a runout while using TPU.

Selberg666, 2024-01-31:
Hy guys!
I just bought a SFS 2.0 and want to install it on K1 Max.
Sooo if i connect the blue wire to the signal pin from the tool head it will activate the switch from SFS?
I don t mind to run 1 wire to the tool head....
Also.....found out on K1 the middle pin is signal and the last pin is ground......so i heard from someone that put SFS 1 on a K1.

Selberg666, 2024-01-31:
If the tool head pin is PA10...
Then the klipper line to add is this?

[filament_switch_sensor switch_sensor]
#BLUE WIRE ON TOOL HEAD
switch_pin: PA10
pause_on_runout: True
runout_gcode:
  PAUSE # [pause_resume] is required in printer.cfg
  M117 Filament switch runout
insert_gcode:
  M117 Filament switch inserted

[filament_motion_sensor encoder_sensor]
switch_pin: PC15
detection_length: 2.88
extruder: extruder
pause_on_runout: True
runout_gcode:
  PAUSE # [pause_resume] is required in printer.cfg
  M117 Filament encoder runout
insert_gcode:
  M117 Filament encoder inserted

Horgul123, 2024-02-03:
@The-last-phantom I have some problems with the config.
Could you please show me your entry in the printer.cfg? Did you do any additional changes?

I tried to copy the things from the BBT manual but I get:
`{"code": "key342", "msg": "Option 'detection_length' is not valid in section 'filament_switch_sensor filament_sensor'\n\nOnce the underlying issue is corrected, use the \"RESTART\"\ncommand to reload the config and restart the host software.\nPrinter is halted\n", "values": ["detection_length", "filament_switch_sensor filament_sensor"]}`

Selberg666, 2024-02-03:
I had succes with this line

[filament_motion_sensor encoder_sensor]
switch_pin: !PC15
detection_length: 3.2
extruder: extruder
pause_on_runout: true
runout_gcode:
  {% if printer.extruder.can_extrude|lower == 'true' %}
    G91
    G0 E30 F600
    G90
  {% endif %}

[filament_switch_sensor filament_sensor_2]
pause_on_runout: true
switch_pin: nozzle_mcu:PA10
runout_gcode:
  {% if printer.extruder.can_extrude|lower == 'true' %}
    G91
    G0 E30 F600
    G90
  {% endif %}

the mount for the sensor i designed it myself...here is a link
https://www.printables.com/model/747290-bigtreetech-sfs-v20-bracket-mount-on-creality-k1-m

Horgul123, 2024-02-03:
Thanks a lot!
Will try your code :) And thanks for the mount. Will print it tomorrow and check if it works on a K1 (not max)

Selberg666, 2024-02-03:
it should work with k1 but you will have to drill a hole in the k1's back to put the screw in.
In the k1 max you just remove the back filament guide and you have he hole.

Horgul123, 2024-02-03:
ok. Thanks. Will check if I find a way without drilling a hole :)

Horgul123, 2024-02-04:
@Selberg666 : I've added a comment at printables. :)  I was able to install it, but need to do some modifications to avoid drilling a hole in the K1.

And a question:
Is there a trick to push the filament through the sensor? I have "some" problems pushing it through....
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
Selberg666, 2024-02-05:
Sooo.....after i conected the switch sensor to the tool head and rewrite the code i didn t have 1 false reading.
The sensor was mounted in the exact same position
I printed PLA,PETG,ASA.....i even printed a small keychain with TPU and i didn t have a problem
Diffrent prints with diffrent retractions.
And yes...the sensor works...i had 2 spool tangles and 1 filament runount.
Befor the switch sensor conect i had a lot of false detections.
Soooo just saying........do what you want...i just share my experience
IF the 2 sensors are not interacting with each other then why did they put them?Why not put just the encoder......that can do both tasks?I think there is a reason why!!!!

The-last-phantom, 2024-02-05:
Yes, there is a reason, but it's much less complex than what you are thinking. The reason is simply that not everyone wants to pause in the event of a motion error, some people want just a notification. Which is simply down to the fact that motion sensors will invariably give more false positives, it's just the nature of how they work. So some people want  a simple runout sensor that won't throw false positives to trigger a pause in the event of an actual runout, and a simple notification in the event of a motion issue.

The SFS V1.0 did have motion detection only, which also worked fine. They've obviously taken feedback onboard for the V2.0 and included a more simple switch.

Horgul123, 2024-02-05:
Ok. Thanks for the explanation. Then I will try to increase the detection length a little bit more.

nickboul, 2024-03-06:
Can I connect the sfs where the stock filament sensor is connected?

Horgul123, 2024-03-06:
> Can I connect the sfs where the stock filament sensor is connected?

Yes, but you can one use the runout OR the motion sensor, as you have only one port. I use the motion sensor and it works pretty well. Sometimes a false alarm, but not very often

The-last-phantom, 2024-03-06:
Yes, exactly. Pinouts are mentioned above.

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

anaegeli, 2024-04-14:
Hi all,
i was wondering, what connector did you use to connector on the mainboard and the toolhead.
Can you please tell me, so i can order the right connectors.
Thanks

The-last-phantom, 2024-04-14:
The toolhead uses 1.25mm pitch JST connectors.

The mainboard uses different connectors. I ended up just depinning the BTT
sensor connectors and plugging the pins directly onto the board without the
connector.

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

ViniSug, 2024-04-28:
> Hi all, i was wondering, what connector did you use to connector on the mainboard and the toolhead. Can you please tell me, so i can order the right connectors. Thanks

@anaegeli
K1 motherboard connector: **JST PH 2.0 3 pins**
K1 toolhead connector: **JST 1.25 3 pins**
BTT SFS v2 connector: **JST PH 2.0 4 pins**

BTT SFS cable: One side JST PH 4 pins, other side: dual JST XH 2.54 3 pins

anaegeli, 2024-04-28:
@ViniSug
thanks a lot!

nickboul, 2024-09-12:
> > Can I connect the sfs where the stock filament sensor is connected?
>
> Yes, but you can one use the runout OR the motion sensor, as you have only one port. I use the motion sensor and it works pretty well. Sometimes a false alarm, but not very often

And what lines should I use for my case?

nickboul, 2024-09-30:
I have tried every guide and cfg line I have found but I have not managed to make it work. Can anyone help me?

The-last-phantom, 2024-09-30:
Yep, how have you configured it and what is it doing?

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

nickboul, 2024-10-01:
I connected the green wire from the sfs to the existing data cable of the stock filament sensor.

Moreover I changed the following on the cfg:

[filament_motion_sensor SFS_motion_det]
switch_pin: !PC15
detection_length: 4
extruder: extruder
pause_on_runout: true

ps: I also tried without the ! on the pc15, with the runout gcode and 7 and 14 on the detection length.

On the wiring side I have the green on the data pin, ground on the middle and power on the last pin.

nickboul, 2024-10-04:
I found it. I had to reverse the pc10 pin. My working lines are.

[filament_switch_sensor filament_sensor]
pause_on_runout: True
switch_pin: PC15
runout_gcode:
  {% if printer.extruder.can_extrude|lower == 'true' %}
    G91
    G0 E30 F600
    G90
  {% endif %}

[filament_motion_sensor encoder_sensor]
switch_pin: nozzle_mcu:PA10
detection_length: 14
extruder: extruder
pause_on_runout: True
runout_gcode:
  {% if printer.extruder.can_extrude|lower == 'true' %}
    G91
    G0 E30 F600
    G90
  {% endif %}

You can correct your guide.

Thank you

FaintandFuzzies, 2025-05-25:
Can anyone help by providing the printer.cfg coding for a Creality K1 on the SFS V2.0.  One the K1, its not connected at the toolhead... its direct to the mainboard.  Thanks.

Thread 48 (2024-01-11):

How to install sfs 2.0 on a spider 2.3

llambion72, 2024-01-11:
I have a siboor voron 2.4 kit that it comes with spider 2.3 mcu. I bought a btt sfs 2.0.
Have anyone installed sfs 2.0 on this board?
Can anyone help me with mcu wiring?

m3cinc, 2024-03-30:
Have a look at https://www.youtube.com/watch?v=FNqQoJazBSE. In terms of adapting to the spider board, I have used on a v3.0 (similar to the v2.3 version) the X-MAX and Y-MAX inputs, since I use on my Voron 2.4R2 350 CAN and sensorless homing for the X and Y axes.
For Klipper configuration, I included sfs2.cfg in printer.cfg and placed in sfs2.cfg the following code:

[filament_switch_sensor BTT_sfs2]
switch_pin: ^PA1
# X-MAX on Spider v3.0
pause_on_runout: False
# When set to True, a PAUSE will execute immediately after a runout
# is detected. Note that if pause_on_runout is False and the
# runout_gcode is omitted then runout detection is disabled. Default
# is True.
runout_gcode:
#  PAUSE # [pause_resume] is required in printer.cfg
   M600
insert_gcode:
   LOAD_FILAMENT
event_delay: 3.0
# The minimum amount of time in seconds to delay between events.
# Events triggered during this time period will be silently
# ignored. The default is 3 seconds.
pause_delay: 0.5
# The amount of time to delay, in seconds, between the pause command
# dispatch and execution of the runout_gcode. It may be useful to
# increase this delay if OctoPrint exhibits strange pause behavior.
# Default is 0.5 seconds.

[filament_motion_sensor Encoder_sensor]
switch_pin: ^PA2
# Y-MAX on Spider v3.0
detection_length: 5
# anything over 2.88 per specs
extruder: extruder
pause_on_runout: False
runout_gcode:
   PAUSE
   M117 Filament Move Error Detected
insert_gcode:
   M117 Filament Move Restored

I believe you also need somewhere in printer.cfg a [pause_resume] block.

[pause_resume]
recover_velocity: 50.
#   When capture/restore is enabled, the speed at which to return to
#   the captured position (in mm/s). Default is 50.0 mm/s.

Hope this helps!

llambion72, 2024-04-10:
Thank you !! I'll try it

eugenim-atmega, 2024-04-12:
Hello!
Did you manage to install this device?
Were there any problems with connection and setup?
And also, X-MAX and Y-MAX, what is the voltage? Because for this device it is written that no more than 5 volts.
Thank You for answers.

eugenim-atmega, 2024-04-12:
OMG!
When I opened my eyes ))) look at this schem, i understand information about voltage. Its 3.3 volts. Sorry for stuped questions!
https://wiki.fysetc.com/images/Spider_V2.3_Pinout.jpg

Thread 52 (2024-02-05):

Many false positive errors

Horgul123, 2024-02-05:
I've installed the v2 sensor at my creality K1 (only the motion sensor As there is only one pin available) and I'm getting often false positive errors.
My detection length is 4.5mm and I'm printing PLA.
Any ideas?
Will try to increase the detection length after the current print, but too long could cause other issues when there is a real error 🫤

Fenrise, 2024-02-05:
That device is a crap. I cut out motion detection sensor feature from firmware and use it as normal (yet overly expensive) switch.

During my attempts encoder sensor worked at complete random. Stating "filament present" when there was no filament at all, or throwing random runouts few seconds after print starting. I was unusable, no matter what detection length I set in firmware. Many other people also had that issue, there need to be some flaw in its design.

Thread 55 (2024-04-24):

BTT Smart Sensor v2 Constantly triggering Switch Sensor

deadpickle, 2024-04-24:
I'm running the BTT smart Sensor v2 on a Voron 2.4 with klipper. When I print things seem to work correctly until some point where the switch sensor gets triggered. When I heat the hotend and extrude, without touching anything, the filament extrudes just fine, and I start the print. I then enter a spiral where the print will go for a time but then the switch sensor will trigger, stop, extrudes fine, and repeat. Is then sensor bad? Have I missed something?

Zephino, 2024-06-05:
change the detection_length to 3.88

`[filament_switch_sensor switch_sensor]
switch_pin: ^PA0
pause_on_runout: False
runout_gcode:
  PAUSE # [pause_resume] is required in printer.cfg
  M117 Filament switch runout
insert_gcode:
  M117 Filament switch inserted

[filament_motion_sensor encoder_sensor]
switch_pin: ^PC2
#detection_length: 2.88         #Stock
detection_length: 3.88          #Bappi
extruder: extruder
pause_on_runout: False
runout_gcode:
  PAUSE # [pause_resume] is required in printer.cfg
  M117 Filament encoder runout
insert_gcode:
  M117 Filament encoder inserted`

deadpickle, 2024-09-18:
This is for the encoder not the switch. I am still having this issue on and off

Closed 2024-09-19.

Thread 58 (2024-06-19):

SKR min E3 V3 and SFS 2.0 erroneous filament runout at start of print

tgreening, 2024-06-19:
I have the Smart Filament Sensor v2 connected to the SKR mini E3 v3 running Marlin bugfix-2.1.x. Whenever I start a print, usually during the nozzle wipe, I get a Filament Runout TO. After resuming it is fine. I cannot figure out why I am getting the filament runout at this point.

I have plugged in the coonections following page 13 in this document -https://github.com/bigtreetech/smart-filament-detection-module/V2.0/Manual/SFS V2.0 User Manual_20231123.pdf

I have configure Marlin according to this https://github.com/bigtreetech/smart-filament-detection-module

Here is my Configuration.h

`#define FILAMENT_RUNOUT_SENSOR
#if ENABLED(FILAMENT_RUNOUT_SENSOR)
  #define FIL_RUNOUT_ENABLED_DEFAULT true // Enable the sensor on startup. Override with M412 followed by M500.
  #define NUM_RUNOUT_SENSORS   1          // Number of sensors, up to one per extruder. Define a FIL_RUNOUT#_PIN for each.

  #define FIL_RUNOUT_STATE     LOW        // Pin state indicating that filament is NOT present.
  #define FIL_RUNOUT_PULLUP               // Use internal pullup for filament runout pins.
  //#define FIL_RUNOUT_PULLDOWN           // Use internal pulldown for filament runout pins.
  //#define WATCH_ALL_RUNOUT_SENSORS      // Execute runout script on any triggering sensor, not only for the active extruder.
                                          // This is automatically enabled for MIXING_EXTRUDERs.

  // Override individually if the runout sensors vary
  //#define FIL_RUNOUT1_STATE LOW
  //#define FIL_RUNOUT1_PULLUP
  //#define FIL_RUNOUT1_PULLDOWN

  //#define FIL_RUNOUT2_STATE LOW
  //#define FIL_RUNOUT2_PULLUP
  //#define FIL_RUNOUT2_PULLDOWN

  //#define FIL_RUNOUT3_STATE LOW
  //#define FIL_RUNOUT3_PULLUP
  //#define FIL_RUNOUT3_PULLDOWN

  //#define FIL_RUNOUT4_STATE LOW
  //#define FIL_RUNOUT4_PULLUP
  //#define FIL_RUNOUT4_PULLDOWN

  //#define FIL_RUNOUT5_STATE LOW
  //#define FIL_RUNOUT5_PULLUP
  //#define FIL_RUNOUT5_PULLDOWN

  //#define FIL_RUNOUT6_STATE LOW
  //#define FIL_RUNOUT6_PULLUP
  //#define FIL_RUNOUT6_PULLDOWN

  //#define FIL_RUNOUT7_STATE LOW
  //#define FIL_RUNOUT7_PULLUP
  //#define FIL_RUNOUT7_PULLDOWN

  //#define FIL_RUNOUT8_STATE LOW
  //#define FIL_RUNOUT8_PULLUP
  //#define FIL_RUNOUT8_PULLDOWN

  // Commands to execute on filament runout.
  // With multiple runout sensors use the %c placeholder for the current tool in commands (e.g., "M600 T%c")
  // NOTE: After 'M412 H1' the host handles filament runout and this script does not apply.
  #define FILAMENT_RUNOUT_SCRIPT "M600"

  // After a runout is detected, continue printing this length of filament
  // before executing the runout script. Useful for a sensor at the end of
  // a feed tube. Requires 4 bytes SRAM per sensor, plus 4 bytes overhead.
  #define FILAMENT_RUNOUT_DISTANCE_MM 3

  #ifdef FILAMENT_RUNOUT_DISTANCE_MM
    // Enable this option to use an encoder disc that toggles the runout pin
    // as the filament moves. (Be sure to set FILAMENT_RUNOUT_DISTANCE_MM
    // large enough to avoid false positives.)
    #define FILAMENT_MOTION_SENSOR

    #if ENABLED(FILAMENT_MOTION_SENSOR)
      #define FILAMENT_SWITCH_AND_MOTION
      #if ENABLED(FILAMENT_SWITCH_AND_MOTION)
        #define NUM_MOTION_SENSORS   1          // Number of sensors, up to one per extruder. Define a FIL_MOTION#_PIN for each.
        #define FIL_MOTION1_PIN    PC2

        // Override individually if the motion sensors vary
        //#define FIL_MOTION1_STATE LOW
        //#define FIL_MOTION1_PULLUP
        //#define FIL_MOTION1_PULLDOWN

        //#define FIL_MOTION2_STATE LOW
        //#define FIL_MOTION2_PULLUP
        //#define FIL_MOTION2_PULLDOWN

        //#define FIL_MOTION3_STATE LOW
        //#define FIL_MOTION3_PULLUP
        //#define FIL_MOTION3_PULLDOWN

        //#define FIL_MOTION4_STATE LOW
        //#define FIL_MOTION4_PULLUP
        //#define FIL_MOTION4_PULLDOWN

        //#define FIL_MOTION5_STATE LOW
        //#define FIL_MOTION5_PULLUP
        //#define FIL_MOTION5_PULLDOWN

        //#define FIL_MOTION6_STATE LOW
        //#define FIL_MOTION6_PULLUP
        //#define FIL_MOTION6_PULLDOWN

        //#define FIL_MOTION7_STATE LOW
        //#define FIL_MOTION7_PULLUP
        //#define FIL_MOTION7_PULLDOWN

        //#define FIL_MOTION8_STATE LOW
        //#define FIL_MOTION8_PULLUP
        //#define FIL_MOTION8_PULLDOWN
      #endif
    #endif
  #endif
#endif`

Any help is appreciated!

dean18kaufman, 2025-02-09:
having same issue. did you come up with a fix?

tgreening, 2025-02-09:
I increased the running value to 9mm and that seemed to do it. Weird it was that sensitive

Kenyiro34, 2025-03-29:
same

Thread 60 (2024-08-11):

BTT SFS 2.0 on rooted K1 Max in place of original sensor? Keeps throwing an error.

cmcfalls2, 2024-08-11:
Can someone help me with setting up a BTT SFS 2.0?

The following code "works" in the sense that I can print, but I keep getting false runouts causing the print to stop. I had to use the PC15 (rather than !PC15) in order to get the sensor to detect filament. It literally says filament is detected, but it still pauses the print for a runout. If I use !PC15 then it shows no filament detected, even though there is filament in the printer. Here's the working code:

[filament_switch_sensor filament_sensor]
switch_pin: PC15
pause_on_runout: true
runout_gcode:
  {% if printer.extruder.can_extrude|lower == 'true' %}
    G91
    G0 E30 F600
    G90
  {% endif %}

However, if I change the code to the following, then I get an error that states "pin PC15 used multiple times in config"

[filament_motion_sensor encoder_sensor]
switch_pin: PC15
detection_length: 3.2
extruder: extruder
pause_on_runout: true
runout_gcode:
  {% if printer.extruder.can_extrude|lower == 'true' %}
    G91
    G0 E30 F600
    G90
  {% endif %}

Why am I getting that error? I do NOT have multiple instances of PC15 in my config file. I've checked using a search. And besides, if I did, I would get that same error with the original code, but I do not. I'm just trying to use the sensor as a motion sensor (as opposed to a detection sensor) since no motion would equate to a runout or a clog.

Why the crap can't I get this sensor to work properly? I worked fine before I had to do a reset, and now I can't get it working!

lukasmejia, 2024-09-25:
if you have a rooted machine access ssh and run the helperscript command and make sure you don;t have installed #14 (M600 Support), remove it if so and check again with !PC15. also comment out this part on config.cfg:

[filament_switch_sensor filament_sensor]
switch_pin: PC15
pause_on_runout: true
runout_gcode:
{% if printer.extruder.can_extrude|lower == 'true' %}
G91
G0 E30 F600
G90
{% endif %}

ducati1198, 2025-02-05:
your using same pins for 2 different sensor better seperate them

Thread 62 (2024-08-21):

SFS v2.0 + SKR 1.4 Turbo + TFT35 E3 V3.0 How do I get work together if I print only from an SD-card on TFT35?

nen777w, 2024-08-21:
Not recently I purchased SFS V2.0 to avoid situations when filament can get stuck, or nozzle clogging.

Before that, I had experience using a simple filament sensor. I plugged it into TFT35 directly (not in SKR board) and this was the only way to get it working.
Because I print from TFT35, SD-card slot only.

TFT35 has only 3 pin slots for the Filament sensor,  but in the case of SFS v2.0 it has 4 pins.
The BTT recommends plugging it directly into the SKR, but I'm afraid that it will not work because as I mentioned above I print from the TFT35 SD-card slot. M'i right?

My question is:
Would that work for my usual printing case?

kimeschris, 2025-01-06:
Have you been able to get it working? I have the exact same setup and can't figure out how to make it work.

nen777w, 2025-06-16:
> Hello, I have this same detector but on the 70 tft screen and with the marlin supposedly well configured and I can't get it to work either, I think it may be a problem with the marlin or the board, can you help me, thanks in advance

I plugged it into my SKR 1.4 Turbo. It will not work if you plug it into the TFT screen.

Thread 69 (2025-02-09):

SFS v2.0 with Manta M8P - print pause just after wipeline.

krzysiekslimak, 2025-02-09:
I just install SFS v2.0 to my Voron with Manta M8P, I configure it as manual said. Senosors are available in system and looks like they working but every time print start, just after wipe line, the Encoder Sensor throw "runout" and print is paused.

Suraevivan, 2025-05-07:
You must calibrate your detection lenght in Printer.cfg file. Example in User Manual is 2.88 mm just sensor minimum value. You can't use so short distance. In my setup (with direct extruder without bowden tube from sensor to enter the extruder) detection lenght should be more than 50 mm. Try to +10, +20, +30 and more for your printer.

krzysiekslimak, 2025-05-08:
50mm? With this value it will print without filament for quite a long time and You will can't continue print. I leave 2,88mm but add in the print start macro code which turn off SFS2 at the begging and turn it on again after 5 seconds. Then it just work correctly.

Suraevivan, 2025-05-08:
You absolutely right, thats 50 mm only for my setup now, i will make it shorter later after install bowden tube and i think will set 5-10mm. I just mean you must try longer distances and sensor will work correctly.

Suraevivan, 2025-05-09:
Today a tested sensor with bowden tube from sensor to extruder and it works well with detection length 5 mm

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

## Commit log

2019-10-22 improve user manual
    [智能耗材检测模块-滑块0901.STL, 智能耗材检测模块-滑块1018.STL]
2019-11-27 update wire
2023-08-25 update sfs v2.0
    [SFS V2.0 Bracket for Hurakan.STEP, SFS V2.0 Bracket for Hurakan.STL, 智能耗材检测模块-外壳0918.STL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]
2023-11-16 add mods
    [SFS V2.0 Bracket for Ender3 V1.STEP, SFS V2.0 Bracket for Ender3 V1.STL, SFS V2.0 Bracket for Ender3 V2.STEP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]
2023-11-23 update v2.0 manual to fix wrong wiring
